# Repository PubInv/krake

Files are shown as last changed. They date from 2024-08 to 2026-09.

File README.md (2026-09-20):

<p align="middle">
  
   
</p>

# Krake™

## A wireless alarm device purpose-built for life's critical moments
The Krake, An Alarm Annunciator designed for easy integration into systems needing to bring to the attention of humans some condition. Can be used by professional system integrators and hobbyists.

This ?150? x ?180? x ?67? mm device has a speaker, a 20x4 character display, five white LEDs. It is a peripheral which can be controlled over a WiFi network using MQTT interface, a wired RS232 interface or a wired SPI interface with fully customiseable audio visual capabilitites. 

#### How it works?
1. A condition is detected by an external sensor that relays this information to Krake to trigger and alarm event. Such as a pressure sensor detecting the opening of a gate.
2. The Krake receives the information about the event wirelessly via MQTT over local network or internet. A gate open sensor on a security system would publish a message to the Krake via MQTT or direct RS232 connection
3. The Krake alerts you of this event-  Lights flash, audio plays and the message is displayed on an LCD for the user
4. The user is able to react to the alarm with {acknowledgement, dismissal, shelving or completion}, A mute button allows the user to temporarily mute the audio to prevent alarm fatigue.

## User Manual

A User Manual can be found [here](https://docs.google.com/document/d/1qrhc7Yi6PFmagl4gnvSoc0T4vC_uqu-NLrmWMKFnwA0/edit?usp=sharing).

## Table of Contents

- [Quick Start](#quick-start)
- [About Krake](#about-krake)
- [Example Use Cases](#example-use-cases)
- [Features](#features)
- [Hardware](#hardware)
- [Roadmap (Future Features)](#roadmap-future-features)
- [Contributing](#contributing)
- [Credits & Mentorship](#credits--mentorship)
- [Certifications](#certifications)
- [References & Further Reading](#references--further-reading)
- [License](#license)

## Quick Start
Once upon a time, we (Robert, Nagham and Lee) had envisioned that upon receiving a Krake the user would practice working with it by using the MQTT web page to publish messages to their device.

Purchasable from https://www.pubinv.org/shop/ 

User manuals & test and assembly procedure can be found in the references and further reading section 

#### LCD UI + navigation
 
Planned LCD Layout:

```text
Q:+ NEXT        W B M ⚙
CRIT Pump Failure
ID:123 Temp High
Ack  Dismiss  Shelve
```

Rotary Encoder: 
```text
Rotate: Navigate alarms or menu entries
Short Press: Select item
Long Press: Open Settings Menu
 ```

Alarm Actions:
```text
Rotatary encoder to enter action selection
Acknowledge, Dismiss or Shelve
 ```

Settings Menu: 
```text
The local settings menu includes:
* Volume Level
* Mute Duration
* COM Setup
* Device Reset
* Exit Menu
 ```
#### Build your own
To build your own please see instructions for testing and assembly of Krake hardware:
[Krake Test and Assembly Procedure Document](https://github.com/PubInv/krake/wiki/Krake-Test-and-Assembly-Procedure-Document)

## About Krake
The hope was to develop the initial design for a wireless alarm device to alert nearby parties of a particular state. 
About the name, Krake, the inspiration for the invention name is based on a Crake: a bird with a distinctive, slightly alarming cry. We changed the spelling so as to have a unique name and still preserve the humor. 

## Example Use Cases
Care at home: Alert an elderly person living alone to a fall or blood pressure drop — giving family peace of mind from anywhere.

Medical Equipment: For ventilators and critical devices, Krake provides a dedicated alarm channel for life-threatening mechanical failures.

IT Infrastructure: Alert on-site staff instantly when a server overheats, a UPS fails, or network connectivity drops — a physical alarm that doesn't rely on the very infrastructure it's monitoring.

## Features

| Feature | Details |
| --- | --- |
| Customiseable audio  |WAV and MP3 playback, Alarm-level-specific audio, Adjustable volume,SD-card-based audio storage, Busy-line monitoring and Runtime diagnostics |
| LCD User Interface & Rotary Knob | 20 x 4 I²C LCD interface integrated with a rotary encoder and custom menu system to navigate settings without the need for an external device.  Real-time alarm display, Wi-Fi status indication, MQTT broker status indication, Volume and mute display and Alarm acknowledgement actions |
| LED Annunciation  | Variety of LED levels  including steady or blinking deisgned to be visible across a room |
| Flexible Power | USB-C, 2.1mm center-positive barrel connector or RJ12 SPI interface power jumpers |
| Wi-Fi Connectivity | Acts as a Wi-Fi station connected to a local network enabling alerts locally or via internet, captive portal set up, storage of multiple Wi-Fi credentials, automatic reconnection, OTA firmware updates and Network status display |
| MQTT Protocol | MQTT alarm subscriptions, GPAP response publishing, Alarm acknowledgements, Alarm dismissal and shelving, Device monitoring, Configurable topic subscriptions and MQTT status display on LCD |
| Mute Button & time out handling | Configurable mute timeout, Automatic unmute, Manual mute override and LCD mute indication |
| HL7 Compatible | Designed to work with medical data standards |
| Fully Open Source | AGPL firmware, CERN OHL Hardware |
| Persistent COM configuration | Interfaces to external controllers through a DB9 Female RS-232 DCE connection. Configurable baud rate (1200,2400,4800, 9600, 19200, 38400, 57600, 115200), RTS/CTS hardware flow control and LCD-based configuration menu |
| Speaker | 3 inch 10W Full Range Round 8 ohm Speaker with FR:12-16KHz  |
| GPAP message parsing |  Alarm message are structured, message type, severity digit (0-5), optional message id, optional alarm type deisgnator and optional content up to 80 characters  |
| SPI alarm input support | ALlows processing of alert signals communicated or wired through SPI data lines to recognise fault or warning flags in connected sensors |  

## Hardware
| Krake™ rev2 | Krake™ rev1|
| --- | --- |
| |  |
| 3 inch 10W Full Range Round 8 ohm Speaker with FR:12-16KHz.| 28mm Speaker|
|dimensions|dimensions|
|functionality?|functionality?|

## Roadmap (Future Features)
* Advanced alarm queue management
* Enhanced LCD UI animations and icons
* Bluetooth and BLE alarm forwarding
* Mesh networking support
* Remote firmware fleet management
* Local event history logging
* Expanded GPAP/HL7 interoperability
* Power optimization modes
* Alarm escalation workflows

## Contributing
[Krake Workflow Contribution Procedure](https://github.com/PubInv/krake/blob/main/WorkflowProcedure.md)

## Credits & Mentorship
The Krake has been developed primarily by volunteer engineer Nagham Kheir, with mentorship and oversight from volunteer Inventional Coach Lee Erickson and a group of volunteers from around the globe. 

[Mentorship and Teamwork: The Story of the Krake](https://www.pubinv.org/2025/03/17/mentorship-and-teamwork-the-story-of-the-krake/)

Nagham Kheir: Invention Coach

Forrest Lee Erickson: Invention Coach

Robert L. Read: Invention Coach

Yehia Shalaby: Public Inventor

Courtney Ludick: Public Inventor

Yukti: Public Inventor

Juhandre Knoetze: Public Inventor

## Certifications



Krake hardware has been certified by the Open Source Hardware Association (OSHWA):
 OSHWA certification listing:
[OSHWA Certification Directory](https://certification.oshwa.org/list.html?utm_source=chatgpt.com)

Certification UID: ``` US002818 ```
 
## References & Further Reading

Brochure: [Copy of Krake Brochure.pdf](https://github.com/user-attachments/files/29981489/Copy.of.Krake.Brochure.pdf)

Logo: KRAKE 2

Krake Repo: https://github.com/PubInv/krake

Wiki: https://github.com/PubInv/krake/wiki

HardwareX Article: [ TBD]

User Manual: [draft user manual](https://docs.google.com/document/d/1qrhc7Yi6PFmagl4gnvSoc0T4vC_uqu-NLrmWMKFnwA0/edit?usp=sharing) 

Developers Manual: [draft developers manual](https://docs.google.com/document/d/150WA6Mb1_SFOBmFc9qBpT5b-MqXb7ejaZbKIxUqaDBY/edit?usp=sharing).

OSHWA certification listing:
[OSHWA Certification Directory](https://certification.oshwa.org/list.html?utm_source=chatgpt.com)

The team behind Krake: [Mentorship and Teamwork: The Story of the Krake](https://www.pubinv.org/2025/03/17/mentorship-and-teamwork-the-story-of-the-krake/)

Krake workflow: [Krake Workflow Contribution Procedure](https://github.com/PubInv/krake/blob/main/WorkflowProcedure.md)

Build your own: [Krake Test and Assembly Procedure Document](https://github.com/PubInv/krake/wiki/Krake-Test-and-Assembly-Procedure-Document)

Global Open Source Quality Assuring System:[Asset History Records Public Invention Krake Rev. 2](https://gosqas.org/record/8CMgkfrS4ufevweKy1QowF)

GPAP:  https://github.com/PubInv/gpap

#### Public Invention

- Github repo: https://github.com/PubInv
- Website: https://www.pubinv.org/
- Products page: https://www.pubinv.org/shop/

## License
Firmware: GNU Affero GPL 3.0

Hardware: CERN Open Hardware Licence Version 2 - Strongly Reciprocal

Krake™ is a trademark of Public Invention.

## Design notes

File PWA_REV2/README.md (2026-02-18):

# Summary
The Krake Rev 2 PWA fixes a major problem with the CH340 USB to UART feature of Rev 1 which was missing a crystal from the PCB and could not work.

## Document Descriptions
for some selected documents in this folder.  
The Rev2 PWA [Krake_Test_and_Assembly_Procedure.md](https://github.com/PubInv/krake/blob/main/PWA_REV2/Krake_Test_and_Assembly_Procedure.md)

## References
Link to issue capturing the order from PCBWay of PWA subassemblies.  
Link to issue capturing the order from other vendors of balance of BOM for PWAs.

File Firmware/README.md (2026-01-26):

# Summary 
These files are for firmware (for the most part into ESP32).
The GPAD_API is the firmware which will ship in the Krake.
Other files are for factory test / troubele shooting or were developed during to evaluate and understand hardware.

## Userfull link for compairing firmware branches
Jump to compareing on Github various commits.
https://github.com/PubInv/krake/compare

## Arduino IDE Settings and Libraries to Install
The IDE setting for board should be set to "ESP32 Dev Module".

Although we are migrating to VSCode and PlatformIO, For developing Firmware with the Arduino IDE the following libraries are required.
A number of libraries must be installed.  This is an incomplete list:
* ElegantOTA v. 3.1.7 by Ayush Sharma
* ESP AsyncWebServer by ESP32Async
* Async TCP by ESP32Async

(There are many other more common libraries.)

## Caution, Must Modify a Library
We use the Random Nerd Tutorials tutorial: [https://randomnerdtutorials.com/esp32-ota-elegantota-arduino/](https://randomnerdtutorials.com/esp32-ota-elegantota-arduino/) which gives instructions for changing 
the value of ELEGANTOTA_USE_ASYNC_WEBSERVER in ElegantOTA.h.

This value needs to be set to 1:
```
// WARNING! HACK FROM RANDOM NERD
#define ELEGANTOTA_USE_ASYNC_WEBSERVER 1

#ifndef ELEGANTOTA_USE_ASYNC_WEBSERVER
  #define ELEGANTOTA_USE_ASYNC_WEBSERVER 0
#endif
```

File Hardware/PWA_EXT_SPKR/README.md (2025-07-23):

# Summary
A printed wiring assembly for adding an external speaker jack to the Krake.

## Requirements Details.
See issue https://github.com/PubInv/krake/issues/231 (Hardware, Add External Speaker Jack (phone jack), 3,5mm, Switch ) for additional history on how these requirements evolved.

- A PWA which has a 3.5mm phone jack with switched signals.
The KRAKE audio output at J601 is connected into the PWA_EXP_SPK assembly on a 1.27mm JST connector.
When no 3.5mm plug is inserted into the jack, audio is available on an input 1.27mm JST connector for connection to the Krake internal speaker
The assembly is mounted to the Krake jack panel by the panel mount nut of the 3.5mm phone jack.

- Design For Manufacture
Design for manufacture by JLCPCB and PCBWAY.

## Impact On Other Assemblies
- **Front Panel Impact:** The Krake jack panel ?front panel? Must be modified by adding a 6mm hole (with clearance allowance) into which the 3.5mm phone jack will mount.
- **Internal Speaker:** Locate the speaker so that the leads that come with the speaker are long enough, OR build an extension cable assembly to connect to the speaker, OR extend the speaker wires.

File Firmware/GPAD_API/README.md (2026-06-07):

# Building

## PlatformIO IDE (Visual Studio Code Extension)
1. Install the Visual Studio Code (VS Code) text editor
    - [Website](https://code.visualstudio.com/)
2. Install the [PlatformIO](https://marketplace.visualstudio.com/items?itemName=platformio.platformio-ide) VS Code extension
    - The provided link has instructions on how install the extension in VS Code
3. The PlatformIO project needs to be opened
    - Click the PlatformIO logo/extension on the left tool bar
    - Under the `QUICK ACCESS > PIO Home` section, selection `Projects & Configuration`
    - At the top, select `Add Existing` and select this directory
4. To compile, select the PlatformIO logo/extension on the left again if it is not still selected
    - Under `esp32dev > General` select `Build` and the firmware image will be built
    - There are additional options for uploading the firmware to the device and monitoring

## PlatformIO from Command Line

Some users prefer not to use VSCode (those who prefer Emacs, Vim, subtext, etc.)

### PlatformIO Core (CLI) Installation
The official [documentation](https://docs.platformio.org/en/latest/core/installation/shell-commands.html#piocore-install-shell-commands) 
has great guide on how to install the CLI tooling. [Here](https://docs.platformio.org/en/latest/core/userguide/index.html#piocore-userguide)
is PlatformIO's guide on how to use the CLI command `pio`. The full guide for PlatformIO Core installation is available [here](https://docs.platformio.org/en/latest/core/installation/index.html). 

As the documentation says, you **do not** have to follow all steps in the CLI guide if you have **also** installed the VS Code extension, PlatformIO IDE. It will be advised to follow the directions under the documentation for "Install Shell Commands" to be able to run the commands `pio` and `piodebuggdb` anywhere in the terminal. For the `Makefile`
mentioned below, it is required to install the shell commands for the `make` command to function correctly.

### Build
In this directory, there is a `makefile`. If you have `make` installed, run `make` or `make build` to compile the firmware without requiring a connected device. The available targets are:

1. `build` --- compiles the firmware image. This is the default target used by `make`.
2. `upload` --- compiles and uploads the firmware image to a connected device.
3. `run` --- uploads the firmware image and begins running a monitor, which prints serial output and allows commands to be typed in, just as in the Arduino IDE.
4. `monitor` --- runs the serial monitor without uploading a new firmware image.

These commands are implemented on the command line as:

```
    make
    make build
    make upload
    make run
    make monitor
```

# Building LittleFS Filesystem
With PlatformIO, the creation of the `LittleFS` is a separate step from building the firmware image. However, it only has to be built if
there have been changes to the `/data` directory and it only has to be uploaded to the device if the the image has changed or the flash
pages containing the file system have been erased.

## PlatformIO IDE (VS Code Extension)
In the extension side panel, below the `General` section with the `Build` and `Upload` targets, there is another section, `Platform`. Under
the `Platform` section, there are the `Build Filesystem Image` and `Upload Filesystem Image`. Using the `Upload Filesystem Image` target will
build and upload the file system if the file system needs building.

## PlatformIO Core (CLI)
The full command is `pio run --target uploadfs` but the `Make` target `make uploadfs` can be used.

# Krake Installation
Installing/flashing a new firmware image requires the device, Krake, to be set into a state for it to allow a new firmware image. That can be accomplished with the following steps:
1. Connect Krake to power and to the computer
2. Press and hold the BOOT button.
3. While still holding BOOT, press and release the RESET button once.
4. Release the BOOT button.
5. The chip is now in boot mode. You can run your flasher and the port should respond.

# Runtime Connectivity and SPI Broker Mirror
WiFi credentials remain stored until explicitly cleared. Developers can clear saved WiFi credentials from the LCD `Developer Mode` menu or from the served settings page; the device then restarts into its normal WiFi setup flow.

Every topic/payload pair queued for MQTT publication is also queued independently for transmission from the Krake ESP32 VSPI controller. This keeps the local SPI output available even when WiFi or MQTT is offline. The controller uses a 1 MHz, MSB-first, SPI mode 0 link with `SCLK=18`, `MISO=19`, `MOSI=23`, and chip-select `SS=15`. Each transfer is one frame:

```
"KRK1" | retain byte | topic length byte | payload length byte | topic bytes | payload bytes
```

The built-in LED retains its heartbeat and adds connection indicators: two short winks after WiFi connects and three short winks after MQTT connects.

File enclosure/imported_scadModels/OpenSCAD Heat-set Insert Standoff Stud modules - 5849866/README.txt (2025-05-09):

OpenSCAD Heat-set Insert Standoff Stud modules by RonRN18 on Thingiverse: https://www.thingiverse.com/thing:5849866

Summary:
This is a collection of modules for OpenSCAD that will create different-sized standoff studs with holes for a heat-set insert to be placed into them. I have created modules for various sizes of standoff studs. I am still very new to OpenSCAD. While it has been around for many years, I first heard about it exactly one week ago. For the type of projects that I work on, and the way my brain works, this appears as though it will be much easier for me to design with as compared with the commercial product Fusion 360 that I started out with.Many of my designs are for cases to hold electronic projects, so I will need to create designs for holding circuit boards that have screw holes in a variety of places. To make installing, removing, and replacing parts easier, I like using these brass, heat-set, threaded inserts. Depending on the project, some times I need tiny little M2 screws and other times I may need a screw up to an M5. Each hole for an insert has an 8° tapered edge, to facilitate lining up each insert. The depth of each hole and the diameter of each stud varies based on what insert that is used. For this reason, I recreated several iterations of these standoff studs for the different sizes. Below are a list of the modules I've created.M2.0 ShortM2.0 LongM2.5 ShortM3.0 ShortM3.0 LongM4M5I may find a need later to create more sizes. If you open up the OpenSCAD file, you will see that I’m a bit verbose, but I explained how and why I did things the way I did.To call up one of the modules, you would use the following syntax:m3_long_stud(x-axis, y-axis, height of stud, offset from surface);The following is an example of this syntax:m3_long_stud(0,0,7.8,0);This places an M3 Long stud that is 7.8mm tall at 0,0,0. The values for each of these inserts were extrapolated from several different sources but mostly from Maker Tech Store and McMaster-Carr. Maker Tech Store provided better information on each of the inserts that they sell. Their only issue is they only sell some sizes. McMaster-Carr carries a larger variety but their information is a bit disjointed, often mixing imperial measurements with metric, like using a hole that is 0.199 inches for an M3 insert. Maker Tech Store explains it in details and provides an image to understand.

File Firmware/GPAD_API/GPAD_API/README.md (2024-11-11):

# GPAD_API
Description of the GPAD API, the Application Programming Interface.
Version 0.07
Updated on Date: 20221104

This is the description of the API from the point of view of the firmware within the General Purpose Alarm Device, aka the GPAD.

As of Version 0.07, the interface is through the USB serial and SPI, both. 
The serial BAUD rate is fixed at 115200
Serial messages are terminated with a single **Line Feed**, here after LF character (aka '/n' or New Line, which is ASCII 0x0A or DEC 10).
The GPAD recognizes a limited set of commands.
Some commands are one character only.
Some commands are two characters followed by the LF.
Some commands take messages by concatenating a message of up to 80 additional ASCII characters.

## The SPI Interface

The SPI interface was added in version 0.07, and example code for it is available in the GPAD_API_SPI_CONTROLLER directory. Please see the [README](https://github.com/PubInv/general-alarm-device/tree/main/Firmware/GPAD_API_SPI_CONTROLLER) there for more information.

This SPI-implemented is implemented with two entrypoints, the single funcation ```alarm```, and the function ```alarm_vent``` which takes and event structure. These may contain a null-terminated message string of up to
80 characters.
```C++
enum AlarmLevel { silent, informational, problem, warning, critical, panic };
// const char *AlarmNames[] = { "OK   ","INFO.","PROB.","WARN ","CRIT.","PANIC" };
const int NUM_LEVELS = 6;

const int MAX_MSG_LEN = 80;
const int MAX_BUFFER_SIZE = MAX_MSG_LEN + 1;
typedef struct {
                uint8_t lvl;
                // we will use a null-terminated string!
                char msg[MAX_MSG_LEN+1];
               } AlarmEvent;

int alarm_event(AlarmEvent& event,Stream &serialport);
int alarm(AlarmLevel level,char *str,Stream &serialport);
```

It is our intention to create additional entry points in what we call the "robotic_api" which will eventually explose all of the GPAD hardware to control by SPI.

## Display Description
The LCD is organized as four rows of twenty characters.
The first row displays the alarm level by number and name { "OK   ","INFO.","PROB.","WARN ","CRIT.","PANIC" }
The remaining rows display the message sent by the controller with commands detailed below.

## Command List
Summary:
Commands fall into categories of **Alarm** and **Mute** and a **Help** message.
Optional arguments are in [].
Commands are case-insensitive. **A0** and **a0** are the same.

### Alarm Messages
These have the form of a letter "A" and a digit 0-5 inclusive followed optionally by text for the message.
* A0[message for alarm level 0]
* A1[message for alarm level 1]
* A2[message for alarm level 2]
* A3[message for alarm level 3]
* A4[message for alarm level 4]
* A5[message for alarm level 5]

In addition to Alarm messages writing text to the LCD, the illumination of the five LEDs is also managed.  A0 lights no LEDs, A1 through A5 light successively more LEDS vertically up the GPAD.
There are fixed buzzer tones associated with each alarm level, A0-A5
The "A0" alarm level turns off the LCD back light.  All other levels turn on the LCD back light.
Some example alarm messages:
> a0 pseudoSerialVent Testing.  All is OK.
> a0Uh, everything's under control. Situation normal.
> a5LUKE, WE'RE GONNA HAVE COMPANY!

### Mute Messages
The GPAD has a buzzer which can be silenced or Muted by the API. (The user can also press a button to manage the mute state).
Mute messages are single character messages terminated by LF.
* S
* U

The S command **Silences** or mutes the buzzer.
The U command **Unmutes** the buzzer.

### Help
* H

The **H** message is single character messages terminated by LF.
The device will return a message out the serial port with help instructions.
Screen shot of the help message.


## Command Response and Status
After the GPAD receives a command, it returns text string with a response indicating status.
Example of response to the command "a0 pseudoSerialVent Testing.  All is OK."


## GPAD MUTE BUTTON
The GPAD has a mute button. Pressing the button will toggle the buzzer on and off.
Text is returned out the serial port indicating the MUTE status as OFF or ON.


# Software Organization

The files in the directory are organized to create as much modularity as possible
to make future enhancement easy. At present these are:

> alarm_api.cpp
> alarm_api.h
> gpad_serial.cpp
> gpad_serial.h
> gpad_utility.cpp
> gpad_utility.h
> GPAD_HAL.cpp
> GPAD_HAL.h

The "alarm_api" module is main application programmers interface; it is a very
high-level abstract alarm module.
The "gpad_serial" module handles serial communication of the alarm commands.
The "gpad_utility" contains mostly debugging routines needed by all other modules.
The "GPAD_HAL" is a low-level api concerning the specific API. It is means to
change more rapidly as the hardware evolves than the "alarm_api".
At the time of this writing I will shortly add an "spi" module

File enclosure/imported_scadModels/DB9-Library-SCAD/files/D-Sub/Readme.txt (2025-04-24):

D-Sub Library for OpenScad
--------------------------

Introduction
-------------

This library is designed as an easy way to cut out D-Sub connectors by simply adding width of the connector. I didn't like how some people use rectangular cutouts for Db-9 connectors and wanted to have an actual proper shape for aesthetic and practical reasons. I took the opportunity to learn a bit about OpenScad while making something useful.

Install
-------

Simply drag and drop the file into "libraries" folder in OpenScad or drag and drop the code into the code window.

Using This Library
--------------------
This libary ads a module called "dsub" that contains 3 parameters in this order: "Scale", "Connector Size", "Hight"

The scale will likely need to be made a little bigger to allow for different housings especially if your connector is female. 1.1 works well for db9 and 1.05 for db25. These are the only connectors I have on hand and those are what I tested. The connector size must corrolate to the largest width of the connector. See the chart below for some sample sizes. VGA and RS232 are DB-9/ HD DB-15 while Parallel ports are DB-25:

DB-9/HD DB-15 -- 17.04
DB-15 -- 25.37
DB-25 -- 39.09
DB-50 -- 52.93

Below is a fast poorly written script to test it.

include <dsub.scad>

difference(){
translate([-8,-20,1]){
    cube([20,100,3]);
}
dsub(1.1,17.04,10);
translate([0,50,0]){
    dsub(1.05,39.09,10);
}
}

Other Info
-----------

For more information on D-Sub conectors you can find a pretty good link below. I didn't create this site but found it useful in writing this script.
 
http://www.interfacebus.com/Connector_D-Sub_Mechanical_Dimensions.html

Warranty & License 
---------

This script is provided without any warranty and the user takes full responsability for it's use. This script is public domain.

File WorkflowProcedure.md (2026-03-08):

# Krake 
## Workflow

## Goals

* Every change is traceable to an issue.
* Small, reviewable branches.
* Clear validation (code or non-code).
* Works on both Windows and macOS.

## 0) One-time setup (Windows & macOS)

**Install Git**

* **Windows:** Install “Git for Windows” (use **Git Bash**), include **Git Credential Manager**.
* **macOS:** `xcode-select --install` (or `brew install git` if you use Homebrew).

**Configure Git**

```bash
git config --global pull.rebase true
git config --global fetch.prune true
git config --global init.defaultBranch main
git config --global user.name "Your Name"
git config --global user.email "you@example.com"
```

**Line endings (important cross-platform)**

* **Windows (Git Bash):** `git config --global core.autocrlf true`
* **macOS/Linux:** `git config --global core.autocrlf input`

**Clone**

```bash
git clone https://github.com/PubInv/krake.git
cd krake
git remote -v
```

> Use **Terminal** (macOS) or **Git Bash** (Windows). VS Code’s built-in terminal works on both.

## Roles

* **Mentor:** creates & assigns issues, reviews PRs, **merges**.
* **Contributor (Volunteer):** works **only** on assigned issues, opens PR, updates per review.
* **Maintainer:** sets repo guidelines (branch protection, labels, templates, CODEOWNERS).

 -----

## 1) Issues 
* Mentors create & assign issues to contributors.
* Each issue includes:

  * **Goal & Acceptance criteria**
  * **Deliverables** (e.g., STL/STEP, schematic PDF/BOM diff/DRC, docs, scripts, code)
  * **Validation method** (how we verify—simulation, screenshots, photos, logs, ERC/DRC/print-fit, etc.)
* Contributors can create issues and assign them to mentor(s) at any time. However, the mentor or team lead should set priorities, and therefore should assign issues to contributors most of the time (contributors may complete obvious issues if it makes sense by assigning the issues to themselves). 

### Issue Criteria (for when a contributor is creating an issue)

issue [type]: Firmware, Enclosure, Documentation... 

## 2) Create a branch (from `main`)

Navigate to the issue in Github and use the user interface to create a branch, by scrolling the Development section.



### Branch Naming
**Naming:** `type/issue-<number>-short-slug`
Types: `feature`, `bugfix`, `docs`, `cad`, `pcb`, `chore`, `refactor`

Then locally: 

```bash
git fetch origin
git checkout -b cad/issue-312-speaker-mount-v2 origin/cad/issue-312-speaker-mount-v2
```

## 3) Work locally  

Keep commits small and focused.

**Commit message style**

* For code: Conventional Commits
* For CAD/PCB/docs: plain but specific is fine

Examples:

```
cad(enclosure): add 2mm standoffs for DFPlayer (#312)
pcb(audio): reroute SPK +/- to reduce crosstalk (#287)
docs(factory-test): clarify rotary encoder checklist
```

**Artifacts & folders**

* Put source and **exported, viewable** artifacts together (e.g., PDF/PNG for schematics, STL/PNG for CAD).
* Typical folders: `firmware/`, `hardware/enclosure/`, `hardware/pcb/`, `docs/`.

Push often:

```bash
git add -A
git commit -m "cad(enclosure): add 2mm standoffs for DFPlayer (#312)"
git push
```

> Validation can be **anything appropriate**: screenshots, DRC/ERC reports, test photos, simulation results, print fit notes, logs, etc. We don’t assume a build/compile exists.

## 4) Open a Pull Request (Contributor)

On GitHub:

* **Title:** What changed + issue number
  e.g., “Enclosure: add 2 mm standoffs (Closes #312)”
* **Description must include:**

  * **What & why**
  * **Validation steps** (how to verify)
    *Examples:* “ERC/DRC screenshots attached”, “Print test part A—fits DFPlayer with 1.5 mm clearance”, “Photo of assembled prototype”, “Serial log shows expected event”
  * **Artifacts attached** (PNGs/PDFs/STLs/log snippets)
* **Link issue:** `Closes #<n>`
* **Reviewers:** your **mentor(s)** only
* **Labels:** match the issue (`cad`, `pcb`, `docs`, `firmware`, etc.)

**PR checklist (paste into PR):**

## PR Template: 

```

## Links
- [ ] Closes #<issue>

## What & Why
-

## Validation / How to Verify
1.
2.

## Artifacts (attach if relevant)
- [ ] Screenshots / PDFs / STLs
- [ ] Logs

## Checklist
- [ ] Only related changes
- [ ] Folder structure respected, work directory. 
- [ ] Validation steps written
```

Use **Draft PR** if not ready.

## 5) Review & iterate

* Mentor reviews, requests changes or approves.
* Add follow-up commits; **don’t force-push** unless mentor asks.
* Resolve comments with “Fixed in `<short-hash>`” or rationale.

## 6) Merge (mentor-only)

* Only a **mentor** merges.
* **Strategy:** **Squash & merge** to keep history clean/complete.
* After merge: branch deleted, issue auto-closes via `Closes #<n>` (close manually if needed).

## 7) Sync after merge

```bash
git checkout main
git pull
git fetch --prune
```

## 8) Hotfixes (urgent)

* Branch from `main`: `hotfix/issue-<n>-slug`
* Same PR/review flow; mentor merges once validated.

---

## Branch protection for `main`

**What:** Rules that prevent direct pushes and enforce quality gates before merging.

* Restrict deletions
> Only allow users with bypass permissions to delete matching refs.

* Require a pull request before merging
> Require all commits be made to a non-target branch and submitted via a pull request before they can be merged.
> Require **1 approving reviews** (mentors)

* Block force pushes
> Prevent users with push access from force pushing to refs.

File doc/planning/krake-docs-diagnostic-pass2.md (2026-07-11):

# Krake Documentation — Second-Pass Diagnostic Analysis

> **Relationship to pass 1:** this is a direct continuation of `krake-docs-diagnostic-pass1.md` (see that file's permalink in the team's GitHub issue for the original). It incorporates: the switch from the abandoned LaTeX Test and Assembly Procedure Document to the current GitHub-native Markdown version, all fact-conflict resolutions reached since pass 1 (PWA/enclosure dimensions and mass, PCB Rev 2.0 / PWA Rev 2.1 naming convention, journal name confirmation), and new findings surfaced by reviewing the current Markdown Assembly doc directly. Items marked **RESOLVED** below were open questions in pass 1 and are now settled; items still open are unchanged or newly added.

> **Correction incorporated in this pass:** the original pass 1 analyzed the LaTeX/Overleaf version of the Test and Assembly Procedure Document, which the team has since confirmed was **abandoned** in favor of a GitHub-native Markdown document. This pass replaces that source and re-checks every finding that touched it. The old LaTeX doc should not be treated as authoritative for anything going forward.

**Sources reviewed:**
1. GitHub README.md (`PubInv/krake`)
2. Krake™ User/Operator Manual v0.1 (Google Doc)
3. Krake™ Developer's Technical Manual v0.1 (Google Doc)
4. HardwareX article draft (Overleaf, LaTeX)
5. **Krake Test and Assembly Procedure Document v0.2.0** — `PWA_REV2/Krake_Test_and_Assembly_Procedure.md` on GitHub (`main` branch) — ~~formerly the Overleaf LaTeX version, now abandoned~~

This is a diagnostic pass only — no rewriting yet. Goal is to surface conflicts, gaps, and structural
issues so we can agree on a fix order before touching prose.

---

## 1. Fact conflicts requiring a team decision

These are places where two or more documents state something different, and only the team can say
which is correct.

| Item | Source A | Source B | Notes |
|---|---|---|---|
| ~~**Physical dimensions**~~ **RESOLVED** | Developer Manual: "160mm x 110mm x 50mm (6"x4.25"x1.75"), weighs 232 grams" | HardwareX §7.3: "weighs less than 740 grams. Dimensions are: 150 x 180 x 90 mm" | **Not a documentation error — two real hardware states.** The 232g/160x110x50mm figure describes the **Rev1** enclosure with a 28mm speaker (too quiet, since retired). The Rev2 enclosure was enlarged to fit a 3" speaker for adequate volume, raising both size and mass. **Confirmed current Rev2 measurements (re-measured for parallax error): enclosure body 150mm x 180mm x 67mm, mass 742g; overall depth at the rotary encoder knob is 78mm.** HardwareX's "90mm" was an early rough estimate — supersede with 67mm (body) / 78mm (at knob). **Action:** Developer Manual should carry the Rev2 figures as current spec; the Rev1 232g figure should only remain if explicitly labeled historical/reference-only per the team's rev1 policy. |
| ~~**Power draw**~~ **RESOLVED — not a conflict, different purposes** | Developer/User Manuals: "9-12VDC... less than 500 mA and typically 250mA (less than 6 watts)" — this is a **purchasing spec** for the external wall-wart power supply an end user or integrator needs to buy. | Assembly Doc: bench supply set to 8–12V, current limit <1A, typical measured draw **150–190 mA** at 8.3–8.4V — this is a **test-bench setup spec**, deliberately run near the minimum voltage the onboard regulators need, accounting for regulator headroom and the drop across the reverse-polarity protection diode. | **Not a discrepancy to reconcile — two different documents answering two different questions**, so the numbers don't need to match and shouldn't be forced to. **New action item:** the Assembly doc's bench-supply setup step doesn't currently explain *why* the minimum test voltage is set where it is. Worth adding a short explanation there (regulator headroom + reverse-polarity diode drop) so a technician understands the rationale, not just the number — this also protects against someone "helpfully" changing the test voltage in a later revision without understanding why it's set near the floor. |
| **Firmware version** | README: firmware at **v0.50.0** | Developer Manual screenshot: `GPAD_API 0.19_20241119` | Big gap (0.19 vs 0.50.0). Developer Manual example is clearly stale and needs a refreshed screenshot/output. |
| ~~**PCB revision**~~ **RESOLVED, and partially already fixed** | Assembly Doc §4 (Definitions) **already defines PCB vs. PWA correctly**: "PCB: ...to which electronic components are NOT yet attached" / "PWA: ...a PCB with components soldered/attached." Good — this matches the team's agreed convention below, no work needed there. | **However, the inconsistency in applying that distinction persists in the current Markdown doc**, not just the old LaTeX one: the "Unpacking" section says "Confirm PCB is marked as **Rev 2.0**," while "Incoming Sub-assembly Inspection" (a few lines later, same doc) says "Confirm PCB is marked as **Rev 2.1**." The top-level doc title is also still "Krake: PCB Rev 2.1," and body text says "This article focuses on the **Rev 2.1 PCB**..." — which directly contradicts the agreed PCB 2.0 / PWA 2.1 convention. | **Team convention (confirmed):** **PCB Rev 2.0** = the bare board actually fabricated (design started ~Aug 2025, populated Jan 2026 batch). **PWA Rev 2.1** = PCB Rev 2.0 + enclosure + speaker + cable assembly + label — the complete assembled/tested unit. PCB Rev 2.1 (in-progress silkscreen/BOM refinement) has **not been released** and should not appear as describing built hardware. **Action, still open:** the Assembly doc's title, its "This article focuses on the Rev 2.1 PCB..." line, and the "Confirm PCB is marked as Rev 2.1" instruction all need to change to reflect PCB 2.0 / PWA 2.1 — the definitions are already in the doc, they're just not applied consistently yet. Same fix needed in the HardwareX draft's build section (see new item below on HardwareX build-section staleness). |
| **Unit serial range tested** | HardwareX §1: batch described as **US0006–US00015, LB0006–LB00011, LDN0001–LDN0005** | The current Markdown Assembly doc **does not state a specific serial range** in the sections reviewed — this appears to have dropped out rather than contradicted. | No longer a cross-document conflict, but still an open question: does the HardwareX-stated batch range reflect the units actually referenced by the current procedure doc? Worth confirming before submission. |
| **Powered TP102 (Vin) reading** | Confirmed still present, unchanged, in the current Markdown doc's powered-test results table: "TP102 | ~4.5V" | The 8.3–8.4V bench supply and other readings suggest ~4.5V is anomalously low for this rail. | Not a copy artifact from the abandoned LaTeX doc — this is a live number in the current, authoritative procedure. Worth double-checking with whoever ran that test batch. |
| **Author list (Assembly/Test doc)** | Current Markdown doc lists **three authors**: Forrest Lee Erickson, Nagham Kheir, and **Courtney Ludick** (added since the abandoned LaTeX version, which listed only Erickson and Kheir) | HardwareX draft lists **six authors**: Nagham Kheir, Robert L. Read, Forrest "Lee" Erickson, Courtney Ludick, Juhandré Knoetze, Yhya Ayman | Closer alignment than before, but still not identical — confirm whether the Assembly doc's list is meant to be a subset (contributors to that specific document) before finalizing the CRediT statement. |
| **Internal date typo (new finding)** | Assembly doc's ISO title page block: "Date: **2027 - 02 - 08**" | Same document's Revision History table: v0.2.0 dated **2026-02-08** | Almost certainly a typo (2027 vs 2026) in the ISO title page block. Easy fix, worth catching before publication. |
| **Ordering price** | Developer Manual: "approximately $200USD," contact Robert Read directly | Not mentioned in README or HardwareX | Confirm this is still current before it goes in a permanent, indexed HardwareX article. |
| **OSHWA certification UID** | HardwareX specs table: `US002818` | Not mentioned in README, User Manual, or Dev Manual | Should probably be surfaced in the README and User Manual too, since it's a credibility signal for new visitors. |
| **Trademark usage** | User/Dev Manuals: consistent "Krake™" | README / HardwareX: plain "Krake," no ™ | Needs a house-style decision (see §3). |

---

## 2. Structural / completion gaps

**New finding (missing content, not a conflict): VESA mount and mounting orientation are undocumented.**
The enclosure has a **75×75mm VESA MIS-D mount** feature on the back (referenced only implicitly, as "VESA and Speaker Mount" threaded inserts, in the Assembly doc's Enclosure Assembly Procedure — never explained as a user-facing feature anywhere). None of the User Manual, Developer Manual, README, or HardwareX draft mention it. This is a real gap, not a drafting error, and it has a usability/safety dimension:
- The existing "Enclosure / Device Mounting" sections (User Manual, Developer Manual) describe a central mounting hole, side picture-hanging holes, and zip-tie flanges — but never the VESA pattern, and never state that the Krake is designed for **vertical surface mounting only**.
- Cables exit from the panel a user would likely perceive as the "bottom" (the side perpendicular to the LCD/front face) — which is not an obvious consequence of the design and isn't called out anywhere.
- **Action:** add a mounting-orientation **safety/best-practice note** — not just a spec line — to the User Manual and Developer Manual mounting sections: name the **75×75mm VESA MIS-D** pattern explicitly, state that the Krake is designed for vertical surface mounting only, and warn against setting the unit flat on a horizontal surface, since cables exit from that face and the enclosure isn't designed to bear load or rest stably on it.

**HardwareX article** — this is the least finished document and has the most template debris:
- The Abstract section still contains **unresolved editor/reviewer comment text** bleeding into the visible body (e.g., stray fragments like "not in template," "graphical abstract," mid-sentence interruptions). This reads as corrupted or improperly-resolved tracked changes/comments from Overleaf/Word round-tripping, and needs a clean rewrite pass before anything else in that document is touched.
- Several section headers still contain the **unmodified HardwareX instructional text** ("Write a short description...", "Add 3–5 bullet points...") mixed in with actual content — a sign these sections were drafted directly into the template without deleting the prompts.
- **Ethics statement, CRediT statement, Acknowledgements, References, "Useful References," Design Files table costs** are explicitly marked TBD, placeholder, or contain obvious placeholder values (e.g., BOM costs listed as `1000000` for the enclosure and PCB — clearly a formatting artifact, not real costs).
- §7 (Validation) has three subsections (Sound/Light, Electrical Parameters, Physical Parameters) that are almost entirely TBD, tagged to specific people ("TBD: Lee," "TBD: Lee, Courtney").
- The reference to "the Krake, the Zetron SentriMax" comparison seems to have an editor comment ("Missing is a comparison...") embedded directly in the body text.

**Developer Manual:**
- Multiple `TBD` and `????` placeholders in the Wireless Connection section (default password, exact button to hold for WiFi Manager, etc.) — this is core setup instructions for a real user, so these gaps block someone from actually using the device.
- "Communicating with the Krake" section literally says "TODO: Write this section in reference to the diagram below" — the diagram exists but the explanatory text was never written.
- Python MQTT example section says "TO BE DONE: NAGHAM ADD PYTHON CODE HERE."
- SPI Interface connector type is marked "TBD."
- Note this manual is dated/versioned as v0.1 — it may be the least mature of the four, other than the HardwareX draft.

**User Manual:**
- Shares roughly 70% of its content verbatim with the Developer Manual (Wireless Connection, Mute Button, Rotary Encoder, Ordering sections are nearly identical). This isn't necessarily wrong — some overlap is expected since they share an audience for some topics — but right now it looks like duplication-by-copy-paste rather than an intentional shared-content strategy. Worth deciding: cross-reference instead of duplicate, or keep parallel but ensure they never drift again.
- Same `????` and TBD gaps in the WiFi Manager section as the Developer Manual (since it was copied from there).

**Assembly & Test Procedure Document (now on `main`, `PWA_REV2/Krake_Test_and_Assembly_Procedure.md`):**
- **This is a materially more advanced document than what was in the abandoned LaTeX version**, and more advanced than what's reflected in the HardwareX draft's embedded build section. New content not present anywhere else includes:
  - A full **Factory Test Procedure** with a structured hex-menu test suite ([0]–[F]: Power/ID, Inputs, LCD, LEDs/Lamps, DFPlayer, SD, Speaker, Wi-Fi AP, Wi-Fi STA, LittleFS, UART, SPI loopback, RS-232 loopback, **ElegantOTA**, Mute Button+LED) — this supersedes the old, much simpler "enter 4-5-6 into the serial monitor" test flow.
  - A complete **Enclosure Assembly Procedure** (3D-printed part list, threaded-insert installation, full step-by-step mechanical assembly) that doesn't exist in the HardwareX draft or the old LaTeX doc at all.
  - Real BOM costs (e.g., PCB $35/5, subassembly $217/5) replacing the old placeholder values (`1000000`) — the HardwareX draft's BOM table should be checked against this and updated, since it still likely has the placeholder figures.
  - A firmware update workflow via **ElegantOTA** (`.bin` upload) replacing the old direct-flash-only description.
  - Reference to a live GitHub Issue (#274) for firmware library specifications — a good sign of the team already using issues for exactly this kind of drift control.
  - A third author, Courtney Ludick, credited on the document (see fact-conflict table above).
- Still carries **ISO template scaffolding** at the top (Background, Results/Discussion, References, Appendix headers) that remain unfilled — same issue as before, not yet resolved by the update.
- Revision history table still has a `YYYY-MM-DD [Author Name]` placeholder row for the future v1.0.0 "Finalized for publication" entry.
- Ends abruptly with "Ethics statements / CRediT / Acknowledgements / References — To be completed" — same as before.
- **Still has the PCB Rev 2.0/2.1 inconsistency** discussed above, even in this updated version — the definitions in §4 are correct, but the applied labels in the body aren't consistent with them yet.
- **New, higher-priority finding: the HardwareX draft's embedded Build Instructions section is now significantly more out of date than previously assessed.** It was already showing signs of drift from the old LaTeX Assembly doc; now that the real procedure has moved to a substantially expanded, GitHub-native document, the gap is much larger — entire sections (Factory Test menu, Enclosure Assembly, ElegantOTA workflow) exist only in the Markdown doc and aren't reflected in the HardwareX draft at all. **Recommendation: when we get to the HardwareX Build Instructions section, treat it as needing significant new content pulled in from the current Markdown doc, not just a terminology/label fix.**

**README:**
- Most current and complete-feeling document. Good candidate as the "source of truth" for high-level facts (firmware version, feature list, licensing) that other docs should defer to or link to rather than restate.

---

## 3. Voice, terminology, and style drift

- **Trademark symbol**: User/Developer Manuals use "Krake™" consistently; README and HardwareX draft do not. Pick one house style — likely "Krake™" on first mention per document, plain "Krake" thereafter, matching normal trademark convention — and apply everywhere.
- **Point of view**: Manuals mix "we," "the Alarm Developer," "you," and third-person "the Krake" within the same paragraph. HardwareX draft is more consistently third-person/passive, as academic style expects. You've said you want a "we" team voice — that's very workable for the manuals and README, but note HardwareX has its own required conventions (more formal, methods-paper register) that shouldn't be fully "we"-ified in the same way — it already uses "we" in places, which is normal for HardwareX articles, so this is really just about consistency, not a wholesale voice change.
- **Product name capitalization/quoting**: "Krake™," "Krake," and "the Krake" (with article) are all used interchangeably, sometimes in the same sentence. Worth a simple style rule (e.g., always "the Krake" when used as a common noun, "Krake™" only on first mention in a document).
- **Author voice fingerprints**: A few passages read as clearly personal/first-person aside rather than team voice, e.g., Developer Manual: *"Lee thinks that the card should NOT be removable without disassembly..."* — this is useful institutional knowledge but needs to be converted to team voice and a stated decision, not attributed to one person by first name in a public document.
- **Redundant/parallel content**: the "Krake™ Purpose," Mute Button, Rotary Encoder, Wireless Connection, and Ordering sections are near-duplicates across User Manual and Developer Manual — same content, tiny wording differences. This is the clearest sign of multiple contributors solving the same problem independently.

---

## 4. What I'd recommend as the fix order

1. **Resolve the flagged fact conflicts** (§1) with the team — I can't guess these; they need a person who has the physical hardware in hand or the git history of the specs. *(Several already resolved through this conversation — dimensions/weight, PCB/PWA convention, journal name.)*
2. **Fix the HardwareX draft's structural debris** (stray comment text, unresolved template instructions) — this document is closest to being reviewed by an external editor and currently wouldn't pass a first read.
3. **Import current content into the HardwareX Build Instructions section from the authoritative Markdown Assembly doc** — this is now a bigger job than originally scoped. The HardwareX draft's build section reflects an old, abandoned version of the procedure; the Factory Test menu, Enclosure Assembly steps, and ElegantOTA firmware workflow all need to come across, not just get relabeled.
4. **Decide the User Manual / Developer Manual overlap strategy** — merge-and-cross-reference vs. intentional duplication — before doing any voice/style pass, since it changes how much rewriting is needed.
5. **Do the "we" voice and terminology pass** last, once facts and structure are settled, so we're not polishing prose that's about to change.

## 5a. Backlog — related but out of scope for this documentation pass

- **Schematic/KiCad project has no PWA-level revision field** — only PCB revision is currently tracked in the design files. Now that a PCB/PWA dual-numbering convention exists (see §1, PCB revision), it would be worth adding a PWA revision annotation directly to the schematic or project metadata so this doesn't have to be reconstructed from memory or documentation archaeology next time.
  - **Additional complicating history (for whoever picks up this ticket):** the schematic version was incremented to 2.1 around the same time PWA changes began, and a 2.1 PCB was created with silkscreen changes — but no footprint or copper changes are believed to have been made at the PCB level. Separately, the KiCad project files were corrupted at some point and had to be reverted to an earlier commit; as of this writing, both the schematic and PCB show as **Rev 2.0** again. There may be intermediate commits that preserve the 2.1 changes, but this has not yet been checked. **Not in the critical path for the HardwareX article** — noted here so it isn't lost, but doesn't block the documentation work.
  - Suggested as a GitHub issue for after the documentation work.

- **Product naming strategy for multi-use Krake hardware (new, strategic — flagged by team, not a documentation defect).** The Krake hardware platform is general-purpose; firmware developed so far targets the alarm-annunciator use case, but the team has discussed a second application: using the same hardware as a controller/HMI for PolyVent (Public Invention's open-source ventilator, which currently has no user interface and is laptop-controlled only). No name yet exists for this second application.
  - **Recommendation discussed:** decouple the hardware platform identity ("Krake") from the identity of each firmware-defined application built on it. Keep "Krake" as the name of the physical hardware/enclosure/PCB platform (as already documented), and give the PolyVent-controller application its own distinct product name and documentation trail, explicitly described as "built on the Krake hardware platform" rather than as a mode or variant of Krake itself.
  - **Why this matters more than a typical naming choice:** unlike the alarm-annunciator use case, a PolyVent controller is a component of respiratory life-support equipment. Medical device regulatory frameworks (e.g., FDA 510(k)) generally treat a device with a different intended use as a different device for regulatory purposes — same hardware, different firmware/intended use, means separate classification, labeling, and documentation requirements are likely down the line. Establishing separate product identity now, before firmware exists, avoids having to retroactively disentangle "Krake" (general-purpose, no medical claims) from a future medical-context product sharing its name.
  - **Not in the critical path for the HardwareX article** — the HardwareX submission concerns the alarm-annunciator hardware/firmware as it exists today, and doesn't need to resolve this naming question. Noted here so it isn't lost, and so it's on record before any PolyVent-controller firmware or documentation work begins.
  - Suggested next step: loop in whoever manages PolyVent's regulatory/quality strategy early, since the naming decision is small relative to the eventual compliance path but easier to get right from the start than to fix later.

## 5. What I need from you to proceed

- Decisions on the six items in §1 (or confirmation that some are fine as-is / intentionally different states of the device).
- A call on the User/Developer Manual duplication strategy.
- Confirmation of fix order, or reprioritization if you'd rather start with the HardwareX article since it may be closer to a submission deadline.

Once you've weighed in, I can start on whichever document you want to tackle first — my suggestion would be the HardwareX article's Abstract and structural cleanup, since that's blocking the most.

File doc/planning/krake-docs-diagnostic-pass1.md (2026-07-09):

# Krake Documentation — First-Pass Diagnostic Analysis

**Sources reviewed:**
1. GitHub README.md (`PubInv/krake`)
2. Krake™ User/Operator Manual v0.1 (Google Doc)
3. Krake™ Developer's Technical Manual v0.1 (Google Doc)
4. HardwareX article draft (Overleaf, LaTeX)
5. Krake Test and Assembly Procedure Document v0.1.0 (Overleaf, LaTeX)

This is a diagnostic pass only — no rewriting yet. Goal is to surface conflicts, gaps, and structural
issues so we can agree on a fix order before touching prose.

---

## 1. Fact conflicts requiring a team decision

These are places where two or more documents state something different, and only the team can say
which is correct.

| Item | Source A | Source B | Notes |
|---|---|---|---|
| ~~**Physical dimensions**~~ **RESOLVED** | Developer Manual: "160mm x 110mm x 50mm (6"x4.25"x1.75"), weighs 232 grams" | HardwareX §7.3: "weighs less than 740 grams. Dimensions are: 150 x 180 x 90 mm" | **Not a documentation error — two real hardware states.** The 232g/160x110x50mm figure describes the **Rev1** enclosure with a 28mm speaker (too quiet, since retired). The Rev2 enclosure was enlarged to fit a 3" speaker for adequate volume, raising both size and mass. **Confirmed current Rev2 measurements (re-measured for parallax error): enclosure body 150mm x 180mm x 67mm, mass 742g; overall depth at the rotary encoder knob is 78mm.** HardwareX's "90mm" was an early rough estimate — supersede with 67mm (body) / 78mm (at knob). **Action:** Developer Manual should carry the Rev2 figures as current spec; the Rev1 232g figure should only remain if explicitly labeled historical/reference-only per the team's rev1 policy. |
| **Power draw** | Developer Manual: "9-12VDC... less than 500 mA and typically 250mA (less than 6 watts)" | Assembly Doc: bench supply 8–12V, current limit <1A, typical measured draw **150–190 mA** at 8.3–8.4V | Numbers are in the same ballpark but don't match. Assembly doc numbers are actual measurements from real units, so they're probably more trustworthy — Developer Manual reads like an earlier estimate. |
| **Firmware version** | README: firmware at **v0.50.0** | Developer Manual screenshot: `GPAD_API 0.19_20241119` | Big gap (0.19 vs 0.50.0). Developer Manual example is clearly stale and needs a refreshed screenshot/output. |
| ~~**PCB revision**~~ **RESOLVED** | Assembly Doc, page 1: "Confirm PCB is marked as **Rev 2.0**" | Same document, a few paragraphs later: "Confirm PCB is marked as **Rev 2.1**" (in both the standalone doc and the HardwareX-embedded version of the same section) | **Not a simple typo — a PCB-vs-PWA conflation.** Team convention going forward: **PCB Rev 2.0** = the bare board actually fabricated (design started ~Aug 2025, populated Jan 2026 batch). **PWA Rev 2.1** = PCB Rev 2.0 + enclosure + speaker + cable assembly + label — the complete assembled/tested unit. PCB Rev 2.1 (the in-progress silkscreen/BOM refinement) has **not been released** (no Gerbers generated) and should not appear as if describing built hardware. **Action:** every "Rev 2.1" reference to the built batch becomes "PWA Rev 2.1 (PCB Rev 2.0)" on first use per section, with a short disambiguation note near the top of the Assembly doc and the HardwareX Build Instructions section defining PCB vs. PWA. |
| **Unit serial range tested** | Assembly Doc body: example measurements for **US0001–US0005** | HardwareX §1: batch described as **US0006–US00015, LB0006–LB00011, LDN0001–LDN0005** | Different unit ranges in what's meant to be the same batch/procedure. Worth confirming which numbers are real. |
| **Powered TP102 (Vin) reading** | Assembly Doc §5.6.2 (Krake Rev 2.0 section): "TP102 Vin ≈ 5.04–5.06 V" | Same doc, later "Rev 2.1" powered-test table: "TP102 ≈ 4.5V" | Inconsistent within the same document; also 4.5V is a strange reading for a Vin rail expected to sit near the bench-supply voltage (8.3V) minus drop — worth double-checking this isn't a transcription error. |
| **Ordering price** | Developer Manual: "approximately $200USD," contact Robert Read directly | Not mentioned in README or HardwareX | Confirm this is still current before it goes in a permanent, indexed HardwareX article. |
| **OSHWA certification UID** | HardwareX specs table: `US002818` | Not mentioned in README, User Manual, or Dev Manual | Should probably be surfaced in the README and User Manual too, since it's a credibility signal for new visitors. |
| **Trademark usage** | User/Dev Manuals: consistent "Krake™" | README / HardwareX: plain "Krake," no ™ | Needs a house-style decision (see §3). |

---

## 2. Structural / completion gaps

**HardwareX article** — this is the least finished document and has the most template debris:
- The Abstract section still contains **unresolved editor/reviewer comment text** bleeding into the visible body (e.g., stray fragments like "not in template," "graphical abstract," mid-sentence interruptions). This reads as corrupted or improperly-resolved tracked changes/comments from Overleaf/Word round-tripping, and needs a clean rewrite pass before anything else in that document is touched.
- Several section headers still contain the **unmodified HardwareX instructional text** ("Write a short description...", "Add 3–5 bullet points...") mixed in with actual content — a sign these sections were drafted directly into the template without deleting the prompts.
- **Ethics statement, CRediT statement, Acknowledgements, References, "Useful References," Design Files table costs** are explicitly marked TBD, placeholder, or contain obvious placeholder values (e.g., BOM costs listed as `1000000` for the enclosure and PCB — clearly a formatting artifact, not real costs).
- §7 (Validation) has three subsections (Sound/Light, Electrical Parameters, Physical Parameters) that are almost entirely TBD, tagged to specific people ("TBD: Lee," "TBD: Lee, Courtney").
- The reference to "the Krake, the Zetron SentriMax" comparison seems to have an editor comment ("Missing is a comparison...") embedded directly in the body text.

**Developer Manual:**
- Multiple `TBD` and `????` placeholders in the Wireless Connection section (default password, exact button to hold for WiFi Manager, etc.) — this is core setup instructions for a real user, so these gaps block someone from actually using the device.
- "Communicating with the Krake" section literally says "TODO: Write this section in reference to the diagram below" — the diagram exists but the explanatory text was never written.
- Python MQTT example section says "TO BE DONE: NAGHAM ADD PYTHON CODE HERE."
- SPI Interface connector type is marked "TBD."
- Note this manual is dated/versioned as v0.1 — it may be the least mature of the four, other than the HardwareX draft.

**User Manual:**
- Shares roughly 70% of its content verbatim with the Developer Manual (Wireless Connection, Mute Button, Rotary Encoder, Ordering sections are nearly identical). This isn't necessarily wrong — some overlap is expected since they share an audience for some topics — but right now it looks like duplication-by-copy-paste rather than an intentional shared-content strategy. Worth deciding: cross-reference instead of duplicate, or keep parallel but ensure they never drift again.
- Same `????` and TBD gaps in the WiFi Manager section as the Developer Manual (since it was copied from there).

**Assembly & Test Procedure Document:**
- Most complete and "real" of all the docs — it has actual measured data, not just placeholders.
- Still carries **ISO template scaffolding** at the top (Background, Results/Discussion, References, Appendix headers) that are unfilled and read as boilerplate rather than a finished document.
- Revision history table still has `YYYY-MM-DD [Author Name]` placeholder rows for v0.2.0 and v1.0.0.
- Ends abruptly with "Ethics statements / CRediT / Acknowledgements / References — To be completed."
- Internally, this document appears **twice** in slightly different forms — once as a standalone procedure and once embedded (with more detail and more figures) inside the HardwareX draft's Build Instructions section. These have already started to drift from each other (see the Rev 2.0/2.1 and TP102 conflicts above), which is a preview of what will keep happening if they're maintained as two separate copies.

**README:**
- Most current and complete-feeling document. Good candidate as the "source of truth" for high-level facts (firmware version, feature list, licensing) that other docs should defer to or link to rather than restate.

---

## 3. Voice, terminology, and style drift

- **Trademark symbol**: User/Developer Manuals use "Krake™" consistently; README and HardwareX draft do not. Pick one house style — likely "Krake™" on first mention per document, plain "Krake" thereafter, matching normal trademark convention — and apply everywhere.
- **Point of view**: Manuals mix "we," "the Alarm Developer," "you," and third-person "the Krake" within the same paragraph. HardwareX draft is more consistently third-person/passive, as academic style expects. You've said you want a "we" team voice — that's very workable for the manuals and README, but note HardwareX has its own required conventions (more formal, methods-paper register) that shouldn't be fully "we"-ified in the same way — it already uses "we" in places, which is normal for HardwareX articles, so this is really just about consistency, not a wholesale voice change.
- **Product name capitalization/quoting**: "Krake™," "Krake," and "the Krake" (with article) are all used interchangeably, sometimes in the same sentence. Worth a simple style rule (e.g., always "the Krake" when used as a common noun, "Krake™" only on first mention in a document).
- **Author voice fingerprints**: A few passages read as clearly personal/first-person aside rather than team voice, e.g., Developer Manual: *"Lee thinks that the card should NOT be removable without disassembly..."* — this is useful institutional knowledge but needs to be converted to team voice and a stated decision, not attributed to one person by first name in a public document.
- **Redundant/parallel content**: the "Krake™ Purpose," Mute Button, Rotary Encoder, Wireless Connection, and Ordering sections are near-duplicates across User Manual and Developer Manual — same content, tiny wording differences. This is the clearest sign of multiple contributors solving the same problem independently.

---

## 4. What I'd recommend as the fix order

1. **Resolve the flagged fact conflicts** (§1) with the team — I can't guess these; they need a person who has the physical hardware in hand or the git history of the specs.
2. **Fix the HardwareX draft's structural debris** (stray comment text, unresolved template instructions) — this document is closest to being reviewed by an external editor and currently wouldn't pass a first read.
3. **Decide the User Manual / Developer Manual overlap strategy** — merge-and-cross-reference vs. intentional duplication — before doing any voice/style pass, since it changes how much rewriting is needed.
4. **Do the "we" voice and terminology pass** last, once facts and structure are settled, so we're not polishing prose that's about to change.

## 5a. Backlog — related but out of scope for this documentation pass

- **Schematic/KiCad project has no PWA-level revision field** — only PCB revision is currently tracked in the design files. Now that a PCB/PWA dual-numbering convention exists (see §1, PCB revision), it would be worth adding a PWA revision annotation directly to the schematic or project metadata so this doesn't have to be reconstructed from memory or documentation archaeology next time.
  - **Additional complicating history (for whoever picks up this ticket):** the schematic version was incremented to 2.1 around the same time PWA changes began, and a 2.1 PCB was created with silkscreen changes — but no footprint or copper changes are believed to have been made at the PCB level. Separately, the KiCad project files were corrupted at some point and had to be reverted to an earlier commit; as of this writing, both the schematic and PCB show as **Rev 2.0** again. There may be intermediate commits that preserve the 2.1 changes, but this has not yet been checked. **Not in the critical path for the HardwareX article** — noted here so it isn't lost, but doesn't block the documentation work.
  - Suggested as a GitHub issue for after the documentation work.

## 5. What I need from you to proceed

- Decisions on the six items in §1 (or confirmation that some are fine as-is / intentionally different states of the device).
- A call on the User/Developer Manual duplication strategy.
- Confirmation of fix order, or reprioritization if you'd rather start with the HardwareX article since it may be closer to a submission deadline.

Once you've weighed in, I can start on whichever document you want to tackle first — my suggestion would be the HardwareX article's Abstract and structural cleanup, since that's blocking the most.

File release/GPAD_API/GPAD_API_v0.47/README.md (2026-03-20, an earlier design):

# Krake™  Firmware Release 0.47
File name: GPAD_API_v0.47.bin
Built on Lee's computer 20 March 2026.

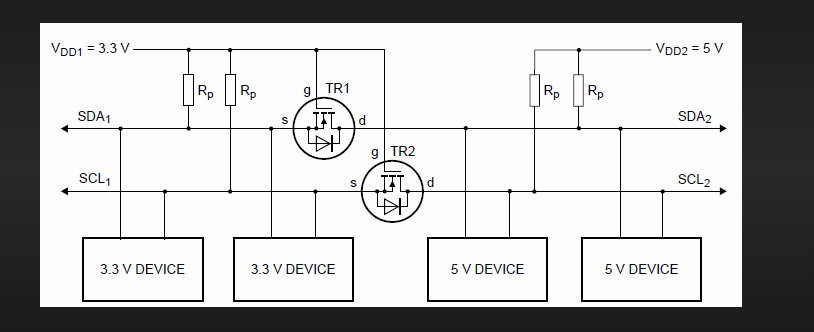
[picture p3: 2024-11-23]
dataSheets_designRef/i2c_levelShift.png

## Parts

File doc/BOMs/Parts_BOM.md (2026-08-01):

# Bill of Materials (BOM)

| Item | Manufacturer | PN | Description | Qty | Supplier | Datasheet | Purchase Link | Notes |
|-----:|---|----|---|----:|---|---|---|---|
| 1 | Generic | N/A | 2.54 mm 0.1" 1×8 Pin Female Socket Header, Single Row, Pack of 30 | 1 | Amazon | Manufacturer specification | Amazon product page | PCB socket headers |
| 2 | Small Parts | 0206BTP | Steel Sheet Metal Screw, Zinc Plated, Pan Head, Star Drive, Type B, #2-32 × 3/8" | 1 | Amazon | Manufacturer specification | Amazon product page | Mechanical hardware |
| 3 | PNY | N/A | 32 GB Elite Class 10 U1 microSDHC Flash Memory Card | 6 | PNY / Amazon | PNY Product Page | Amazon product page | Storage media |
| 4 | Haldzemo | 2004A | 20×4 LCD Display Module, Blue Backlight, 5 V | 3 | Amazon | HD44780 LCD Datasheet | Amazon product page | Character LCD |
| 5 | EBOOT | N/A | 5 mm White LED, Pack of 100 | 1 | Amazon | Generic 5 mm LED Datasheet | Amazon product page | Indicator LED |
| 6 | Generic | N/A | 5 mm Red LED, Pack of 100 | 1 | Amazon | Generic 5 mm LED Datasheet | Amazon product page | Indicator LED |
| 7 | Cricklewood Electronics | N/A | Cricklewood Electronics | N/A | **3 in (76 mm) Full-Range Round Speaker, 8 Ω, 10 W** | 1 | https://cricklewoodelectronics.com/3-inch-10W-Full-Range-Round-8-ohm-Speaker.html | https://cricklewoodelectronics.com/3-inch-10W-Full-Range-Round-8-ohm-Speaker.html | **Preferred speaker. Confirmed working unit.** |
| 8 | Mr. Pen | N/A | M3 Nuts & Bolts Assortment Kit | 1 | Amazon | Product specification | Amazon product page | Mechanical hardware |
| 9 | Generic | DFPlayer Mini | MP3 Audio Decoder Module | 2 | Amazon | DFPlayer Mini Datasheet | Amazon product page | Audio playback module |
| 10 | Robosource | N/A | Nylon Spacer, 1/8" Thick | 1 | Amazon | Product specification | Amazon product page | PCB spacers |
| 11 | California JOS | N/A | 2-Pin Jumper Caps (2.54 mm) | 1 pack | Amazon | Product specification | https://www.amazon.com/California-JOS-Standard-Circuit-Connection/dp/B0BRK36G33 | Header jumpers |
| 12 | Sabrent | CB-DB9P | USB-to-RS232 Serial Adapter | 2 | Amazon | https://sabrent.com/products/cb-db9p | https://www.amazon.com/Sabrent-Converter-Prolific-Chipset-CB-DB9P/dp/B00IDSM6BW | DTE/DCE communication |
| 13 | Lamroyce | N/A | DB9 Female-to-Female Gender Changer | 1 | Amazon | Product specification | https://www.amazon.com/Lamroyce-Connector-Extender-HD-RS232-Transfer/dp/B0FDFXM23S | RS-232 adapter |
| 14 | Generic | N/A | DB9 Null Modem Adapter | 1 | Amazon | Product specification | https://www.amazon.com/female-slimline-transfer-serial-adapter/dp/B075XHWVSJ | TX/RX crossover |
| 15 | StarTech | N/A | 2 m DB9 RS-232 Cable, Male-to-Female | 1 | Amazon | StarTech Product Page | https://www.amazon.com/StarTech-com-Black-RS232-Serial-Modem/dp/B00CEMGMMM | Serial extension cable |
| 16 | Unknown | B0D7Q9HJLQ | 20 Sets Mini Micro JST-PH 2.0mm 2 Pin Male Connector | 1 | Amazon | TBD | https://www.amazon.com/gp/product/B0D7Q9HJLQ | Awaiting product identification |

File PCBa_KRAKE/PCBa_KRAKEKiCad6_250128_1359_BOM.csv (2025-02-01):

Item # | *Designator | *Qty | Manufacturer | *Mfg Part # | Description / Value | *Package/Footprint | Type | Your Instructions / Notes
 | Reference(s) | Qty | Manufacturer | MPN | Value | Footprint | AssemblyType | Distributor 1
 | +5esp32 | 1 | ronghe | RH-5000 | +5esp32 | TestPoint:TestPoint_Loop_D2.54mm_Drill1.5mm_Beaded | HAND | JLCPCB
 | C101 | 1 | YAGEO | CC0603JRNPO9BN390 | 39pF | Capacitor_SMD:C_0603_1608Metric_Pad1.08x0.95mm_HandSolder | SMT | JLCPCB
 | C102, C106, C109, C115, C118, C302, C502, C505, C705 | 9 | KNSCHA | RVT47UF16V67RV0019 | 47uF 16V | Capacitor_SMD:CP_Elec_5x5.4 | SMT | JLCPCB
 | C103, C105, C108, C116, C117, C301, C303, C501, C503, C504, C602, C701, C702, C703, C704, C706 | 16 | YAGEO | CC0603KRX7R9BB104 | 100nF | Capacitor_SMD:C_0603_1608Metric_Pad1.08x0.95mm_HandSolder | SMT | JLCPCB
 | D101, D103, D104 | 3 | MDD(Microdiode Electronics) | SS210 | Schottky 2A | Diode_SMD:D_SMB | SMT | JLCPCB
 | D106 | 1 | Lite-On Inc. | LTST-C171KRKT | RED 0603 | LED_SMD:LED_0603_1608Metric_Pad1.05x0.95mm_HandSolder | SMT | JLCPCB
 | D301, D302, D303, D304 | 4 | Nexperia | BAT54S,215 | BAT54S | Package_TO_SOT_SMD:SOT-23 | SMT | JLCPCB
 | D501 | 1 | Hubei KENTO Elec | KT-0603R | RED 0603 | LED_SMD:LED_0603_1608Metric | SMT | JLCPCB
 | F101, F401 | 2 | Littelfuse | 0603L100SLYR | Polyfuse_Small_1A | Fuse:Fuse_0603_1608Metric | SMT | JLCPCB
 | J101 | 1 | XKB Connectivity / Tensility International Corp | DC-005-5A-2.0-SMT / 54-00164 | Barrel_Jack_Switch_SMT | GeneralPurposeAlarmDevicePCB:BarrelJack_CLIFF_FC681465S_SMT_Horizontal | SMT | JLCPCB
 | J102, J103, J602 | 3 | Amphenol ICC | 68000-102HLF | 0.100_2Pin | Connector_PinHeader_2.54mm:PinHeader_1x02_P2.54mm_Vertical | HAND | JLCPCB
 | J401 | 1 | TE Connectivity | 5555165-1 | RJ12_6P6C_HORZ | GeneralPurposeAlarmDevicePCB:RJ12_Amphenol_54601 | HAND | JLCPCB
 | J501 | 1 | Korean Hroparts Elec | TYPE-C-31-M-12 | USB_C_Receptacle_USB2.0 | GeneralPurposeAlarmDevicePCB:USB_C_Receptacle_HRO_TYPE-C-31-M-12 | SMT | JLCPCB
 | J601 | 1 | XFCN | PZ150V-02P | 1X2P 1.27 mm Header | Connector_PinHeader_1.27mm:PinHeader_1x02_P1.27mm_Vertical | HAND | JLCPCB
 | Q201, Q202, Q203, Q204, Q205, Q206, Q207 | 7 | Diodes Incorporated | MMBT2222A-7-F | MMBT2222A-7-F | Package_TO_SOT_SMD:SOT-23 | SMT | JLCPCB
 | Q301, Q302, Q303, Q304, Q305, Q401, Q402 | 7 | Yangzhou Yangjie Electronic Technology Co., Ltd | BSS138 | BSS138 | Package_TO_SOT_SMD:SOT-23 | SMT | JLCPCB
 | R101, R213, R216, R305, R307, R309, R310, R512, R711, R1002, R1009 | 11 | TyoHM | RMC060315%N | 1R0 | Resistor_SMD:R_0603_1608Metric_Pad0.98x0.95mm_HandSolder | SMT | JLCPCB
 | R102, R214, R215, R603, R1003, R1004, R1005 | 7 | TyoHM | RMC 0603 10K F N | 10K | Resistor_SMD:R_0603_1608Metric_Pad0.98x0.95mm_HandSolder | SMT | JLCPCB
 | R110, R112, R202, R204, R206, R208, R210, R401, R402, R403, R404, R501, R502, R503, R509, R510, R511, R701, R702, R703, R704, R705, R706, R709, R710, R1008 | 26 | TyoHM | RMC06033301%N | 330R | Resistor_SMD:R_0603_1608Metric_Pad0.98x0.95mm_HandSolder | SMT | JLCPCB
 | R113, R114, R115, R116 | 4 | TyoHM | RMC0603391%N | 39R | Resistor_SMD:R_0603_1608Metric_Pad0.98x0.95mm_HandSolder | SMT | JLCPCB
 | R201, R203, R205, R207, R209, R301, R302, R303, R311, R312, R313, R315, R316, R318, R319, R321, R322, R324, R405, R406, R409, R410, R504 | 23 | TyoHM | RMC 0603 4K7 F N | 4K7 | Resistor_SMD:R_0603_1608Metric_Pad0.98x0.95mm_HandSolder | SMT | JLCPCB
 | R211, R212 | 2 | UNI-ROYAL(Uniroyal Elec) | 0603WAF5101T5E | 5K1 | Resistor_SMD:R_0603_1608Metric_Pad0.98x0.95mm_HandSolder | SMT | JLCPCB
 | R304 | 1 | TyoHM | RMC06031K1%N | 1K | Resistor_SMD:R_0603_1608Metric_Pad0.98x0.95mm_HandSolder | SMT | JLCPCB
 | RV301 | 1 | BOURNS | 3386P-1-103LF | POT 0.375 10K | GeneralPurposeAlarmDevicePCB:Potentiometer_Bourns_3386P_Vertical | SMT | JLCPCB
 | S101, S102 | 2 | TE Connectivity ALCOSWITCH Switches | TE Connectivity 1825910-7, Dongguan Guangzhu Industrial C13828 | SWITCH_TACTILE_SPST-NO_0.05A_24V | GeneralPurposeAlarmDevicePCB:Switch_Tactile_THT_6x6mm | HAND | JLCPCB
 | S601 | 1 | Omron Electronics | B3F-4055 | SWITCH_TACTILE_12mmx12mm_SPST-NO_0.05A_24V | GeneralPurposeAlarmDevicePCB:SW_PUSH-12mm_WithCap_Green | HAND | JLCPCB
 | SW101 | 1 | ALPSALPINE | EC11E18244AU | RotaryEncoder_Switch | Rotary_Encoder:RotaryEncoder_Alps_EC12E-Switch_Vertical_H20mm | HAND | JLCPCB
 | TP101 | 1 | ronghe | RH-5121 | TP_GND | TestPoint:TestPoint_Loop_D2.54mm_Drill1.5mm_Beaded | HAND | JLCPCB
 | TP102 | 1 | ronghe | RH-5000 | Vin | TestPoint:TestPoint_Loop_D2.54mm_Drill1.5mm_Beaded | HAND | JLCPCB
 | TP103 | 1 | ronghe | RH-5000 | +5V | TestPoint:TestPoint_Loop_D2.54mm_Drill1.5mm_Beaded | HAND | JLCPCB
 | TP201 | 1 | ronghe | RH-5000 | VBus | TestPoint:TestPoint_Loop_D2.54mm_Drill1.5mm_Beaded | HAND | JLCPCB
 | TP202 | 1 | ronghe | RH-5000 | V3 | TestPoint:TestPoint_Loop_D2.54mm_Drill1.5mm_Beaded | HAND | JLCPCB
 | TP203 | 1 | ronghe | RH-5004 | nCTS | TestPoint:TestPoint_Loop_D2.54mm_Drill1.5mm_Beaded | HAND | JLCPCB
 | TP401 | 1 | ronghe | RH-5000 | Vcc_LCD | TestPoint:TestPoint_Loop_D2.54mm_Drill1.5mm_Beaded | HAND | JLCPCB
 | TP402 | 1 | ronghe | RH-5004 | nINT | TestPoint:TestPoint_Loop_D2.54mm_Drill1.5mm_Beaded | HAND | JLCPCB
 | TP403 | 1 | ronghe | RH-5004 | SCL | TestPoint:TestPoint_Loop_D2.54mm_Drill1.5mm_Beaded | HAND | JLCPCB
 | TP404 | 1 | ronghe | RH-5004 | SDA | TestPoint:TestPoint_Loop_D2.54mm_Drill1.5mm_Beaded | HAND | JLCPCB
 | TP405 | 1 | ronghe | RH-5000 | Vcontrast | TestPoint:TestPoint_Loop_D2.54mm_Drill1.5mm_Beaded | HAND | JLCPCB
 | U101 | 1 | HANSCHIP semiconductor | LM7805CTG | LM7805_TO220 | Package_TO_SOT_THT:TO-220-3_Horizontal_TabDown | HAND | JLCPCB
 | U102 | 1 | Espressif Systems | ESP32-WROOM-32E-N4 | ESP32-WROOM-32E-N4 | RF_Module:ESP32-WROOM-32D | SMT | JLCPCB
 | U103 | 1 | Advanced Monolithic Systems | AMS1117-3.3 | AMS1117-3.3 | Package_TO_SOT_SMD:SOT-223-3_TabPin2 | SMT | JLCPCB
 | U301 | 1 | NXP Semicon | PCF8574AT_3_518 | PCF8574AT_3_518 | Package_SO:SOIC-16W_7.5x10.3mm_P1.27mm | SMT | JLCPCB
 | U303 | 1 | XFCN | PZ254V-11-16P | Conn_01x16 | Connector_PinHeader_2.54mm:PinHeader_1x16_P2.54mm_Vertical | HAND | JLCPCB
 | U501 | 1 | WCH(Jiangsu Qin Heng) | CH340T | CH340T | GeneralPurposeAlarmDevicePCB:SSOP-20_5.3x7.2mm_P0.65mm_CH340T | SMT | JLCPCB
 | U701 | 1 | Texas Instruments | MAX3232ID | MAX3232 | Package_SO:SOIC-16_4.55x10.3mm_P1.27mm | SMT | JLCPCB

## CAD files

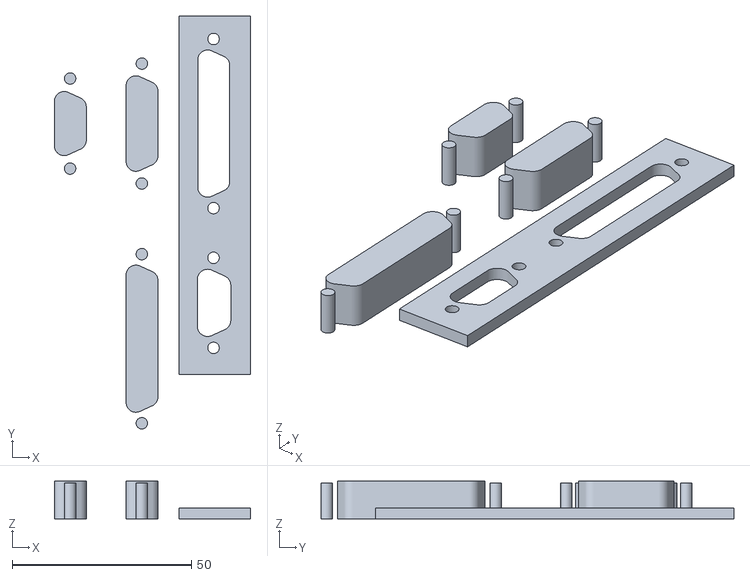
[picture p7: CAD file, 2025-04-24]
enclosure/imported_scadModels/DB9-Library-SCAD/files/D-Sub/samples(not for printing).stl
54.7 x 115.2 x 10.5

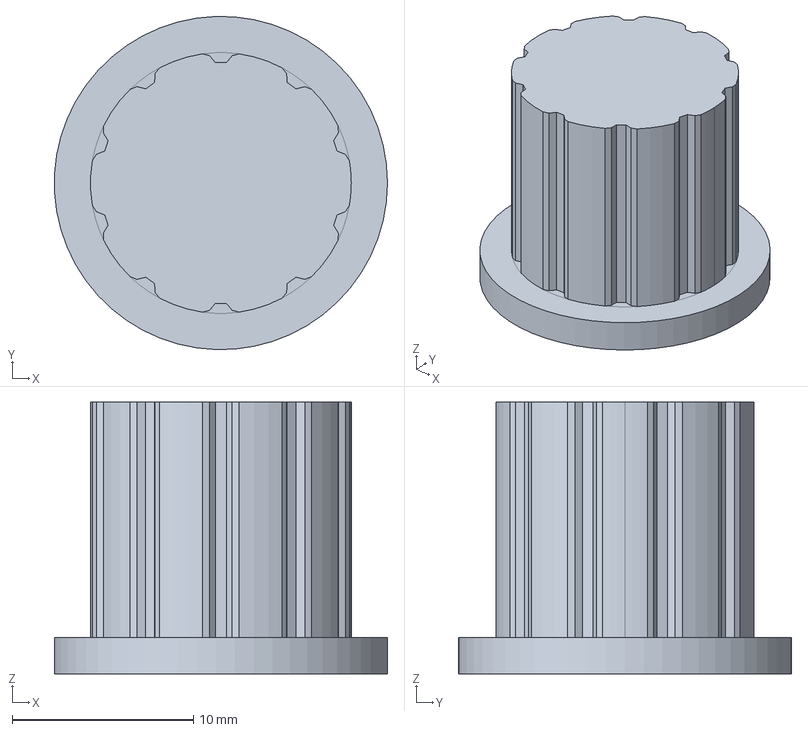
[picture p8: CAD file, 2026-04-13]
enclosure/imported_scadModels/freeCADmodels/knob_rotary.FCStd
18.4 x 18.4 x 15.0 mm

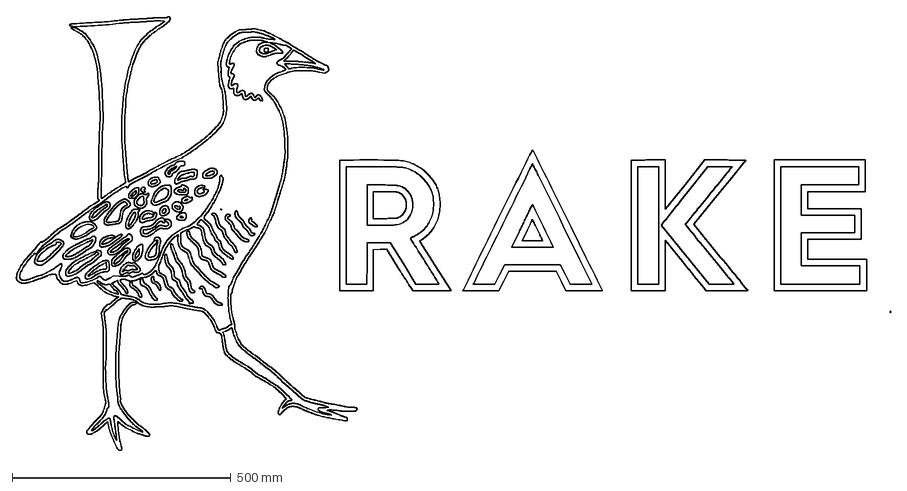
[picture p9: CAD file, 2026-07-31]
enclosure/imported_scadModels/KRAKE_3.dxf
1997.1 x 991.6 mm

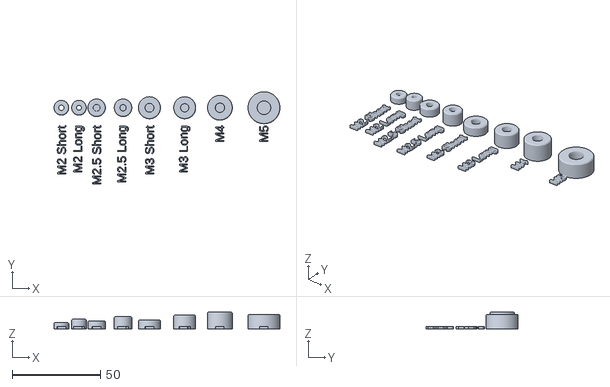
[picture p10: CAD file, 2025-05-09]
enclosure/imported_scadModels/OpenSCAD Heat-set Insert Standoff Stud modules - 5849866/files/StudModules.stl
128.3 x 52.5 x 9.60

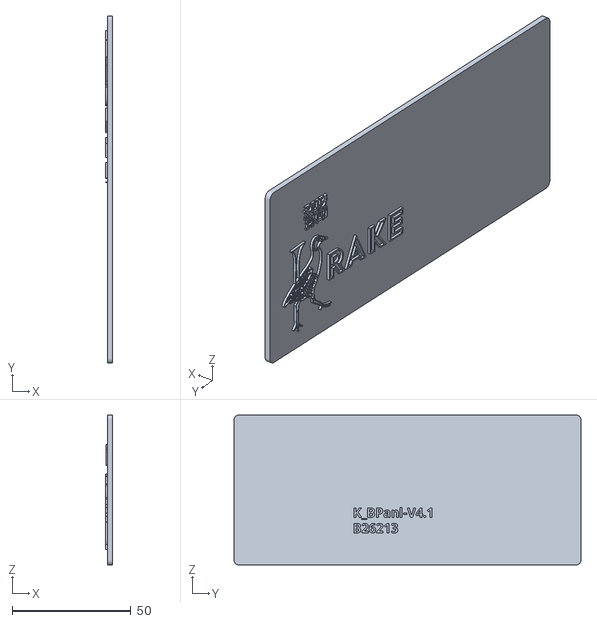
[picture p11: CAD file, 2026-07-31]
enclosure/parts_toPrint/U_Box_V105_Krake_RevB_BPanL_V4.1.stl
2.90 x 146.1 x 63.1

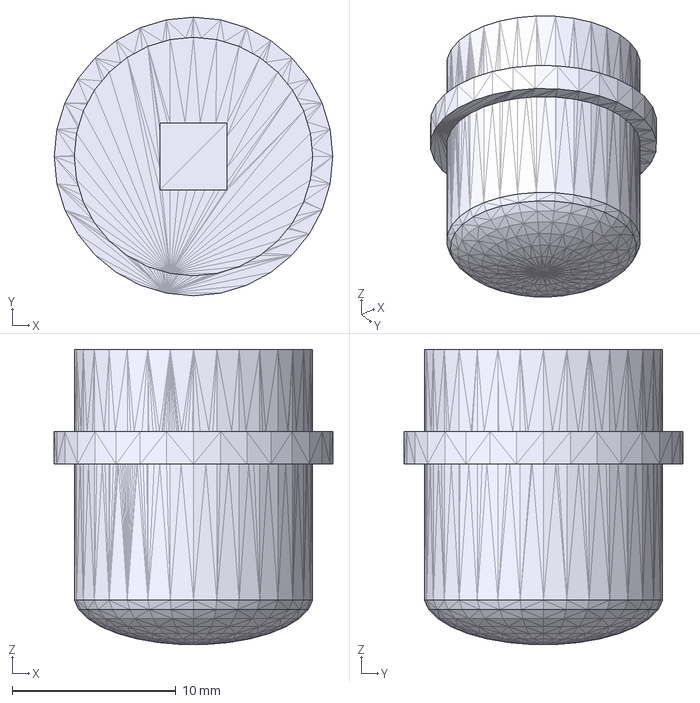
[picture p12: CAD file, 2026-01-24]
PWA_REV2/Parts/KeyCap_Mute_GPAD.FCStd
17.0 x 17.0 x 18.0 mm

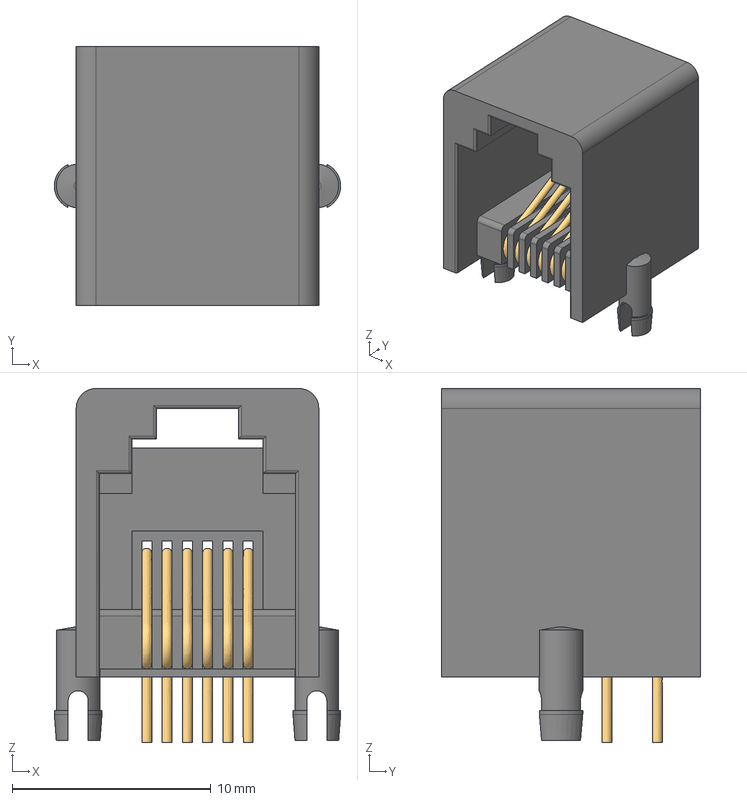
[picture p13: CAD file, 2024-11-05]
PWA_REV2/Parts/rj11-connectors-6p-1.snapshot.1/rj-69-horiz-615006138421 (rev1).stp
14.4 x 13.0 x 17.8 mm
615006138421_PIN x 3
615006138421_PIN_LONGUE x 3
6150xx138421

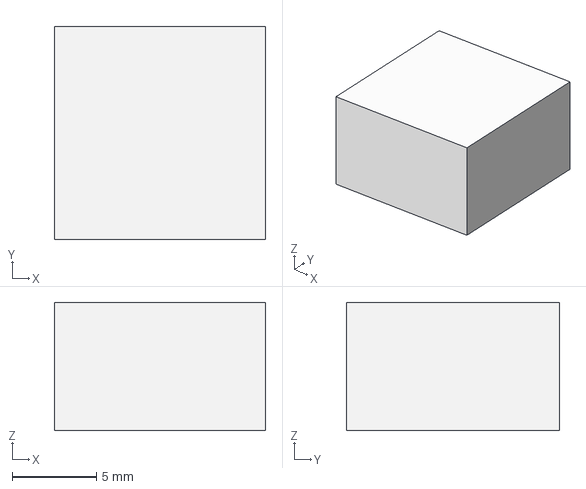
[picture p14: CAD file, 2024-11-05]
PWA_REV2/Parts/S04B-XASK-1/first/Cube.step
12.5 x 12.6 x 7.59 mm

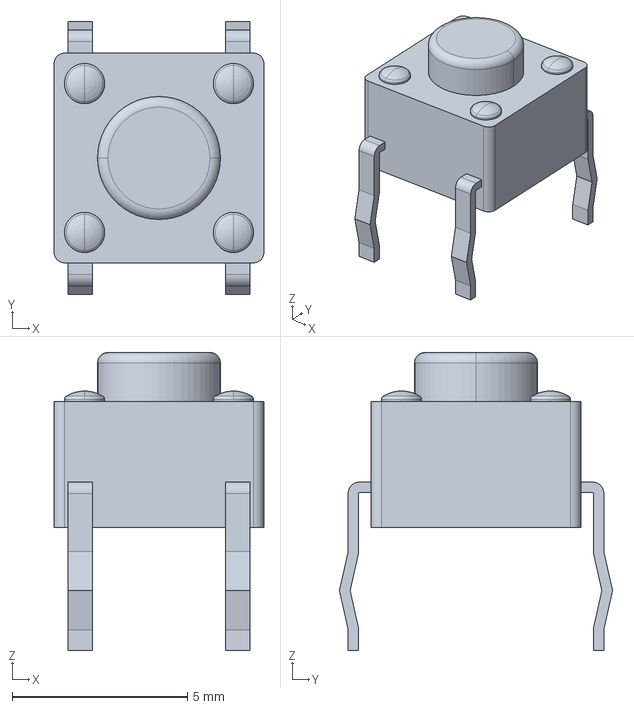
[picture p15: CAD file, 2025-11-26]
PWA_REV2/Parts/TE_1825910-7_C.3d_stp/c-1825910-7-c-3d.stp
5.99 x 7.80 x 8.51 mm

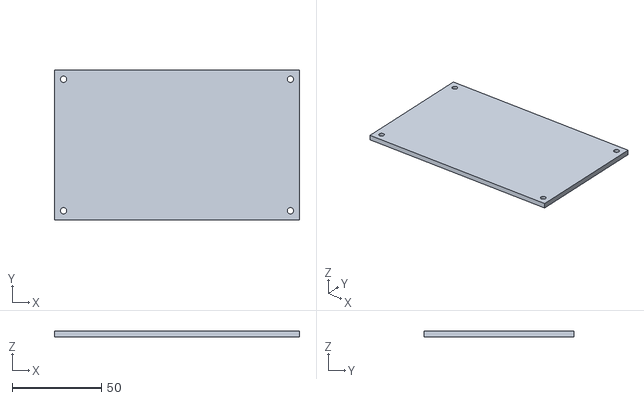
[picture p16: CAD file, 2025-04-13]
PWA_REV2/Parts/WorkBenchKrake/WorkBenchKrake-PartBody.stl
137.2 x 83.8 x 3.17

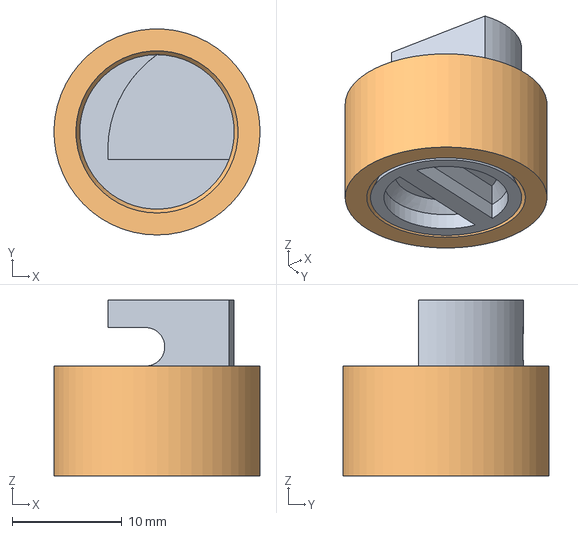
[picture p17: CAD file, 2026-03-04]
enclosure/imported_scadModels/freeCADmodels/rotating_latch.FCStd
18.7 x 18.7 x 16.0 mm

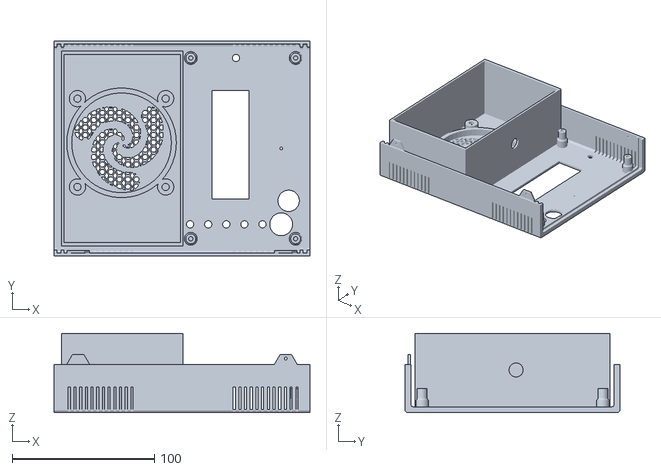
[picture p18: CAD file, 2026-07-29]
enclosure/parts_toPrint/U_Box_V105_Krake_RevB_BShell_V4.1.stl
179.8 x 150.8 x 55.8

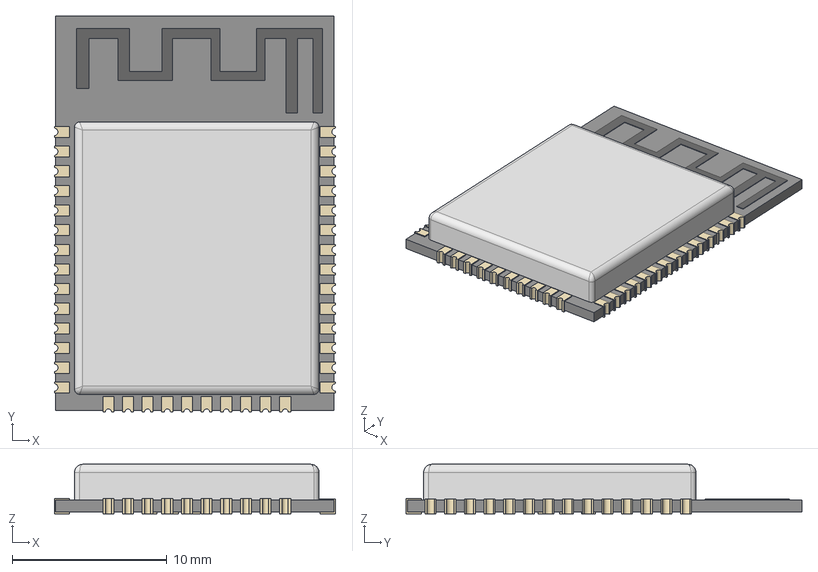
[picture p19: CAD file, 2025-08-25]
PWA_REV2/Parts/ESP32-WROOM-32E-N4.stp
18.2 x 25.6 x 3.20 mm

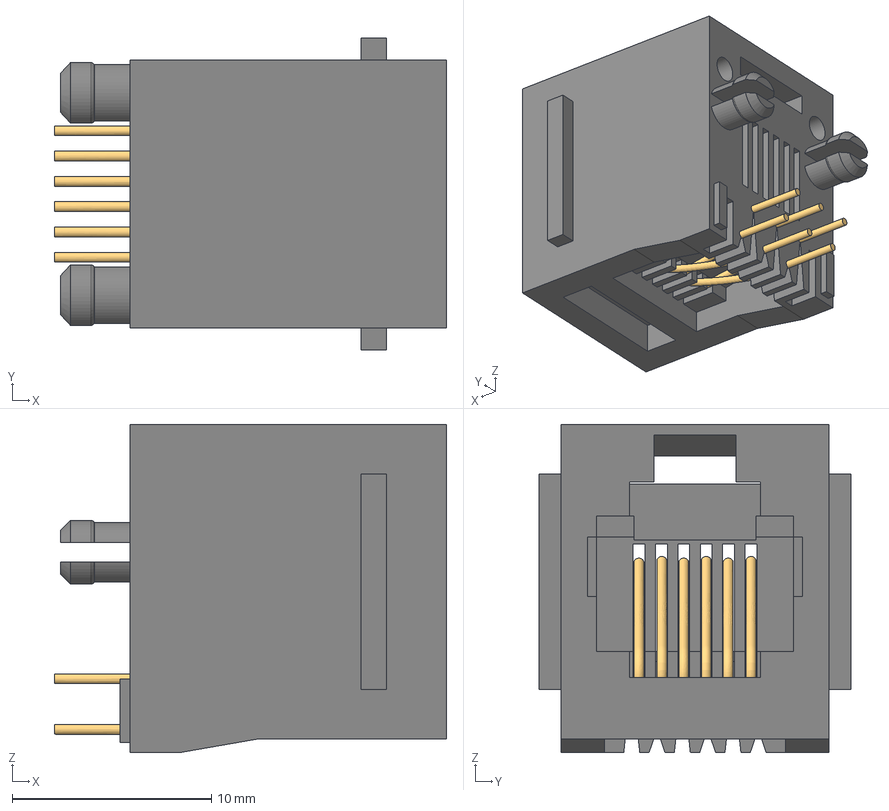
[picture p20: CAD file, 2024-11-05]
PWA_REV2/Parts/rj11-connectors-6p-1.snapshot.1/rj_6p_615006144121 (rev1).stp
19.7 x 15.7 x 16.5 mm
pin1
pin3
pin5
pin2
pin4
pin6
housing

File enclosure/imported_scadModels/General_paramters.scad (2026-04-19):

KrakeEnclosureVersion = 4.0; // change this with each rev

/* Project Selector */
Krake= 0;      // [0:Off, 1:On] //on // for the 28 mm speaker
GPAD  = 0;      // [0:Off, 1:On]
Krake_rev2_76mmSPK= 1;  // 76 mm / 3 inch speaker
NumberingSystem = 1; // enable part number text

if (Krake + GPAD > 1)
echo("WARNING: More than one project mode active!!!");

//////////////////////////////
Krake_76mmSPK_56h    = 1;  // turn off if using Cricklewood Speaker 40 mm height and if using 28 mm speaker  
////////////////////////////////////////////////////////////////////
// Connectors Modifications specific port logic
//if krake true x: y; i.e if krake on, usbbon =0, aka off

//DE9SquareHole = Krake ? 1 : 1;
speaker_clamp = Krake ? 0 : 1;
grill_pattern = Krake ? 0 : 1;
SpeakerEnclosure  = Krake ? 0 : 1;
SpeakerCutOut  = Krake ? 0 : 1;
/////////////////////////////////////////////////speaker_clamp = Krake_rev2_76mmSPK ? 1 : 0;
grill_pattern = Krake_rev2_76mmSPK ? 1 : 0;
SpeakerEnclosure  = Krake_rev2_76mmSPK ? 1 : 0;
SpeakerCutOut  = Krake_rev2_76mmSPK ? 1 : 0;
SPKBOSS62 = Krake_rev2_76mmSPK ? 1 : 0;
SPKBOSSpunch62 = Krake_rev2_76mmSPK ? 1 : 0;
// Common Parameters - Base settings shared by all configurations
////////////////////////////////////////////////////////////////////
// speaker parameters
SpeakerDiameter_mm= Krake_rev2_76mmSPK? 78 : 27; 
SpeakerRadius_mm=SpeakerDiameter_mm/2;
SpeakerHeight_mm = Krake_rev2_76mmSPK ? 40 : 0; 
////////////////////////////////////////////////////////////////////
translationVariable = Krake_rev2_76mmSPK ? 2.2 * SpeakerHeight_mm -5: 0 ;
////////////////////////////////////////////////////////////////////
Length         = 83.82 + 13 +translationVariable;  //x axis    
Width          = 138 + 13; //y axis axis            
Height         = Krake_76mmSPK_56h? 48 + SpeakerHeight_mm/2 : 28 + SpeakerHeight_mm/2; //z axis was 40
Thick          = 2;                    // Wall thickness
Filet          = 2;                    // Corner rounding
Resolution     = 10;                   // Filet smoothness
m              = 0.9;                  // Panel/rail tolerance
PCBFeet        = 1;                    // Enable PCB feet
Vent           = 1;                    // Enable vents
Vent_width     = 1.5;
////////////////////////////////////////////////////////////////////
// PCB Parameters - Common
PCBPosX        = 0 + translationVariable;
PCBPosY        = 0;
PCBLength      = 83.82;
PCBWidth       = 137.16;
PCBThick       = 1.6;
///////////////////
// Decorative Parameters
Couleur1       = "Orange";
Couleur2       = "OrangeRed";
Couleur3       = "Green";
Dec_Thick      = Vent ? Thick * 2 : Thick;
Dec_size       = Vent ? Thick * 2 : 0.8;
////////////////////////////////////////////////////////////////////

////////////////////////////////////////////////////////////////////
// BOSS/Foot Parameters 
FootHeight     = 15;
FootDia        = 7;
FootHole       = 3.0;
FootPosX       = 5.08;
FootPosY       = 5.08;
/////////////////////////////////////////////////
///////////////////

// Speaker location parameters
SpeakerPositionX = Length/4;
SpeakerPositionY =Width/2;
SpeakerPositionZ = 0-Thick;
SpeakerHolePosX =Thick+m/2 -FootHeight;
SpeakerHolePosY = SpeakerPositionY;
SpeakerHolePosZ = SpeakerPositionZ+ SpeakerDiameter_mm/2;
Angle_deg =90;
//Modifications for muteButton
muteButtonXpos = PCBLength-10  + translationVariable;
muteButtonYpos = 31.75;
muteButtonDiameter = 15;

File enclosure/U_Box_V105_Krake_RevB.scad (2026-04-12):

//File: U_Box_V105_Krake_RevB.scad
//Modified by Public Invention to make enclosures for:
// GPAD
// KRAKE (TM)

////////////////////////////////////////////////////////////////////
//  Heartman/Hearty OpenSCAD Parametric Box 
// MODIFIED BY NAGHAM KHEIR, COURTNEY LUDICK //
//  Krake & GPAD Configurable Enclosure Generator                //
//  License: CC BY-NC 3.0                                        //
////////////////////////////////////////////////////////////////////

// Thanks to RonRN18 for this Creative Commons Attribution set of Heat-set insert:
// https://www.thingiverse.com/thing:5849866
include <imported_scadModels/StudModules.scad>


use <imported_scad/ModelsUtil_modules.scad>

use <imported_scadModels/B_shell.scad>
use <imported_scadModels/T_shell.scad>
use <imported_scadModels/F_panl.scad>
use <imported_scadModels/B_panl.scad>

include <imported_scadModels/General_paramters.scad>


////////////////////////////////////////////////////////////////////
// Export Options
////////////////////////////////////////////////////////////////////
GPAD_TShell          = 1;
GPAD_BShell          = 1; //2 w/LCD 
GPAD_FPanL           = 1;//3 bottom
GPAD_BPanL           = 1; //4 top

BButton              = 0 ;
RotaryEncoder        = 0;  // change to a real rotary encoder 
T_BShellScrew        = 0;
BOSSScrew            = 0;
PCB_SIMPLE           = 0;
//PWA_GPAD             = 0;
PWA_KRAKE            = 0;//pcb
LED_Standoff         = 0;
LED_Standoff_Single  = 0;
PWA                  = 0;
SPK                  = 0;
HEAT_SET_INSERTS     = 0;
SPKLid               = 0;

////////////////////////////////////////////////////////////////////

// Import 3mm Plastite Screw
if(BOSSScrew ==1){
translate ([PCBLength-70.74,12.24,25]) //is this just to reposition the screw to the correct place?, where are these numbers from?
//translate ([0,0,FootHeight+ScrewLenght+1])
import("parts_toPrint/MCMaster_Carr_Pan_Head_Screw_99461a941.stl");
}

//LED Spacer
module LedSpacer(OnOff,Cx,Cy,Cdia,Cpitch,Cheight,Ccenter=false){ 

translate([Cx,Cy,0])
difference(){
cylinder(d=Cdia,Cheight, $fn=50,center=Ccenter); //spacer body
union(){
hull(){
translate([Cpitch/2,0,-0.5])
cylinder(d=1.3,h=Cheight+1, $fn=50,center=Ccenter); //leg1
translate([Cdia/2,0,-0.5])
cylinder(d=1.3,h=Cheight+1, $fn=50,center=Ccenter); //leg2
}
hull(){
translate([-Cpitch/2,0,-0.5])
cylinder(d=1.3,h=Cheight+1, $fn=50,center=Ccenter); //leg1
translate([-Cdia/2,0,-0.5])
cylinder(d=1.3,h=Cheight+1, $fn=50,center=Ccenter); //leg2
}
}
}
}

//Button
module ButtonSwitch(OnOff,Cx,Cy,Cdia,Ccenter=false){
//difference(){
if(OnOff==1)
translate([Cx,Cy,-1]){
//rotate([180,0,0])

ThreadThick = 0.20;
//ThreadWidth = 0.40;
Protrusion = 0.9;
HoleWindage = 0.25;

// Dimensions
Post = [3.86,3.86,3.0];
OD = 0;
HEIGHT =  FootHeight;
DOMEHEIGHT = 1;
Button = [12,0+Post[2],6*ThreadThick];
NumSides = 8*4;
//----------------------
//- Build it

difference() {
union() {
    //retension ring
    translate([0,0,4*Thick])
    cylinder(d=Cdia+Thick,h=Thick,$fn=NumSides);
    //dome 
    translate([0,0,0])
    resize([0,0,2*Button[DOMEHEIGHT]])
    sphere(d=(Cdia-m/2)/cos(180/NumSides),$fn=NumSides);
    //Post
    cylinder(d=Cdia-m/2,h=FootHeight,$fn=NumSides);

}
//retension hole
translate([0,0,(FootHeight-Post[2]/2) ]){
    cube(Post + [HoleWindage,HoleWindage,Protrusion],center=true);
}
}
}
}


/////////////////////////// <- Main part -> /////////////////////////



if(GPAD_TShell==1){
T_shell_part();

}


module centeredHeatSetInsert() {
translate([0,-60.05,0])
import( "imported_scadModels/flanged insert M4 D7.1 H9.11.stl",convexity=1);
}

if(HEAT_SET_INSERTS==1){

stud_distance_mm = 75;
sd = stud_distance_mm;
half_stud_distance_mm = sd/2;
hsd = half_stud_distance_mm;
insert_height = 6;
#color("gray")
translate([Length/2,Width/2,Height+0.2]) 
//    translate([0,0,insert_height/2+1])
translate([0,0, 0+1])
union() {
rotate([180,0,0])
translate([hsd,hsd,0])
centeredHeatSetInsert();
rotate([180,0,0])
translate([hsd,-hsd,0])
centeredHeatSetInsert();
rotate([180,0,0])
translate([-hsd,hsd,0])
centeredHeatSetInsert();
rotate([180,0,0])
translate([-hsd,-hsd,0])
centeredHeatSetInsert();
}
}



if((GPAD_BShell==1)){
GPAD_BShell_part();
}



if(RotaryEncoder ==1){
//RotaryEncoder
translate( [3*Thick+2,Thick+5,0])     
ButtonSwitch(1,RotaryEncoderXpos,RotaryEncoderYpos,RotaryEncoderDiameter); //RotaryEncoder  
}

if(BButton ==1){
//button
translate( [3*Thick+2,Thick+5,0])     
ButtonSwitch(1,muteButtonXpos,muteButtonYpos,muteButtonDiameter); //Mute Button
}

if(LED_Standoff == 1){
//(OnOff,Cx,Cy,Cdia,Cpitch,Cheight,Ccenter=false){ 
translate( [3*Thick+2,Thick+5,5]){//([-.5,0,0]){
LedSpacer(1,PCBLength-27.94,15.24,5,2.54,Thick+FootHeight+PCBThick/2+.1-6,false); //LED1      
LedSpacer(1,PCBLength-40.64,15.24,5,2.54,Thick+FootHeight+PCBThick/2+.1-6,false); //LED2
LedSpacer(1,PCBLength-53.34,15.24,5,2.54,Thick+FootHeight+PCBThick/2+.1-6,false); //LED3
LedSpacer(1,PCBLength-66.04,15.24,5,2.54,Thick+FootHeight+PCBThick/2+.1-6,false); //LED4
LedSpacer(1,PCBLength-78.74,15.24,5,2.54,Thick+FootHeight+PCBThick/2+.1-6,false); //LED5
LedSpacer(1,PCBLength-46.99,PCBWidth-FootPosX,5,2.54,Thick+FootHeight+PCBThick/2+.1-6,false); //LED6 power
}}
if(PCB_SIMPLE==1){
////////////- PCB only visible in the preview mode - /////////////////////    
translate([3*Thick+2,Thick+5,Thick+FootHeight+PCBThick/2+.1]){
rotate([0,0,90])translate([0,0,PCBThick-0.2]);//import("General Alarm Device Enclosure-GeneralPurposeAlarmDevicePCB 1.stl", convexity=3);
%cube ([PCBLength,PCBWidth,PCBThick]);
translate([PCBLength/2,PCBWidth/2,0]){ 
color("Olive")
rotate([0,0,90])
%text("SIMPLE PCB", halign="center", valign="center", font="Arial black") ;

}} // Fin PCB 
}

if(PWA_GPAD==1){
/////////////- PCB only visible in the preview mode - /////////////////////    
translate([3*Thick+2,Thick+5,Thick+FootHeight+PCBThick/2+.1]){
rotate([0,0,90])translate([0,0,PCBThick-0.2])import("General Alarm Device Enclosure-GeneralPurposeAlarmDevicePCB 1.stl", convexity=3);
%cube ([PCBLength,PCBWidth,PCBThick]);
translate([PCBLength/2,PCBWidth/2,0]){ 
color("Olive")
%text("PCB", halign="center", valign="center", font="Arial black");
}} // Fin PCB 
}
if(PWA_KRAKE==1){
/////////- PCB only visible in the preview mode -/////////////////    
translate([3*Thick+2  + translationVariable,Thick+5,Thick+FootHeight+PCBThick/2-.1]){
rotate([0,0,90])translate([0,0,PCBThick-0.2]);
rotate([0,0,90])translate([-55.88,17.78,0])
color(Couleur3)
import("imported_scadModels/KRAKE_PWArev2.stl", convexity=3);
}}

// Panneau avant - Front panel  <<<<<< Text and holes only on this one.
//rotate([0,-90,-90]) 
if(GPAD_FPanL==1){
translate([Length-(Thick*2+m/2),Thick+m/2,Thick+m/2])
FPanL();
}


//Panneau arrière - Back panel
if(GPAD_BPanL==1){
color(Couleur2)
translate([Thick+m/2,Thick+m/2,Thick+m/2])
B_panl_part();
}

// Module Section
//RoundBox(length = 100, width = 50, height = 30, radius = 10, resolution =50);




//This is the purchased part.
// This is a 2mm screw that connects the BShell to the TShell.
if (T_BShellScrew==1){

union(){ //sides holes
$fn=50;
translate([3*Thick+11,0,Height/2+4]){
rotate([90,0,0]){
import("parts_toPrint/MCMaster_Carr_Torx_Roundhead_Screw_99397A324.stl");
}
}
translate([Length-((3*Thick)+11),0,Height/2+4]){
rotate([90,0,0]){
import("parts_toPrint/MCMaster_Carr_Torx_Roundhead_Screw_99397A324.stl");
}
}
translate([3*Thick+11,Width-5,Height/2-4]){
rotate([90,0,0]){
import("parts_toPrint/MCMaster_Carr_Torx_Roundhead_Screw_99397A324.stl");
}
}
translate([Length-((3*Thick)+11),Width-5,Height/2-4]){
rotate([90,0,0]){
import("parts_toPrint/MCMaster_Carr_Torx_Roundhead_Screw_99397A324.stl");
}}}}//fin de sides holes


///////////////screw parameters///////////////////
ScrewDiameter=2.2;
ScrewLength=5+Thick;
Spacing=100;
module ScrewPocket(){
if (Krake_rev2_76mmSPK == 1)
cylinder (d=ScrewDiameter,h=ScrewLength+Thick,center=true);
}

///////////////////
module SpeakerBoxLid(){
if (Krake_rev2_76mmSPK == 1)
difference (){
translate ([SpeakerPositionX+Thick*5+5, SpeakerPositionY,SpeakerHeight_mm-ScrewLength]){
cube ([1.6*SpeakerDiameter_mm,       SpeakerDiameter_mm*1.5+10, Thick], center=true);
}
AllScrewPockets();
}}


if (SPKLid==1){
SpeakerBoxLid();
}
///////////////////////




module mp3_player(){
translate([44,42.5,19+4.8])cube([20.7,20.7,8.6]);

}


if(SPK==1){
color(c=[0,0,2.8])
translate([PCBLength*.91,PCBWidth*.82,3])

import("imported_scadModels/Speaker2W-SpeakerOutline.stl");
}
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

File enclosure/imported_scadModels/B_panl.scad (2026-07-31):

use <Util_modules.scad>
include <General_paramters.scad>
use <PartNumbering.scad>

PartName = "BPanl";
PartVersion = "V4.1";
Date = "26213";

B_panl_part();

module B_panl_part()
{
    difference(){
    Panel(Length,Width,Thick,Filet);
    
    if(NumberingSystem == 1){
    translate([1.25,50,20])rotate([90,0,90])
    numbering(0.9,4,PartName,PartVersion,Date);}
}
    // logo
 color("red")translate([-0.4,115+25,35-45])mirror([0,1,0])rotate([90,0,90])linear_extrude(height = 1, center = true, convexity = 10)
   scale(0.032)import (file = "KRAKE_3.dxf", layer = "0");
    color("red")translate([-0.8,130,39])mirror([0,1,0])rotate([90,0,90])linear_extrude(height = 1, center = false, convexity = 10)scale(0.1)import("PI-LogoTransparent.svg");
}
 
 
   

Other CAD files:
PWA_REV2/Parts/LogoPI/LogoFreeCAD.FCStd
PWA_REV2/Parts/S04B-XASK-1/S04B-XASK-1.FCStd
enclosure/imported_scadModels/U_Box_V104_General_Alarm_Device_button.step
enclosure/imported_scadModels/B_shell.scad
PWA_REV2/Parts/10K, BOURNS 3362P-103LF.STEP
PWA_REV2/Parts/12mmx12mm With Green cap.stp
PWA_REV2/Parts/2004A_ap214.STEP
PWA_REV2/Parts/94639A702_Off-White Nylon Unthreaded Spacer.STEP
PWA_REV2/Parts/BarrelJackSMD v3.step
PWA_REV2/Parts/BarrelJackSMD v3.stl
PWA_REV2/Parts/DFR0299--3DModel-STEP-56544.STEP
PWA_REV2/Parts/EC11E-05SW.STEP
PWA_REV2/Parts/HRO TYPE-C-31-M-12.step
PWA_REV2/Parts/LED 5MM TH WHITE.STEP
PWA_REV2/Parts/LED_Standoff_V104.step
PWA_REV2/Parts/Molex_01x02_1.25mm_0530470210_.stp
PWA_REV2/Parts/NotGood_XKB Connectivity U254-051N-4BH806.step
PWA_REV2/Parts/S04B-XASK-1/Cube.step
PWA_REV2/Parts/SOT23.STEP
PWA_REV2/Parts/TS6-THT-SQ.step
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

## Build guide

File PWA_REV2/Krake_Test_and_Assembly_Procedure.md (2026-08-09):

 
# ISO Title Page

```
------------------------------------------------------------------------------
iso title page>>

Document Title:       Krake Test and Assembly procedure Document
Project:              Krake Project
Document Type:        Test and Assembly procedure
Document ID:          KRK-DOC-001
Version:              v0.2.0
Date:                 2026 - 02 - 08
Author(s):            Forrest Lee Erickson BS of Science, Physics.
                      Nagham Kheir BE in Electric and Electronics emphasis on Biomedical
                      Courtney Ludick MEng Biomedical Engineering
Status:               Draft
------------------------------------------------------------------------------
```

## Revision History

| Version | Date | Author | Description |
|---:|---|---|---|
| v0.1.0  | 2025-11-30 | Nagham Kheir  | Initial draft |
| v0.2.0  | 2026-02-08 | Courtney Ludick | Added architecture diagram & additional information added |
| v1.0.0  | YYYY-MM-DD | [Author Name] | Finalized for publication |

## 1. Abstract
Instructions to test the sub assembly units when received from the manufacturer. And instructions to add additional components to the sub assembly `PCB_KRAKE_REV2.0` to build the final assembly of PWA and speaker into enclosure.

## 2. Purpose
This document is written for a technician and describes the steps for testing and finishing the assembly of the Krake PWA (Printed Wiring Assembly) Rev 2.

## 3. Scope
This document describes how to take the sub assembly received from the contract manufacturer, and add the additional components (Mini MP3 player, SD card, LCD and the LEDs with their spacers) and electrical testing and functional testing. This document describes how to load factory test firmware and finaly product production firmware (the firmware the end user gets). This document also describes the final assembly of the PWA and a speaker into an enclosure.
This document does not describe troubleshooting.

## 4. Definitions and Abbreviations

| Term | Definition |
|---|---|
| Krake | [Definition] |
| API | Application Programming Interface |
| DFP layer | A Mini MP3 player, DFP layer is by DF Robot, a more generic term is Mini MP3 Player.|
| ESD | Electro Static Discharge, damage caused by over voltage. |
| LCD | Liquid Crystal Display |
| PCB | Printed Circuit Board, typically a fiberglass panel with copper traces but to which electronic comments are NOT yet attached.  |
| PWA | Printed Wiring Assembly, a PCB with components soldered / attached |
| Sketch | the Arduino vocabulary for source code file of the type used in the Arduino IDE and typically ending with the extension ".ino". |
| ... | ... |

## 5. Background
This document was developed from the similar document of the GPAD (General Purpous Alarm Device) found at: https://github.com/PubInv/general-purpose-alarm-device/blob/main/Hardware/Documentation/ManufacturingUnitTestTroubleshootingRev2.md
Additional notes from the Krake issue: ?TBD?

## 6. Technical Description / Methodology
Detailed description, architecture, procedures, protocols, etc.

## 7. Results or Discussion
Data, analysis, or discussion if applicable.

## 8. References
List of documents, papers, links, GitHub issues, etc.

## 9. Appendix (Optional)
Supplementary figures, tables, or data.

```
<<< end of iso title page
------------------------------------------------------------------------------
```

# Krake: PCB Rev 2.1

## Hardware in context

Krake is a network-connected alarm annunciator built around an ESP32 microcontroller, an LCD display, DFPlayer-based audio output, status LEDs, and a rotary encoder plus mute button for user interaction. It is intended as a flexible, open-source option for proprietary alarm panels and annunciators in clinical and research environments, particularly where alarms must be aggregated, prioritized, and presented across multiple beds or devices.

The device is designed to:

- Integrate with open communication protocols (e.g., Wi-Fi and MQTT) for alarm and status messages.
- Provide audible and visual alarms with configurable patterns and volumes.
- Serve as a testbed for alarm logic and human–machine interface experiments, especially in open, collaborative research.

This article focuses on the Rev 2.1 PCB manufactured by PCBWAY and the corresponding assembly, electrical testing and factory test procedure for a batch of twenty units (US0006–US00015, LB0006–LB00011, LDN0001–LDN0005).

## Hardware description

Krake Rev 2.1 consists of:

- A custom ESP32-based PCB with power conversion, level shifting, and IO conditioning.
- A 20x4 character LCD for displaying alarm state and device information.
- An audio subsystem built around a DFPlayer-compatible MP3 module and an external speaker.
- User interface components, including a rotary encoder (with push-switch) and a dedicated mute button.
- Status and alarm LEDs to indicate power, connection state, and alarm categories.

## Bill of materials

*If your bill of materials is long or complex, you can upload the details in an editable spreadsheet (e.g., ODS, Excel, or PDF file) to an open access online location, such as the [Open Science Framework](https://osf.io/) repository.*

## Bill of materials summary

Start with receiving the subassembly KRK-PL-0002 (Krake Rev2.1 PCB, plus BOM-TBD, plus placement

| Qty | Reference(s) | Value | Datasheet | Cost | Description |
|---:|---|---|---|---:|---|
| 1 | KRK-PL-0001 | Subassembly, Krake Contract Manufacture | ~ | 217 $ /5 | As built from parts list PCBWay |
| 1 | BZ601 | Speaker | ~ | 1 $ | 8 Ohm 2W Speaker, 28mm |
| 1 | J603 | DFPlayermini | [DFPlayer Mini Manual](https://image.dfrobot.com/image/data/DFR0299/DFPlayer%20Mini%20Manul.pdf) | 3.5 $ | Mini MP3 Player |
| 1 | SD601 | Micro_SD_Card_16GB | -- | 7 $ | SanDisk 16GB SDHC SDSDB-016G |
| 1 | D105 | LED_RED | [Lite-On RED LED](http://optoelectronics.liteon.com/upload/download/DS20-2005-253/LTW-2R3D7.pdf) | 0.2 $ | LED RED CLEAR T-1 3/4 |
| 5 | D201–D205 | LED_WHITE | [Lite-On WHITE LED](http://optoelectronics.liteon.com/upload/download/DS20-2005-253/LTW-2R3D7.pdf) | 1 $ | LED WHITE CLEAR T-1 3/4 |
| 4 | MF403, MF406, MF409, MF412 | Nut_4-40_0.1875 | [Keyelco Datasheet](https://www.keyelco.com/userAssets/file/M65p135.pdf) | $0.10 | #4-40 Hex Nut, 3/16\" Steel |
| 1 | U302 | LCD_20x4_Character | -- | 5 $ | LCD 2004 20x4 Module |
| 4 | MF401, MF404, MF407, MF410 | Screw_4-40_0.375 | [McMaster-Carr](https://www.mcmaster.com/catalog/128/3306) | 1 $ | 4-40 Phillips Pan Head, 3/8\" |
| 4 | MF402, MF405, MF408, MF411 | Spacer_0.1875x0.125 | [McMaster-Carr](https://www.mcmaster.com/catalog/128/3306) | 1 $ | Nylon Spacer, 1/8\" Length |
| 6 | MF103, MF601–MF605 | LED_Standoff | -- | NA | General Alarm LED Standoffs |
| 1 | MF801 | ENCLOSURE_KRAKE_VER1 | [McMaster-Carr](https://www.mcmaster.com/catalog/128/3306) | 0 $ | Plastic Enclosure |
| 1 | MF802 | PCB_KRAKE_VER1 | Gerbers2501181555.zip | 35 $ /5 | PCB for Krake Rev 2.1 |
| 2 | MF701, MF702 | Jackscrews_4-40 | [McMaster-Carr](https://www.mcmaster.com/catalog/128/3306) | 0 | Male–Female Cylinder Jackscrew |
| 1 each | ENC801–ENC806 | Enclosure Parts | -- | -- | Top/bottom/front/rear panels, knob, mute cap |
| 4 | MF807–MF810 | Screw_#6x1/2 | -- | 0.5 $ | PanTorx Self-Tapping |
| 4 | MF803–MF806 | Screw_2-32x3/8 | -- | 0.5 $ | Self-Tapping Phillips Pan Head |
| 1 | LB801 | Krake_Model_Serial | -- | 0 $ | Serial Number Label |

*Additional details may be found in the source design files. Material types and categories can be added in extended tables as needed.*

# Build instructions

This section documents the procedure used to complete assembly of Krake Rev 2.0 units from partially assembled boards from a contract manufacturer.

## Tools required

The following tools are required for through-hole assembly and rework:

- Sharpie or other indelible pen.
- Box cutter or similar.
- Soldering station with appropriate ventilation.
- 3/16 or 7/32 inch nut driver for the nuts on the LCD screws.
- #1 Phillips screwdriver.
- Diagonal or other flush-cutting hand tool for trimming leads.
- Basic ESD protection (wrist strap, mat) appropriate for handling microcontrollers and logic ICs.
- Assembly fixture or simple mechanical support to hold the PCB during soldering (optional but recommended).

### An Assembly Fixture
For the GPAD, We made an assembly assistant / fixture by using a raw PCB with some long #6 screws and nuts to hold at the PCB mounting points.  This same test fixture can be used for the Krake.
Assembly Fixture View 1, no LCD  

In addition four 4.40 screws with washers and 4-40 nuts to make a 1/8" spacer for holding the LCD and header for soldering.
Assembly Fixture View 2, With LCD  

An alternative is to make a 3D printed test bench
  
The file for which is here:
[Platform_PWA-Part_PlatformPWABody_PlatformPWA20260114.zip](https://github.com/user-attachments/files/24619821/Platform_PWA-Part_PlatformPWABody_PlatformPWA20260114.zip)

### LCD Bezel Grounding
On the LCD module locate the J1 and J2 solder pads which if soldered ground the bezel.  
 View of J1 and J2.  
Solder them.  
 Solder on of J1 and J2.    
As soldered.
NOTE, not all LCD modules have J1.  This LCD module has only J2 pictured with solder on J2.  


### Load MP3 Files to SD Card
For each Krake assembly, load into a microSCHC Flash card several MP3 files. 
The files must be loaded in a specified order.
The files are found at: [https://drive.google.com/drive/u/1/folders/1j0NoWhTwpoMUFePJHcl5dvErf954-mCs](https://drive.google.com/drive/folders/1uwaVFpFQ0uJbVLxVXngsslgTf2tzOCR6?usp=sharing)
There is a script file there, copy_to_sd.sh which on a Windows PC can copy the files in the required order to a microSCH Flash card.
Run copy_to_sd.sh from the bash shell, by typing "./copy_to_sd.sh"

Screen shot of file explorer view of a programed card.  
image of Krake MP3 files on an SD card  
Note these files do not display in the order in which they were written.


This is a screenshot of successful copying of files.

## Unpacking procedure and Serial Numbering

The contract manufacturer order (approximately September 2025) provided partially assembled PCBs with all SMT components and some through-hole parts installed. These are referred to as sub-assemblies KRK-PL-0001.

Remove unit from shipping carton.

On the first unit, confirm that the PCB is marked as Rev 2.0 (or the revision for which this procedure is valid).

Create the unit’s serial number using the factory form at:  
https://nk25719.github.io/krakeFactory/factory-form.html

Print the QR Model-Serial Number label, quantity TBD.

Each PCB has a designated silkscreen area for the serial number. The assembler should:

1. Attach the model - serial number label at the provided location on the PCB.
2. Record the serial number in the manufacturing log along with the date, assembler, and test status.

The Public Invention test and assembly records database is at:  
https://nk25719.github.io/krakeFactory/records.html

Make a photograph of the unit, front and back with the model-serial QR code applied.

## Incoming Sub-assembly Inspection

Before any additional soldering:

1. Visually inspect each PCB for:
   - Obvious mechanical damage (cracks, severe warping).
   - Bent, missing, or misaligned through-hole parts.
   - Solder bridges on SMT components or incomplete joints.
   - Test 976: Inspect for correct polarity on polarized parts (Electrolytic capacitors, Integrated Circuits, Diodes). See Figure 1 below image: Inspection1, component locator.

2. Confirm that the PCB is marked as Rev 2.1 (or the revision for which this procedure is valid).

Inspect for polarity  
Inspection1

### Time to start soldering

At this point install the MP3 Player sockets and the MP3 Player.

### DFPlayer module in sockets

Solder at the MP3 Player, two 1×8 socket headers at J603.


The MP3 player audio module is installed using sockets to simplify rework and replacement.


#### MP3 Header Install Steps

1. Install the DFPlayer header or socket into the designated footprint on the PCB.
2. Solder the header pins from the bottom side of the PCB.
3. On the LCD side of the PCB, trim the DFPlayer header leads so that they are flush or slightly below the surface and cannot contact the LCD module when installed.

Test the MP3 Player.

# Electrical Testing

This section describes the validation of Krake units at the end of assembly. It includes electrical safety checks (unpowered and powered tests).

## Unpowered resistance tests

Before applying power, the following resistance measurements are taken between test points and ground (TP101). The goal is to detect shorts that could endanger the power supply or the DUT.

### Measurement procedure

1. Use a digital multimeter capable of measuring resistance into the megaohm range.
2. Record the make, model, and serial number of the test instrument in the manufacturing log (for example, ASTRO DM6000AR, SSD card/N 2327610969 for units assembled in the USA).
3. For each device under test (DUT), measure:
   - TP100–TP101 (Controller V\(_\mathrm{CC}\) to GND).
   - TP103–TP101 (+5 V to GND).
   - TP102–TP101 (Vin to GND).
   - TP302–TP101 (+12in).
   - TP201–TP101 (VBus to GND).
   - TP202–TP101 (V3 to GND).

Test point locator:

Test Points for Unpowered Tests


### Acceptance criteria

- None of the rails should be a hard short to ground.
- Vin (TP102) to GND should typically measure greater than 10 MΩ and appear capacitive.
- +5 V (TP103) to GND should also appear non-shorted and capacitive, often in the kiloohm range due to load network.
- V3 and Controller V\(_\mathrm{CC}\) should be non-shorted and may show a few hundred ohms due to on-board circuitry.

Example measurements for units showed:
| Test Point | Approximate Reading| 
|---:|---|
| TP100–TP101  | >10–15 MΩ ||
| TP103–TP101 | 1.09–1.12 kΩ.||
| TP102 -TP101  | > 10MΩ ||
| TP302–TP101  | OL ||
| TP201–TP101  | 1.00–1.15 kΩ. ||
| TP202–TP101  | 280–350 Ω ||

If any unit shows significantly lower resistance than these ranges, the board should be inspected and reworked before power is applied.

Here is the end of the tests before any soldering is done.

## Testing BEFORE LCD is assembled to the PWA.

Because the sockets for the Mini MP3 Player are covered by the LCD (once it is installed), we must therefore solder the sockets and test the Mini MP3 Player BEFORE we cover the solder connections with the LCD.

Steps:

- Solder in the Mini MP3 Player at J603
- Add speaker at J601 or J604
- Apply power at USB
- Make quick powered test. **STOP IF OVER VOLTAGE** on TP103 (5V) and TP100 (3.3V).
- Test Mini MP3 Player and Speaker procedure is below
- Navigate to krake\Firmware\factoryTest\FactoryTest_wMenu and open  `FactoryTest_wMenu.ino`
- Using USB to USB C cable to connect the PCB to the computer
- Using device manager identify which port the PCB is connected to.
- When in Arduino IDE, navigate to Tools-Port- select port the PCB is connected to
- Proceed to select the board - esp32 dev board
- Upload to the board and allow missing libraries to be identified, library specifications are below and discussed in issue #274
    + PubSubClient by Nick O'Leary
    + Aruinojson by Benoit Blanchon
    + LiquidCrystal I2C by Frank de Brabander
    + ESPEssentials by Stephan Rumswinkel
    + LittleFS_esp32 by lorol
    + RotaryEncoder by Matthais Hertel
    + DFRobotDFPlayerMini by DFRobot
- One upload is complete, navigate to the Serial Monitor within Arduino IDE
- Change the 'baud rate' to 115200
- Enter '4'- , '5'- , '6' - Speaker into the Serial Monitor
- After entering 6, the serial monitor will ask for confirmation of audio - enter Y/N to confirm or deny audio and pass or fail test
 

Video of  upload procedure how to access serial monitor and completion of DF player tests
https://github.com/user-attachments/assets/768d9384-23f0-49b5-ae81-178c29a44425

Finish Assembly: Solder the LCD and LEDs and continue powered testing.

## Powered DC measurements

After passing the unpowered tests, each unit is powered from a current-limited bench supply.  
The following tests are to confirm that the 5V and 3.3V regulators provide the correct output voltage.  
Additional tests verify that voltage is going through the decoupling resistors to the loads on the system (usually ICs).

### Measurement procedure

1. Connect the bench supply to J101 and set:
   - Voltage: between 8 V and 12 V (test values around 8.3–8.4 V are typical).
   - Current limit: less than 1 A, with 200–300 mA used as an initial safety limit.
2. Power on the device, measure and record the current draw.
3. On the serial monitor, run the LCD test to get characters on the LCD. Use test, "2 LCD (I2C)". With a small screw driver, adjust RV301 the CONTRAST poetntiometer for good character constrast. The current draw typicaly increases by about 0.02 Amps.
4. On the serial monitor, run the RS-232 test to get a negative voltage on TX, COM port pin 2, please see image "Locator for DB9 pins". Use test, "D RS-232 loopback".
5. Measure and record:
   - TP109, 3v3Controller supply to U102.
   - TP401, VccLCD supply for U301 and U302.
   - TP405, Vcontrast for the LCD.
   - TP100, 3.3 V at U103 regulator output
   - Test point "5esp32" the input to the 3.3 V regulator (U103 input).
   - TP103, +5 V from the +5V regulator U101
   - TP306, +5Vraw for SPI interface
   - TP501 Mini MP3 Player supply 5VDFP at C505+
   - TP205, 3V3USB power to CH340 USB to UART chip.
   - TP102, Vin into the +5V regulator U101.
   - TP201, VBus power in on USB connector
   - TP202, V3 on U501.
   - J701 pin 2 (DB9), charge pump output negative.
  
Test points:
Test Points for Powered Tests  
  
Locator for DB9 pins  
  

### Typical results and criteria

Typical passing units in the first batch showed:
| Test Point | Approximate Reading| 
|---:|---|
| TP109  | ~ 3.3V ||
| TP401  | ~ 5V ||
| TP405  | ~ 2.5V ||
| TP100  | ~ 3.3V ||
| 5ESP32  | ~ 5V ||
| TP103  | ~ 5V ||
| TP306  | ~ 5V ||
| TP501  | ~ 5V ||
| TP205  | ~ 3.3V ||
| TP102  | ~ 4.5V ||
| TP201  | ~ 5V ||
| TP202  | ~ 3.3V ||
| J701 pin 2 | ~ 6V ||

Units that deviate significantly from these ranges require investigation (e.g., reflow of regulators, inspection of shorts or opens on the relevant nets).
Spreadsheet to input results calculate averages , variation and deviance which can help identify if any results are anomalies.
[DC Powered Test - Spreadsheet Template.xlsx](https://github.com/user-attachments/files/25909312/DC.Powered.Test.-.Spreadsheet.Template.xlsx)

## LCD mounting

1. A quantity of four, nylon 1/8" spacers are placed at the four corners of the LCD sub module. One spacer may need to be trimmed to clear the roatary encoder.
2. Place the LCD module onto its header footprint, ensuring correct orientation.
3. Four 4-40 x 3/8" screws with 4-40 x 3/16" nuts go through both boards and are torqued to 3.4 - 4.8 Inch-Pounds. Hold the nut with an approprate wrench or nut driver.
4. Solder the LCD header pins to the PCB while maintaining the LCD flat and level.
  
 Soldering the LCD pins on the header.

## LED installation

The front panel LEDs provide visual alarm and status indication.

1. Identify the LED footprints on the PCB and the corresponding LED colors (e.g., white vs. red).
  - 5 white LED's (D201-D205)
  - 1 red LED - Power ((D103) .

3. For each LED:
   - Note the flat edge on the plastic body indicating the cathode.
   - 
   - Align the flat edge with the flat indicator on the PCB silkscreen.
   - Insert the LED spacer to ensure consistent height above the PCB - to do this 3D print and use 6 of the LED spacer files "U_Box_V105_GPAD_LED_Standoff_single.stl" within enclosure/parts_toPrint
     
   - Solder the leads.
     
   - Trim the leads carefully, taking care not to damage nearby transistors or other components.
4. To avoid mixing LED colors:
   - Install and solder all white LEDs first, then close and set aside their packaging.
   - Open the red LED packaging only when needed; install, solder, and trim them as a separate step.

# Operation instructions

This section covers basic procedures for powering Krake and verifying that the assembled hardware operates safely under firmware control.

## Power-up procedure

1. Connect a current-limited DC bench supply to connector J101 (Vin).
2. Set the supply to:
   - Voltage: between 8 V and 12 V (typical test value: 8.3 V).
   - Current limit: less than 1 A (typical safe upper bound: 200–300 mA for an unmuted system at idle).
3. Ensure the DFPlayer module, LCD, and all LEDs are installed.
4. Power on the bench supply and observe the current draw:
   - If current immediately rises to the current limit, power off and investigate for shorts.
   - Typical assembled boards draw on the order of 150–190 mA at 8.3–8.4 V during idle tests.
5. Once current is within an expected range, observe:
   - 5 V regulator output (~5.0 V).
   - 3.3 V regulator output (~3.3 V).
   - LCD backlight and any power/status LEDs.
     
  ## Factory Test Procedure
1. Navigate to krake\Firmware\factoryTest\FactoryTest_wMenu and open  `FactoryTest_wMenu.ino`
2. Using USB to USB C cable to connect the PCB to the computer
3. Using device manager identify which port the PCB is connected to - this may involve disconnecting and reconnecting the PCB to see which ports appear.
4.  When in Arduino IDE, navigate to Tools-Port- select port the PCB is connected to
5.  Proceed to select the board - esp32 dev board
6.  Upload to the board and allow missing libraries to be identified, library specifications are below and within issue #274
    + PubSubClient by Nick O'Leary
  + Aruinojson by Benoit Blanchon
  + LiquidCrystal I2C by Frank de Brabander
  + ESPEssentials by Stephan Rumswinkel
  + LittleFS_esp32 by lorol
  + RotaryEncoder by Matthais Hertel
  + DFRobotDFPlayerMini by DFRobot
  + AsyncTCP by esp32Async
  + ESPAsyncWebServer by esp32Async
  + ElegantOTA by Ayush Sharma
  + OneButton.h by Matthias Hertel
7. One upload is complete, navigate to the Serial Monitor within Arduino IDE
8. Change the 'baud rate' to 115200
9. Test response by sending [R] in the command window
10. Record MCU MAC address & factory firmware test version
    

11. Enter [P] into the Serial Monitor
12. After entering P, the serial monitor will ask for provide instructions for each of the tests to determine a 'PASS' or 'FAIL', this will include answering 'Y' or 'N' and performing tasks (if it is required to carry out any test individually , simply enter the corresponding number from the menu below into the serial monitor)

 
The Tests are as below - please read prior to performing tests to ensure you have all relevant information at hand  
- [0] Power/ ID 
  - No input required / no prompt message
     
- [1] Inputs (Encoder / Button)
  - Rotate encoder CLOCKWISE
  - Rotate encoder COUNTER-CLOCKWISE
  - Press the encoder button within 10 seconds
  
- [2] LCD (I2C)
  - Adjust the potentiometer (above the Power LED , labelled "CONTRAST") to adjust the constrast of the LCD to display the text using a small flathead screwdriver 
  - Do you see **4 FULL lines**, aligned, with no garbage characters?
  - Press **Y** to PASS or **N** to FAIL (Enter optional).

- [3] LEDs / Lamps
  - LAMP1 blink
  - Skipping LAMP2 drive (BUSY shared safety)
  - LAMP3 (LAMP3) blink
  - LAMP4 (LAMP4) blink
  - LAMP5 (LAMP5) blink
  - LED_Status (LED_Status) blink
  - Did you see the LEDs/Lamps blink as expected?
  - Press **Y** to PASS or **N** to FAIL (Enter optional).

- [4] DF Player & [5] SD (DFPlayer card)
  - No input required.

- [6] Speaker
  - Did you hear audio from the speaker?
  - Press **Y** to PASS or **N** to FAIL (Enter optional).

- [7] Wi-Fi AP
  - No input required.
  - Check SSID visible from phone / PC.

- [8] Wi-Fi STA (manual SSID/PASS)
  - Enter the name of your Wi-Fi.
  - Enter the password for your Wi-Fi.

- [A] LittleFS R/W
  - no input required

- [B] UART10 (USB Serial)
  - Confirm prompt can be seen.

- [C] SPI loopback
  > Verify SPI communication by connecting the Master Out Slave In (MOSI) pin directly to the Master In Slave Out (MISO) pin.
  > Physical Loopback (Hardware): Connect a jumper wire directly between the MOSI and MISO pins on your connector.
  - Connect MOSI <-> MISO on SPI header for automatic test: We will cut one of the rj12 connectors and then we short pins 6 and 2, check below image
  - The final step is to connect the SPI connector and run the test using the [C] command in the command window





- [D] RS-232 loopback
  - Use a short wire to connect **pins 2–3** on RS232.
  - Use a short wire to connect **pins 7–8** on RS232.


- [E] ElegantOTA 
  - Once factory test is complete copy ip address given during factory test into browser, ElegantOTA server will start. Browse to http://IP/update:
   > If the wifi needs to be setup: then you will go through: step [8] Wi-Fi STA (manual SSID/PASS)
  -  After Wi-Fi STA connected successfully. ElegantOTA server will start. Browse to http://IP/update:
  Example:  OTA endpoint: http://192.168.10.234/update
  -   Verify that you see the ElegantOTA upload page:
  

- [F] Mute Button + LED
  - Button: GPIO 35  |  LED: GPIO 13 (LED_Status))
  - Press the mute button twice. (q to quit)
  - Short tap = ignored (accidental push).
  - Hold too long = warning, try again.
     
## Final firmware validation - NK

After completing electrical and audio tests, each unit is loaded with the intended final firmware (e.g., `GPAD_API`) for field or system testing.

For each serial number:

1. Load the final firmware:   - Upload .bin files "Krake_fw_vx.x.x.bin" & "Krake_littlefs_X.XX.bin" using the ElegantOTA platform (X.XX references the version number of the files, please use the most recent version which can be found at /releases  (Root Level).

2. Record:
   - Firmware version string.
   - Date of final test and tester initials.
3. Perform a brief smoke test of:
   - Power-up behavior and LCD initialization.
   - Encoder and mute button operation.
   - At least one network interaction (e.g., connection to test Wi-Fi and MQTT broker if available).

Units that pass all steps above are considered ready for integration into larger Krake deployments or experimental setups.

## Enclosure Assembly Procedure
1. To begin the enclosure assembly navigate to "krake\enclosure\parts_toPrint", The following files within this folder are to be printed to assemble the enclosure. PLA or PETG at 0.2mm is recommended. 
  - "knob_Dshaft_15mmx6mmv1.3.stl"
  - "U_Box_V105_Krake_RevB_TSHELL_V3.stl"
  - "U_Box_V105_Krake_RevB_FPanL_V3.3mf.stl"
  - "U_Box_V105_Krake_RevB_BSHELL_V3.stl"
  - "U_Box_V105_Krake_RevB_BPanL_V3.3mf.stl"
  - "U_Box_V104_General_Alarm_Device_button"
  - "Recess_bottom.stl"
  - "SD_door.stl"
2. Once all parts have been printed, the following tools and parts are required to add the threaded insert into the VESA and Speaker Mount.
  - **insert information about tools etc for threaded inserts
  - Using M4 Threaded Inserts: 
  - After the threaded inserts are inserted, displaced plastic may obstruct the screws

  - To clear this use a 4mm tap from the inside of the enclosure


3. To assemble the enclosure the following is required:
  - "knob_Dshaft_15mmx6mmv1.3.stl"
  - "U_Box_V105_Krake_RevB_TSHELL_V3.stl"
  - "U_Box_V105_Krake_RevB_FPanL_V3.3mf.stl"
  - "U_Box_V105_Krake_RevB_BSHELL_V3.stl"
  - "U_Box_V105_Krake_RevB_BPanL_V3.3mf.stl"
  - "U_Box_V104_General_Alarm_Device_button"
  - "Recess_bottom.stl"
  - "SD_door.stl
  - 2 x D-Sub jack screws
  - 4 x M3 screws (minimum M3 x 8)
  - 4 x M4 
  - 4 x MACH SCREW PAN PHILLIPS #2-32
4. Begin by mounting the base plate (with the cut outs for COM, USB, Remote and DG) to the PCB using 2 x D-Sub jack screws onto the RS 232
  WhatsApp Image 2026-03-26 at 9 51 07 AM
5. Mount the rotary encoder knob and mute button onto the PCB
 WhatsApp Image 2026-03-26 at 9 51 07 AM (1)
6. Using the rails inside the TSHELL slide the PCB and base plate into the TSHELL ensuring the LCD, LED, mute button and rotary encoder line up with the corresponding cut outs.
7. Secure the PCB with 4 x M3 bolts
 WhatsApp Image 2026-03-26 at 9 51 08 AM
8. Using the rails at the top of the enclosure slide the top blank plate into place
9. Taking the speaker , align it with the holes within the speaker box and guide the cable through the hole to attach to the PCB
10. Taking 4 x M4 bolts for the speaker mount , secure the speaker to the TSHELL
  WhatsApp Image 2026-03-26 at 9 51 08 AM (5)
11. Slide the SD_door into the Recess_ Bottom ensuring the prongs and the lip on the door extrude in opposite directions
    WhatsApp Image 2026-03-26 at 9 51 08 AM (3)
  WhatsApp Image 2026-03-26 at 9 51 08 AM (2)
12. Taking the BSHELL, slide the Recess_bottom into the cut out with the prongs facing downwards
    
14. Proceed to mount the BSHELL & TSHELL together using the 4 MACH SCREW PAN PHILLIPS #2-32

**Ethics statements**  
*To be completed if human or animal data are involved (likely not applicable for this purely hardware manufacturing article).*

**CRediT author statement**  
*To be completed (e.g., Conceptualization, Methodology, Software, Validation, Writing, Supervision, etc.).*

**Acknowledgements**  
*To be completed with collaborators, institutions, and funding information.*

**References**  
*To be completed with references to related open hardware, alarm standards, and the Krake/GPAD repositories or previous publications.*

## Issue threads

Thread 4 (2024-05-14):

Lee Construct a Prototype Similar to Nagham's Prototype

ForrestErickson, 2024-05-14:
Lee will try to assemble prototype based on the documentation in the repository only.

ForrestErickson, 2024-09-29:
20240929 Slow progress being made.
Using SN: USA1
I2C LCD display is working
DFPlayer is not working.

ForrestErickson, 2024-10-07:
As of about 20241004 DFPlayer working with delays to allow the TD5580A time to respond.

ForrestErickson, 2025-02-09:
Back in about November Lee added a rotary encoder and demonstrated it worked when wired per the Krake schematic.
The encoder was mounted on a 3D printed bracket. File location: https://github.com/nk25719/PMD___aka-KiCad-esp32-6leds-2switches-1pj-circuit-/blob/main/Enclosure_and_Workbench/LCD20x4_RotaryEncoder.FCStd

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

Made a sketch to test and debugged the double counting issue discovered with the default code.
Fixed Code:
https://github.com/PubInv/krake/issues/118

See also issue 5
https://github.com/PubInv/krake/issues/5
See also issue 9
https://github.com/PubInv/krake/issues/9
See also issue 20
https://github.com/PubInv/krake/issues/20

Closing as done.

Closed 2025-02-09.

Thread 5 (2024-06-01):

Add a Rotary Encoder with Switch to Krake

ForrestErickson, 2024-06-01:
_(On 20241302 rework this capturing better from a duplicate issue (#20) which was better written.)_

**Is your feature request related to a problem? Please describe.**
_A clear and concise description of what the problem is. Ex. I'm always frustrated when [...]_
A controller to navigate through the functions of Krake

**Describe the solution you'd like**
_A clear and concise description of what you want to happen._
adding an encoder to mocking krake

**Describe alternatives you've considered**
_A clear and concise description of any alternative solutions or features you've considered._

**Additional context**
_Add any other context or screenshots about the feature request here._

## Original summary
 Feature Request:
A rotary encoder will enable development of a more interactive UI.

nk25719, 2024-06-01:
Let us consider the touch screen possibility and compare the advantage and disadvantages of each of these two features.

nk25719, 2024-08-18:
**Is your feature request related to a problem? Please describe.**
A clear and concise description of what the problem is. Ex. I'm always frustrated when [...]
_Missing hardware that can control the UI of Krake_

**Describe the solution you'd like**
A clear and concise description of what you want to happen.
_Use Rotary knob switches that use a rotating mechanism to select,  send emergency and navigate  and establish connections in the UI of Krake._

ForrestErickson, 2024-10-02:
From the duplicate #20

History of this issue is that it started in another repository, the **KiCad-esp32-6leds-2switches-1pj-circuit** here:
https://github.com/nk25719/KiCad-esp32-6leds-2switches-1pj-circuit/issues/42

@nk25719 has created firmware at:
krake\Firmware\factoryTest\Rotarty Encoder\RotaryEncoderTest

This firmware interfaces the encoder at the following pins:
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

Here is a reference to an interrupt driven Rotary Encoder example:
https://www.instructables.com/How-to-Use-Rotary-Encoders-and-Interrupts-With-You/

Note issue #20 now closed.

ForrestErickson, 2024-11-21:
@nk25719
As of 20241121 The schematic for the Krake has used GPIO25 and GPIO26 on the SPI input.

The Mocking Krake must be modified and rotary encoder firmware to test with the encoder on other pins.

ForrestErickson, 2024-11-23:
@nk25719
Candidate JLCPCB part: https://jlcpcb.com/partdetail/Alpsalpine-EC11E18244AU/C202365

nk25719, 2024-11-30:
Schematic of the rotary encoder added to Krake:
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

Rotary Encoder properties:
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

nk25719, 2024-11-30:
cc: @ForrestErickson

.
.

Closing.

nk25719, 2024-12-21:
Reopenning issue to:

Schematic connections changed, capturing connections Dec 21 2024,
Implement the Rotary encoder connections into MockingKrake
Write firmware to test the current Rotary encoder connections before PWA subassembly release.

nk25719, 2024-12-21:
Schematic connections changed, capturing connections Dec 21, 2024.

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

nk25719, 2024-12-23:
Connected the Rotery encoder to prototype Krake with it,
pin connection as above shcematic.

ForrestErickson, 2024-12-24:
As of 20241224 we have added an encoder to the MockingKrake in Maryville and in Lebanon and demonstrated encoder and switch function on the pins as assigned in the Krake schematic.
There is an unresolved firmware problem with double incrementing on the encoder rotation but the hardware works.

Closing.

Closed 2024-12-26.

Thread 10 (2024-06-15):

Use Hardware UART2

nk25719, 2024-06-15:
**Is your feature request related to a problem? Please describe.**
_A clear and concise description of what the problem is. Ex. I'm always frustrated when [...]_
The sketch uses a software UART for the DF player.  This consumes resources.
Change the code for the hardware UART on the DF player.

**Describe the solution you'd like**
_A clear and concise description of what you want to happen._
Rely on the hardware software connection (pin#16, pin#17).

**Describe alternatives you've considered**
_A clear and concise description of any alternative solutions or features you've considered._
NONE

**Additional context**
_Add any other context or screenshots about the feature request here._

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

> Screenshot of the ESP32 devkit

nk25719, 2024-08-18:
Using the hardware UART pins (16 and 17) of the ESP32, and utilizing the hardware serial capabilities of the ESP32 instead of using the SoftwareSerial library is more efficient . This can improve communication reliability and performance.

```
#include <WiFi.h>
#include <WebServer.h>
#include <DNSServer.h>
#include <HTTPClient.h>
#include <DFRobotDFPlayerMini.h>
#include <LiquidCrystal_I2C.h>
#include <Wire.h>
#include <WiFiManager.h>

// Hardware serial for DFPlayer
HardwareSerial mySerial1(2); // Use UART2, (16, 17 are RX2, TX2)

// Global initialization remains the same
const char* server_address = "192.168.1.3";
const int serverPort = 5500;
const int analogPin = 34;
const int MUTE_BUTTON_PIN = 36;
const int ON_OFF_BUTTON_PIN = 39;
#define LED_PIN 2
const int lamp1Pin = 15;
const int lamp2Pin = 4;
const int lamp3Pin = 5;
const int lamp4Pin = 18;
const int lamp5Pin = 19; // Note: You had duplicate pin definitions for lamp5Pin; you need to resolve this.

DFRobotDFPlayerMini myDFPlayer;
LiquidCrystal_I2C lcd(0x3F, 20, 4);
WebServer server(80);
DNSServer dnsServer;

// Other variables are defined as before

void setup() {
    Serial.begin(115200);
    mySerial1.begin(9600, SERIAL_8N1, 16, 17); // Set baud rate and UART pin numbers

    pinMode(MUTE_BUTTON_PIN, INPUT_PULLUP);
    pinMode(ON_OFF_BUTTON_PIN, INPUT_PULLUP);
    pinMode(LED_PIN, OUTPUT);
    digitalWrite(LED_PIN, LOW);

    // Initialize lamp pins
    pinMode(lamp1Pin, OUTPUT);
    pinMode(lamp2Pin, OUTPUT);
    pinMode(lamp3Pin, OUTPUT);
    pinMode(lamp4Pin, OUTPUT);
    pinMode(lamp5Pin, OUTPUT);

    // Access Point, DNS, Web Server, and DFPlayer initialization remains the same

void loop() {
.
.
.
void startDFPlayer() {

  // Start DFPlayer using hardware serial
    if (!myDFPlayer.begin(mySerial1)) {  // Use mySerial1 instead of mySoftwareSerial
        Serial.println("Unable to begin:");
        Serial.println("1. Please recheck the connection!");
        Serial.println("2. Please insert the SD card!");
        while (true);
    }
    myDFPlayer.setTimeOut(500); // Set serial communictaion time out 500ms
    myDFPlayer.volume(25);  // Set initial volume
    myDFPlayer.EQ(0);  // Normal equalization
    Serial.println("DFPlayer initialized");
}
.
.
.
}

Rest of the code...
```

nk25719, 2024-09-30:
[](url)
[https://github.com/PubInv/krake/blob/main/Firmware/20240421.V2/Krake_arduinoIDE_V2/Krake_arduinoIDE_V2.ino](url)

Closing..

Closed 2024-09-30.

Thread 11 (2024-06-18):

Fault Tolerant Firmware for the loss of WiFi

nk25719, 2024-06-18:
**Is your feature request related to a problem? Please describe.**
_A clear and concise description of what the problem is. Ex. I'm always frustrated when [...]_
Loss of WiFi will cause the system to stop opperating.

**Describe the solution you'd like**
_A clear and concise description of what you want to happen._
Indicate the loss of WiFi and automatically reconnect to WiFi when it is available.

**Describe alternatives you've considered**
_A clear and concise description of any alternative solutions or features you've considered._
An Icon that is displayed on the LCD that indicates the connectivity to WiFi.

**Additional context**
_Add any other context or screenshots about the feature request here._

nk25719, 2024-08-18:
Krake will constantly check for WiFi connection and incase the connection is lost the Krake will restart and thus we will be submitted back to the wifi manager page where our Krake acts as an AP and allow us to connect to the available WiFi

```
void loop() {

    server.handleClient();

void checkWiFiConnection() {
    if (WiFi.status() != WL_CONNECTED) {
        Serial.println("WiFi lost, reconnecting...");
        WiFiManager wm;
        if (!wm.autoConnect("ESP32_AP")) {
            Serial.println("Failed to connect");
            ESP.restart();
        }
    }
}
```

ForrestErickson, 2024-10-25:
@nk25719
Two questions

## Have you tested this?
Two ways. Shield or walk away from the WiFi.
Plus another way, to monitor RSSI.

### Sheild
Put in in a stand alone sketch with perhaps the Wink heart beat.  Change the rate of the heart beat if the WiFi connection is true versus false.
Then you must test it by breaking the WiFi connection. How will you do that?  You might try shielding the device under test (the DUT) from RF connection. How will you do that.? Put a metallic shield around the device. How will you do that, Wrap the DUT with some kind of insulator like a paper bag but with a small hole so you can see the LED.. Then around that wrap aluminum foil which is attached to around it but for a small hole so you can see the LED.
As you close the foil does the device loose WiFi? Open the foil. Does the device recover WiFi?
Record the results for several trials

### Walk Away.
Put in in a stand alone sketch with perhaps the Wink heart beat.  Change the rate of the heart beat if the WiFi connection is true versus false.
With the device Battery powered test as follows:
Walk it away from the WiFi router.  Does the device loose WiFi?
Return to the WiFi router  Does the device recover WiFi?
Record the results for several trials.

### Monitor
The WiFi library likely has a function which reports RSSI, Which is an acronym for Received Signal Strength Indicator.
Make a sketch which in addition to a heart beat has a USB-Serial port report and an MQTT publish of the RSSI.  Shield the DUT or walk the DUT away and record the results as above.

## Have you integrated it into some form of the Krake firmware?
If not

nk25719, 2025-07-05:
Integrated OTA and Wifi Manager:
https://github.com/PubInv/krake/blob/main/Firmware/GPAD_API/WiFiManagerOTA.cpp

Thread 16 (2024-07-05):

ADD GPIO PIN NAMES FOR THE ESP32

nk25719, 2024-07-05:
In addition to the pin numbering, it is recommended to include the GPIO pin numbers in the ESP32 kit schematic, as GPIO pin numbers are usually used when programming the ESP32.

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

nk25719, 2024-07-06:
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

> ADDED GPIO PIN NAMES

Closed 2024-07-06.

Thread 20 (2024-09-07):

Prototype a Rotary Encoder

nk25719, 2024-09-07:
**Is your feature request related to a problem? Please describe.**
A clear and concise description of what the problem is. Ex. I'm always frustrated when [...]
A controller to navigate through the functions of Krake

**Describe the solution you'd like**
A clear and concise description of what you want to happen.
adding an encoder to mocking krake

**Describe alternatives you've considered**
A clear and concise description of any alternative solutions or features you've considered.

**Additional context**
Add any other context or screenshots about the feature request here.

nk25719, 2024-09-07:
https://github.com/nk25719/KiCad-esp32-6leds-2switches-1pj-circuit/issues/42

ForrestErickson, 2024-10-01:
@nk25719 has created firmware at:
krake\Firmware\factoryTest\Rotarty Encoder\RotaryEncoderTest

This firmware interfaces the encoder at the following pins:
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

ForrestErickson, 2024-10-02:
This appears to be a duplicate to issue #5.

The information in this issue should be copied into #5 and this issue closed as a duplicate.

If we, the team, had been more diligent reviewing issues this duplicate might have been found earlier.  This is symptomatic of not using the project board and issues enough.

ForrestErickson, 2024-10-02:
20241002 Lee copied the content from this issue into the older issue #5

ForrestErickson, 2024-10-02:
Closing as duplicate

ForrestErickson, 2024-12-24:
20241224 Done.

Closed 2024-10-02.

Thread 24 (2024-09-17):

Feature Request Learn And Implement "Over The Air Update"

ForrestErickson, 2024-09-17:
**Is your feature request related to a problem? Please describe.**
_A clear and concise description of what the problem is. Ex. I'm always frustrated when [...]_

The PMD assemblies will be repurposed in many configurations during development.
We may ship some to persons with out the skill set for Arduino IDE or MSCode loading of firmware.  Learning and implementing "Over the Air Update" may be helpful.

**Describe the solution you'd like**
_A clear and concise description of what you want to happen._
Teach developers how to use the Over The Air Libraries.
Load simple blink sketches.
Load factory test sketches.
Load PMD sketches.
Load Krake sketches.

**Additional context**
_Add any other context or screenshots about the feature request here._
Random Nerd Tutorials are often a good place to start.
Here is one on OTA:  https://randomnerdtutorials.com/esp32-over-the-air-ota-programming/

## Deluxe Feature, WiFi Manager
Even better would be to integrate the OTA with WiFi Manager

ForrestErickson, 2024-09-17:
Here is an OTA integrated with a WiFi Manager.

https://github.com/erkobg/WiFiManager-OTA

ForrestErickson, 2025-03-18:
## Notes on OTA Development
On 20250317 Nagham and Lee made two sketches with OTA.
Lee's sketches are not committed.
Sketch **OTAWebUpdater_Maryville** has a loop with no functions. The log in web page and server (upload) web page are modified to display a header line of  "Best PMD Ever!"
Sketch **OTA_Blink** has a loop function which blinks the LED on pin 2. The log in web page and server (upload) web page are modified to display a header line of  "Best BLINKER Ever!"

When the Arduino IDE "Exports Compiled Binary" files it is into a folder of the sketch with name "..build\esp32.esp32.esp32".
There are several binary files generated. The file with which to update is the file with the sketch name and "..ino.bin". So for the **OTA_Blink** sketch the file is "OTA_Blink.ino.bin".
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

## Notes on OTA behavior.
### Timing of upload to reboot.
Start with the device is loaded with **OTAWebUpdater_Maryville** the build in LED is not blinking. When the user selects the bin file for "Best BLINKER Ever!" (OTA_Blink.ino.bin)
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

Start timing from the press of the "Update" button.
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
The update becomes 100% in approximately five seconds.
About six seconds later the build in LED begins flashing.

Total time was about 11 to 12 seconds.

ForrestErickson, 2025-03-18:
#  AsyncElegantOTA - A Superior OTA Library and Methods
This RNT article is about a better OTA library.
ESP32 OTA (Over-the-Air) Updates – AsyncElegantOTA using Arduino IDE
https://randomnerdtutorials.com/esp32-ota-over-the-air-arduino/

**IMPORTANT:** Note how the HTML , CSS and so on files are easier develop and therefor to manage in the examples.

nk25719, 2025-07-06:
In Krake

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

nk25719, 2025-07-06:
Integrated OTA in Krake and in PMD. Closing.

Closed 2025-07-06.

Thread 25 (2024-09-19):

DFPlayer Code in V1 & V2 has a long "delay" which is dangerous

RobertLRead, 2024-09-19:
Probably, the Arduino freezes completely for 10 minutes in the current code.
Short Summary of the expected behavior:
We would like the "mute" and "unmute" functions to be usable at any time.

Short Summary of the buggy behavior:
Probably when you mute, you can't unmute for 10 minutes.

To Reproduce
Steps to reproduce the behavior:
1. Start playing an alarm.
2. Mute
3. Observe that you cannot unumte for 10 minutes.

Expected behavior
Toggling between muted and unmuted behaviour is possible at any time and that it happens within about 100 ms.

Screenshots
The delay below is likely problematic:

`
    if (trackPlaying) {
        myDFPlayer.pause();
        trackPlaying = false;
        // Allarm paused for 10 minutes
        delay(600000); // 10 minutes delay
        Serial.println("ALLARM Paused.");
        lcd.clear();
        lcd.setCursor(0, 0);
        lcd.print("Alarm Paused");
    } else {
`

Hardware description
This occurs on the MockingKrake/PseudoMedicalDevice (PMD)

Additional context
Nagham now has a better understanding of using timers to avoid long delays.

nk25719, 2024-09-20:
## Exercised these examples in
https://github.com/nk25719/KiCad-esp32-6leds-2switches-1pj-circuit/tree/main/FIRMWARE

## One of the examples:
FIRMWARE/BlinkWOdelay_jul16c/BlinkWOdelay_jul16c.ino

Solving this in V2
you can find it at:
https://github.com/PubInv/krake/tree/main/Firmware/20240421.V2

ForrestErickson, 2024-10-02:
Speculation:
The long delays in the code which Lee thinks was inherited from examples found on line my be symptomatic of the DFPlayer requiring long delays between command writes.  The implication is that many DFPLayers require long delays not just the TD5580A based players.

ForrestErickson, 2024-10-04:
Much information about the DFPlayer is to be found in this issue of the PMD aka KiCad-esp32-6leds-2switches-1pj-circuit aka homework2 PCB / PWA

https://github.com/nk25719/KiCad-esp32-6leds-2switches-1pj-circuit/issues/55

ForrestErickson, 2024-10-14:
Here are some easy to read notes about DFPlayers
https://reprage.com/posts/2018-05-08-dfplayer-mini-cheat-sheet/

## Copying MP3 Files to SD Card
The script after this note looks useful.

> I had a bunch of MP3 files and micro SD cards to produce, so I made a little script to make it a bit easier (I had all my sequentially numbered files on the desktop in a folder titled ‘soundFiles’):

```
#!/bin/bash
mkdir /Volumes/MUSIC/mp3
for filename in ~/Desktop/soundFiles/*.mp3; do
  cp $filename /Volumes/MUSIC/mp3/
done
dot_clean /Volumes/MUSIC

```

ForrestErickson, 2025-04-25:
Long since removed.
Closing.

Closed 2025-04-25.

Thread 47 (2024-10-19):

Add SPI Interface as Peripheral (Formerly Slave)

nk25719, 2024-10-19:
**Is your feature request related to a problem? Please describe.**
_A clear and concise description of what the problem is. Ex. I'm always frustrated when [...]_
If the Krake™ is to be a replacement for the GPAD, it must be possible to be controlled by SPI interface just as the GPAD was.
The GPAD interface is a 5V logic level.

**Describe the solution you'd like**
_A clear and concise description of what you want to happen._
 Add an SPI (Serial Peripheral Interface) to communicate with peripheral devices
Serial Peripheral Interface is a four wire  interface for bidirectional logic level connection from a Controller to a Peripherial.
In a system, the Krake™ is the peripheral.   Some other device is the SPI Controller.
The SPI interface is so old that when it was defined logic levels were 5 Volt.

**Describe alternatives you've considered**
_A clear and concise description of any alternative solutions or features you've considered._

For the Poly Vent the 3.3 Volt Controller (ESP32) SPI interface was level shifted up to 5Volts for the GPAD.
The same level shifting technique must be evaluated for the Krake™

**Additional context**
_Add any other context or screenshots about the feature request here._

ForrestErickson, 2024-10-22:
### Reference Data sheet for ESP32 S2:
https://www.espressif.com/sites/default/files/documentation/esp32-s2_datasheet_en.pdf
See section 3.4.2 Serial Peripheral Interface (SPI)

### To Do, Prototype SPI As Peripheral
Figure out which of the four SPI peripherals are available (not already in use) on the ESP32 Dev Kit we have.
Prototype an SPI Peripheral (formerly Slave) system and control it with an SPI Controller (Formerly Master) and make

ForrestErickson, 2024-10-22:
## To Do Review ESP32 S2 SPI Libraries
Here is one
https://github.com/hideakitai/ESP32SPISlave

## Random Nerd Tutorials ESP32 SPI Tutorial
https://randomnerdtutorials.com/esp32-spi-communication-arduino/

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

ForrestErickson, 2024-10-22:
Added Robert to this issue.

@RobertLRead
The GPAD firmware will need to be modified so that it can compile on both the UNO controller and the ESP32-S2.
I am assuming a lot of #ifdefine ESP32-S2 else #ifdef Atmega328 will be required.

ForrestErickson, 2024-10-22:
## SPI Pins on ESP32 DEV
Lee loaded and ran the Random Nerd Tutorials sketch to identify SPI pins on his ESP32-S2 Deve Kit 1
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

Bottom line
05:56:43.509 -> MOSI: 23
05:56:43.509 -> MISO: 19
05:56:43.509 -> SCK: 18
05:56:43.509 -> SS: 5

@nk25719
Please review the MockingKrake for the availability of these pins and any conflict with existing pin usage and report to @RobertLRead  and @ForrestErickson

ForrestErickson, 2024-11-20:
@nk25719
Wiring two Homework2 assemblies together would be a prudent thing to do in a way that reflects the SPI buss connections we have put into the KRAKE schematic.

Then one device is programed as a Controller and one as a Peripheral to verify the hardware connection works.

In addition there should be a Peripheral Interrupt Request, a GPIO output on the Peripheral which goes into an input on the Controller to signal the Peripheral needs attention.  The  Peripheral Interrupt Request needs to be added to the GPAD schematic.

nk25719, 2024-12-06:
changing the pin assignments of the SPI from
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

GPIO26 - COPI
GPIO25 - SPI_SCK
GPIO 33 - nCS
GPIO32  - CIPO

To pins
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

GPIO23 - COPI
GPIO19 -  CIPO
GPIO18 - SPI_SCK
GPIO5 - nCS

ForrestErickson, 2024-12-06:
changing the pin assignments of the LIGHT signals
LIGHT2, LIGHT3 and LIGHT4

From:
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

To:

nk25719, 2024-12-07:
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

Changing Pin assignment
S2 connection from GPIO 33 to GPIO 34
Mute switch from GPIO 34 to GPIO 35

nk25719, 2024-12-07:
Check issue #50 for latest updates for the SPI Interface.

Closed 2024-12-07.

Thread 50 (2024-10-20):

SPI Buss Controler at 5V and the ESP32 at 3.3V May Fail

ForrestErickson, 2024-10-20:
**Describe the Failure / Bug**
_A clear and concise description of what the failure / bug is. Describe the problem NOT the fix._

Short Summary of the expected behavior:  Connect an SPI Controller to and SPI Peripheral should not damage parts.

Short Summary of the buggy behavior:  5V controllers for example UNO may over voltage inputs on 3.3V Peripherals for example ESP32

Elementary explanation of voltage incompatibility and some level shifting solutions.

https://www.arrow.com/en/research-and-events/articles/using-a-level-shifter-to-integrate-different-voltage-signals

nk25719, 2024-11-19:
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

ForrestErickson, 2024-12-03:
@nk25719
Philips Semiconductor invented the I2C system.
A more detailed understanding of the MOSFET level shifter and the requirements of I2C is found in the Philips Semiconductor documentation.
When you have time, see: https://cdn-shop.adafruit.com/datasheets/an97055.pdf

ForrestErickson, 2024-12-03:
## Topics

- What is the depletion region of an PN Junction. See: https://en.wikipedia.org/wiki/Depletion_region
- What is a JFET and how does it work. (It works on the principles of a PN Junction). See: https://www.nutsvolts.com/magazine/article/fet_principles_and_circuits_part_1
- Then what are the additional features of the MOSFET over a JFET? See: https://www.tutorialspoint.com/difference-between-jfet-and-mosfet

The AI summary to the question, "how is a mosfet different from a JFET" is insightful too:

> 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

nk25719, 2024-12-07:
SPI interface with level shifters and ESD protection.

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

Closed 2024-12-07.

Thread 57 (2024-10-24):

Arduino MQTT.h library example Unstable on ESP32

ForrestErickson, 2024-10-24:
**Describe the bug**
_A clear and concise description of what the bug is._
Short Summary of the expected behavior:  I expect the example to work on an ESP32 kit, send MQTT but not interfere with other functions I program.

Short Summary of the buggy behavior: I found that the example flashes the LED_BUILTIN and I have evidence that the ESP operating system is messed up.

**To Reproduce**
Steps to reproduce the behavior:
1. Run the Processing sketch : FT_processingPMD_MQTT found at: https://github.com/nk25719/PMD___aka-KiCad-esp32-6leds-2switches-1pj-circuit-/tree/main/FactoryTest/FT_MQTT/FT_processingPMD_MQTT
2. With the approprate WiFi credeentials, upload into the Homework PWA or the Mocking Krake the sketch:  temp_ESP32DevelopmentBoard.ino  (Attached to this issue.)
3. Observe the console on the Processing environment and observe the serial monitor on the Arduino IDE
4. Observe that the LED_BUILTIN is flashing rapidly.
5. Apply expernal power supply. There should be no change.  The LED_BUILTIN is flashing rapidly.
6. Remove the USB connection.
7. The LED_BUILTIN stops flashing rapidly and does not WINK.  The processing sketch is no longer getting published messages.
8. The Processing sketch confirms that the messages are not publised
9.
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

## Problem Not In Lebanon
Not able to preproduce this with Homework Assemblies in Lebanon.

Powered by external power only
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

ForrestErickson, 2024-10-24:
I have found that one of my wall tranfromrer power supplies has huge ripple. The cyan colored trace here shows over 6 volts of ripple when powering a Homework2 assembly running a MQTT sketch.

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

Identical setup with a different power supply.
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

nk25719, 2025-02-10:
Is this solved? can we close? @ForrestErickson

ForrestErickson, 2025-02-11:
Closing as it appears to have been caused by a bad power supply.

Closed 2025-02-11.

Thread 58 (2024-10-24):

Choose USB to UART Chip,  CH340 or CP210x

ForrestErickson, 2024-10-24:
**Is your feature request related to a problem? Please describe.**
_A clear and concise description of what the problem is. Ex. I'm always frustrated when [...]_
I want a reliable USB enumeration of the Krake.
I am frustrated when some UNOs or other devices do not enumerate reliably and some times change COM (USB) port numbers

**Describe the solution you'd like**
_A clear and concise description of what you want to happen._
I want reliable repetable enumeration when connecting the USB device (Krake) to a host (A PC)

**Describe alternatives you've considered**
_A clear and concise description of any alternative solutions or features you've considered._

**Additional context**
_Add any other context or screenshots about the feature request here._

ForrestErickson, 2024-10-24:
The OSHWALAB schematic for their dev kit shows us how to connect to the CH340 USB to UART part.
https://oshwlab.com/Zulfahmi27/esp32-devkit-v1

ForrestErickson, 2024-10-24:
Here is a schematic which uses the CP210 USB to UART chip
https://embedded-systems-design.github.io/overview-of-the-esp32-devkit-doit-v1/SchematicsforESP32.pdf

ForrestErickson, 2024-11-17:
### Here is a candidate Silicon Labs part:
https://jlcpcb.com/partdetail/skyworks_siliconLabs-CP2102GMR/C6568
It is a  WQFN-28 package. Very small with leads that are poorly accessible should rework be necessary.
Qty  Unit Price
1+  $1.9570

### Here is a candidate CH340 part:
https://jlcpcb.com/partdetail/wch_jiangsu_Qin_heng-CH340T/C8689
Package: SSOP-20
Qty  Unit Price
1+  $0.6604

ForrestErickson, 2024-11-25:
There is an article here where the author covers 5V vrsus 3.3V opperation of the CH340 chip for correctl electrical inteface for an ESP32.

https://pcbartists.com/design/embedded/esp32-ch340-programmer-schematic/

Bottom line we should review the data sheet for insructions on how to use the CH340 with the 3.3 V UART of the ESP32.

nk25719, 2024-11-26:
Using CH340T chip:

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

nk25719, 2024-11-30:
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

cc: @ForrestErickson

Closing.

Closed 2024-11-30.

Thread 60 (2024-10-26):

Design Key Cap for Homework2 Switches

ForrestErickson, 2024-10-26:
**Is your feature request related to a problem? Please describe.**
_A clear and concise description of what the problem is. Ex. I'm always frustrated when [...]_
 I want a key cap on the Homework2 assemblies to work with the EnclosureRevC

**Describe the solution you'd like**
_A clear and concise description of what you want to happen._
The key cap should fit over the switch key with a blind pocket (blind hole) some what shorter than the key is tall so that the key can be pressed.
Near the bottom of the key cap the outer size of the key should be larger  than the opening in the top. It should then reduce down to a size smaller than the hole for the keys in the top.  This will keep the key cap from falling out of the enclosure.

**Describe alternatives you've considered**
_A clear and concise description of any alternative solutions or features you've considered._

 Note the variety of 6mm Tach switches with different size and styles of keys.

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

Unfortunately the JLCPCB part number provides a drawing which does not specify a particular key size.
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

When Lee measures the part he has on the Homework2 assemblies from JLCPCB the "H" dimension is 8.75mm

**Additional context**
_Add any other context or screenshots about the feature request here._

ForrestErickson, 2024-10-26:
Here is an OMRON part which probably matches our part with an "H" of 9mm.
B3F-1070, B3F-1072, B3F-1075, B3F-1072-G

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

From Digikey I find and select at 3D model.
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

ForrestErickson, 2024-10-26:
Note the Homework2 PWA does not have a 3D model for the switches.
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
and
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

If we could fix this path perhaps we would have the required file.

## Temporary , test, Solution
However the Omron downloaded STEP file above can be added to a single part in the PCB.
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

This is the result for adding to one switch.
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

## Proper Solution
Either fix the path to the built in 3D models AND CHECK THAT "H" IS CORRECT, or
add the Omeron file to the PCB footprint library part and safe with a new part number reflecting the Omron part number "B3F-1070"

nk25719, 2024-10-26:
this is a

On Sat, Oct 26, 2024 at 2:46 PM Forrest Lee Erickson <
***@***.***> wrote:

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

nk25719, 2024-10-26:
This is a PMD issue and not Krake's.

On Sat, Oct 26, 2024 at 2:54 PM nagham kheir ***@***.***>
wrote:

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

nk25719, 2024-10-26:
test email.

On Sat, Oct 26, 2024 at 2:55 PM nagham kheir ***@***.***>
wrote:

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
>>> Here is an OMRON part which probably matches our part with an "H" of 9mm.
>>> B3F-1070, B3F-1072, B3F-1075, B3F-1072-G
>>>
>>> image.png (view on web)
>>> <https://github.com/user-attachments/assets/0f83f336-973f-410e-a259-31e01e51b5be>
>>>
>>> From Digikey I find and select at 3D model.
>>> image.png (view on web)
>>> <https://github.com/user-attachments/assets/a65f88bb-dbaa-457a-b4e2-588ad630d102>
>>>
>>> —
>>> Reply to this email directly, view it on GitHub
>>> <https://github.com/PubInv/krake/issues/60#issuecomment-2439691018>, or
>>> unsubscribe
>>> <https://github.com/notifications/unsubscribe-auth/A73LHMINGV6HWSJT7AWKD3TZ5PPPBAVCNFSM6AAAAABQUZSB6GVHI2DSMVQWIX3LMV43OSLTON2WKQ3PNVWWK3TUHMZDIMZZGY4TCMBRHA>
>>> .
>>> You are receiving this because you were assigned.Message ID:
>>> ***@***.***>
>>>
>>

ForrestErickson, 2024-11-20:
Adding Oyin to this issue.

Here is an OpenSCAD file with a candidate design:
[Switch_key_caps_WIthGirdel.zip](https://github.com/user-attachments/files/17829099/Switch_key_caps_WIthGirdel.zip)

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

ForrestErickson, 2024-11-30:
Moved to the upstream of the Homework2 repository at:
https://github.com/nk25719/PMD___aka-KiCad-esp32-6leds-2switches-1pj-circuit-/issues/83

Closing.

Closed 2024-11-30.

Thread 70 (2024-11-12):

ESP32 Requires Reset and Boot Button Circuits from the Development Board

ForrestErickson, 2024-11-12:
**Is your feature request related to a problem? Please describe.**
_A clear and concise description of what the problem is. Ex. I'm always frustrated when [...]_
The ESP32 programing from the Arduino IDE requires the Reset and Boot circuit with the push buttons as per the ESP32 Development Kit board schematic.

nk25719, 2024-11-26:
Added Reset and Boot button circuit

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

nk25719, 2024-12-02:
Added a boot switch

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

cc: @ForrestErickson

Closing.

Closed 2024-12-02.

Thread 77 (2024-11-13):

Make a DF Player Footprint

nk25719, 2024-11-13:
**Is your feature request related to a problem? Please describe.**
_A clear and concise description of what the problem is. Ex. I'm always frustrated when [...]_
 the Df player needs a foorprint and maybe a 3d module as well.

**Describe the solution you'd like**
_A clear and concise description of what you want to happen._
 create a df player module
create a df player 3d module

nk25719, 2024-11-13:
### created a df player foot print
the pins start from the top left corner and go in a unti clockwise dorection

approx dimensions :
x-16.5  and y=19.2
and the sd card slot is represented by the silkscreen of measurement x-14.7 and y-14.5

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

nk25719, 2024-11-13:
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

ForrestErickson, 2024-11-14:
Review the schematic symbol (which I think is bad), the PCB footprint and the 3D model here:
https://www.snapeda.com/parts/DFR0299/DFRobot/view-part/

ForrestErickson, 2024-11-14:
Regarding, "sd card slot is represented by the silkscreen of measurement x-14.7 and y-14.5"
Make the box hollow. Just make an outline.

Additionally the outline for and SD card when inserted should be added so that we can visualize the card location relative to the enclosure.

An SD card STEP file should be added to the 3D model too.

nk25719, 2024-11-14:
link to dfplayer mini datasheet:
 chrome-extension://efaidnbmnnnibpcajpcglclefindmkaj/https://www.farnell.com/datasheets/3161923.pdf?_gl=1*xtvfhr*_gcl_au*MTQ0OTQzNzY5MS4xNzMxNjEwMjMy

nk25719, 2024-11-16:
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

nk25719, 2024-11-19:
Path to DFPlayer Footprint:
[PCBa_KRAKE/PCBa_KRAKE.pretty/DFPlayer_mini_20241116.kicad_mod](url)

Closing.

Closed 2024-11-19.

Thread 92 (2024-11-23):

Hardware, Optimizes EN (nRESET) Rise Time, ESP32

ForrestErickson, 2024-11-23:
**Is your feature request related to a problem? Please describe.**
_A clear and concise description of what the problem is. Ex. I'm always frustrated when [...]_
 Products with poorly designed nRESET often malfunction dueo to short power interuptions.

**Describe the solution you'd like**
_A clear and concise description of what you want to happen._
 A reset circuit which delays EN till the ESP32 is stable.
A reset circuit which follows Vcc down so that it is ready to make the required delay when power returns.

**Describe alternatives you've considered**
_A clear and concise description of any alternative solutions or features you've considered._
The GPAD has a schottky diode to discharge the reset capacitor.

**Additional context**
_Add any other context or screenshots about the feature request here._

This is the EN (nRESET) waveform from an ESP32 Dev1 Kit
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

ForrestErickson, 2024-11-23:
The GPAD reset circuit with capacitor to nRTS.
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

nk25719, 2024-12-09:
R102 and Diode D103 must be connected to 3v3 same as the ESP32

nk25719, 2024-12-14:
Capturing the nReset circuit.
A 330 ohm resistor was inspired by the HILetGo schematic.

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

Closed 2024-12-14.

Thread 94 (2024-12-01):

Software, Add serial commands to KRAKE through UART1

nk25719, 2024-12-01:
**Is your feature request related to a problem? Please describe.**
_A clear and concise description of what the problem is. Ex. I'm always frustrated when [...]_
KRAKE hardware is being designed for a serial command input on UART1, following request #2
Firmware GPAD_API version 0.19 has no support for UART 1

**Describe the solution you'd like**
_A clear and concise description of what you want to happen._
 Extend the software command input through UART1, just like MQTT

ForrestErickson, 2024-12-01:
Note that the UART1 flow control signals have also been implemented in the hardware.

RobertLRead, 2024-12-05:
@ForrestErickson The Random Nerd Tutorial on this subject suggest that different ESP32 versions (or board kit versions?) have different pin assignments for the UART1. They also say that one of the defaults, 9 and 10, can't be used because it is tied to SPI Flash memory (see section: ESP32 Default UART Pins in the link:
[https://randomnerdtutorials.com/esp32-uart-communication-serial-arduino/](https://randomnerdtutorials.com/esp32-uart-communication-serial-arduino/).)

I believe you have made pin assignments on your PCB -- what pins are you using? I need to know this to put them in the software and to test with them.

nk25719, 2024-12-05:
[image: image.png]

[image: image.png]

GPIO 9 RX
GPIO 10 YX

On Thu, Dec 5, 2024 at 2:53 PM Robert L. Read ***@***.***>
wrote:

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

ForrestErickson, 2024-12-05:
The full information from RNT is as follows:

> About UART1 (GPIO 9 and GPIO10) – these GPIOs are connected to the ESP32 SPI flash memory, so you can’t use them like that. To use UART1 to communicate with other devices, you must define different pins using the HardwareSerial library.

There is a complexity to the ESP32 where functions like UART TX and UART RX can be mapped to other than the default pins. While I have faced the concept with Pin Mapping on other processor types only in the briefest of ways I have never worked with the ESP32 version.   I guess we need to find tutoriasl on the HardwareSerial library and the pin maping.

Here is a screen shot of the ESP32 part of the Krake Schematic as of 2021041205
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

RobertLRead, 2024-12-05:
Okay --- Even you image does not quite answer the question for me.

But the software is "soft" --- I will code in constants which we can change
later.

But studying the image, I see pins marked:

   - GPIO1 : ControllerTX
   - GPIO3 : Controller RX
   - GPIO17: Controller TX2
   - GPIO16: Controller RX2

This does not match labelling the three build-int ESP32: UARTs 0 for the
serial port, UART1 for the next one and UART2 for the third one.  I suggest
we clarify this and improve the net names (is that the correct terminology.)

On Thu, Dec 5, 2024 at 3:04 PM Forrest Lee Erickson <
***@***.***> wrote:

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

--
Robert L. Read, PhD
Twitter: @RobertLeeRead @pubinvention
Public Invention: https://www.pubinv.org
Join Our Mailing list: ***@***.***
YouTube: https://www.youtube.com/channel/UCJQg_dkDY3KTP1ybugYwReg
Medium: ***@***.***

ForrestErickson, 2024-12-05:
FYI,
There is an example of using the ESP32 HardwareSerial library on the DFPlayer sketches Nagham and I worked with in this folder:
https://github.com/nk25719/PMD___aka-KiCad-esp32-6leds-2switches-1pj-circuit-/tree/main/FactoryTest/FT_DFplayer

How to assign the UART1 to another set of pins is yet to be discovered.

ForrestErickson, 2024-12-05:
Here is some insight on assigning pins:
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

It remains to figure out in the Arduino framework if we have a "uart_set_pin" function / library.

RobertLRead, 2024-12-06:
This has been fixed in version 0.20 of the firmware. I have tested it with an ESP32 AdaFruit HUZZAH Feather (which uses different pins!) as the transmitter. I have added a test file that works on that.  To use with an ESP32 WROOM, it will likely have to use a different PIN. I attach a jumper wire to D17 on that device (which is the TX1 pin), and to the "RX1" female header on the "HOMEWORK #2" device. It effectively does a "walking ones" test.

ForrestErickson, 2024-12-06:
@RobertLRead
Regarding, " I attach a jumper wire to D17 on that device"
Please identify the GPIO pin number for the UART1 TX and RX.  In the Krake schematic of 20241205 they are on GPIO10 and GPIO09 respectively but may be in conflict with other functions.

ForrestErickson, 2025-01-01:
As of 20250101, Krake PCB has the following pin asignments:

   - GPIO1 : ControllerTX
   - GPIO3 : Controller RX
   - GPIO17: Controller TX2
   - GPIO16: Controller RX2

ForrestErickson, 2025-01-01:
Firmware updated in version 0.23.
Note that there is a #if !defined (HMWK) which is removing the setup in the code which must go away once we have real KRAKE PCBs.

Closing.

Closed 2025-01-01.

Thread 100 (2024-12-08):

Software, Homework Hardware(PMD), GPAD_API, Ver 0.20, Incorrect LEDS only when DFPlayer Connected

ForrestErickson, 2024-12-08:
**Describe the bug**
_A clear and concise description of what the bug is._
Short Summary of the expected behavior:  With the "PMD_Processing_MQTT" sketch, when I send the the Lights do not flash properly and in the case of a5 not at all.

## Detailed Behavior

### With the DFPlayer connected on the Homework2 assembly, Send alarms from "PMD_Processing_MQTT".
alarm, a5 alarm all FIVE lights (LEDs should participate in the blinking. However they do not light at all. There is a noticeable flash of redraw to the LCD screen.
When sending a4, the first four Lights light but do not blink an the normal rate. They are on for about four seconds, off for about two seconds. There is a noticeable flash of redraw to the LCD screen about two seconds after the Lights come on.
When sending a3, the first three Lights light but do not blink an the normal rate. They are on for about four seconds, off for about two seconds. There is a noticeable flash of redraw to the LCD screen about two seconds after the Lights come on.
When sending a2, the first two Lights light but do not blink an the normal rate. They are on for about four seconds, off for about two seconds. There is a noticeable flash of redraw to the LCD screen about two seconds after the Lights come on.
When sending a1, the first Light lights but do not blink an the normal rate. It is on for about four seconds, off for about two seconds. There is a noticeable flash of redraw to the LCD screen about two seconds after the Light come on.
When sending a1, the first Light lights but do not blink an the normal rate. It is on for about four seconds, off for about two seconds. There is a noticeable flash of redraw to the LCD screen about two seconds after the Light come on.
When sending a0, the Lights are off. I can not tell if theres is a noticeable flash of redraw to the LCD screen because no back light.

#### Screen shot of the Serial Monitor on the DUT after a single a4 command was sent
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

#### Screen shot of the Serial Monitor on the DUT after a single a5 command was sent
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

### Observation from Screen Shots
From the screen shots it appears that the KRAKE thinks it is getting repeated alarm commands from the Processing PMD.

### With the DFPlayer NOT connected on the Homework2 assembly,
All alarms work normally.

This screen shot shows how the report from the DUT on the Serial Monitor changed when the DFPlayer was disconnected
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

**Hardware description**
Model:  Homework2 with LCD and DFPLayer of type TD5580A
Serial Number: UAS1
Other: Connect serial monitor on USB

ForrestErickson, 2024-12-08:
## Review of the Homework2 Schematic
See that the TX2 and RX2 are connected to the DFPlayer
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

UART1 is set for
#define TXD1 17
#define RXD1 16

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

This means that when the DFPlayer is connected traffic to the DFPlayer may be corrupting the behavior.

### Jumper from GPIO17TXD2 to GPIO16RXD2 did NOT replicate the fault behavior.
Therefor it is not something like like the signal looping back or echoed from the DFPlayer.

### Oscilloscope on TXD1 and RXD1 signals
The TXD1
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
The RXD1 is simply always low.

## Is UART 1 versus UART2 Confusion A Problem?

ForrestErickson, 2024-12-08:
## Checking UART 1 traffice.
Here is the UART 1 setup in GPAD_API
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

### Try loop back
Connect with wire TXD1 17  to RXD1 16.
The device behaves normally.

### DFPLayer Oscilliscope on TXD1 17  to RXD1 16.
Connect DFPlayer

The RXD1 16 line is low never changing

The TTXD1 17 has data in bursts as the LEDs come on.
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

ForrestErickson, 2024-12-08:
## More DFPlayer Testing Showing UART Traffice Both TX and RX

I sent a0 to the DUT
I now see data on the RX pin as well as the TX pin.
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

ForrestErickson, 2025-01-01:
The solution will be to reassign the UART 1 pins.
See issue #112
This has been done in GPAD_API Version 0.23 on 20250101

ForrestErickson, 2025-01-01:
Nagham,
Robert,
Please update the firmware in all KRAKE units.

Closing.

nk25719, 2025-01-01:
Not able to reproduce the error,
A different behavior on LEB1, all LEDs are blinking when sending emergency level 5 to Homework 2,
homeswork 2 board is connected to LCD, DFPlayer and Speaker,
running firmware V.0.21

DF Player connected to LEB1:
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

nk25719, 2025-07-05:
Different DFplayer were used to assemble units, prevented duplication of issue.

However Bug fixed, as per LEE "The solution will be to reassign the UART 1 pins.
See issue https://github.com/PubInv/krake/issues/112"

Fixed, Closing.

nk25719, 2025-07-05:
https://github.com/nk25719/PMD___aka-KiCad-esp32-6leds-2switches-1pj-circuit-

Closed 2025-07-05.

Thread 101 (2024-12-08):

Hardware, LCD for LEB1 no text

nk25719, 2024-12-08:
**Describe the Failure / Bug**
_A clear and concise description of what the failure / bug is. Describe the problem NOT the fix._
Short Summary of the expected behavior: see a display of the boot message after we hit reset.
Short Summary of the buggy behavior: Saw character cells only, we did not see the boot message.

**Device Under Test, aka DUT**
Steps to reproduce the behavior:
1. Model Number: Homework2 with LCD
2. Serial Number(s): LEB1
3. Location where failure / bug occurred: Lebanon
4. Hardware configuration. (How connected, any accessories, what else it takes to replicate the system in which the failure occurred.) with LCD
5. Extent of Failure
** Is failure intermittent? no
** Is failure fixed by power cycling? no
** Is failure permanent/fatal? unknown

**To Reproduce**
Steps to reproduce the behavior:
1. Loading the GPAD_APIV 0.21

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

2. Press Reset and watch the display.

nk25719, 2024-12-08:
Loaded the I2C scanner :
https://github.com/nk25719/PMD___aka-KiCad-esp32-6leds-2switches-1pj-circuit-/tree/main/FactoryTest/FT_LCD/I2CScannerLCDtest

The adress of the LCD reported: 0x3F

Note: in the GPAD_API was expecting 0x27.

Temporarly changed the address to 0x3F, compiled, loaded, LCD working.

Conclusion: was at incorrect I2C address. ROOT CAUSE.

nk25719, 2024-12-08:
Corrective action: Change the LCD address to 0x27.

nk25719, 2024-12-08:
LCD i2c adapter was at address 0x27 :
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

LCD i2c adapter was at address 0x3F:
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

nk25719, 2024-12-08:
For address 0x27, PCF8574:
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

For address 0x3F, PCF8574A:
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

URL to PCF8574 and PCF8574A datashet:
https://eu.mouser.com/datasheet/2/302/PCF8574_PCF8574A-3139141.pdf

nk25719, 2024-12-08:
The status of the Prototypes:

In lebanon we have I2c adapters with PCF8574A expander, I2c address is 0x3F
In USA we have I2c adapters with PCF8574 expander, I2c address is 0x27

There is no common configuration for a common address.
So there is no Hardware solution.
We must ask for a firmware feature to accomodate these two parts.

For Krake the issue will be addressed by ordering the I2c expander PCF8574A from JLCPCB / PCBWAY
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

cc: @RobertLRead

nk25719, 2025-02-13:
Incorrect Hardware in USA has incorrect IP address which caused an incorrect change in i2c address firmware file which broke the display in LEB.
Resolved by setting the Firmware with i2c code that supports both the LCD hardware in USA and in LEB.

The Firmware GPAD_API support Krake i2c circuit built in for the LCD.

Closing.

Closed 2025-02-13.

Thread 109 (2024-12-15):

ESP32 UART1 Has Pin Conflict when set on GPIO9 and GPIO10., Move to Open GPIO Pins

ForrestErickson, 2024-12-15:
**Is your feature request related to a problem? Please describe.**
_A clear and concise description of what the problem is. Ex. I'm always frustrated when [...]_

Here is a summary from an AI of the problem
AI Overview
[Learn more](https://support.google.com/websearch?p=ai_overviews&hl=en)
ESP32 UART Communication Pins Explained with Example
To set ESP32's UART1 to pins other than GPIO9 and GPIO10, you need to explicitly configure the UART1 pins in your code using the ESP-IDF framework, as GPIO9 and GPIO10 are typically connected to the flash memory and should not be used for standard UART communication; choose any other available GPIO pins to assign as UART1 TX and RX pins instead.
Key points to remember:
Default pins:
GPIO9 (TX) and GPIO10 (RX) are the default pins for UART1, but they are not recommended for most applications due to their connection to the flash memory.
Configuring in code:
To use different pins for UART1, you need to specify the desired GPIO pins in your code when initializing the UART peripheral.

**Describe the solution you'd like**
_A clear and concise description of what you want to happen._
Here is a summary from AI of code to change the pin numbers

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

 **HOWEVER** for Krake we must not use pin 3 as it is used elsewhere.
We probably want to use GPIO7 and GPIO8 as they unused and are near to the other pins we will be routing.

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

RobertLRead, 2024-12-16:
I've addressed this by adding a test file:

[https://github.com/PubInv/krake/blob/main/Firmware/TestUARTLoopBack/TestUARTLoopBack.ino](https://github.com/PubInv/krake/blob/main/Firmware/TestUARTLoopBack/TestUARTLoopBack.ino)

As currently compiled, it uses GPIO12 and GPIO13. I just connect them with a wire.

The screen shot shows that below it works:

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

The suggested pins are not available on the Dev Kit (but of course may be when design the board.)

I can't promise this will work with GPIO7 and GPIO8, but this seems to be strong evidence that it will if those pins are not used for some additional purpose.

@ForrestErickson @nk25719

Lee, I will allow you to close this, although I consider it done until you ask for something else.

ForrestErickson, 2024-12-16:
## Test the test
Lee loaded the TestUARTLoopBack.ino into an ESP32 DevKit1.
Ran the code and watched the serial output. With out a loop back wire the serial monitor only showed that the data was sent.
With a loop back wire the received message was displayed.

## Test with GPIO7 and GPIO8
Also the DEV Kit1 does not have pins 7 and 8.
Regardless, Lee changed the pins to 7 and 8 and compiled and uploaded the code.
The serial monitor shows the system is resetting
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

## Changed for pins 2 and 15 and retest
This works
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

## Conclusion,
Use GPIO 2 and GPIO15 for UART1, the RS232 port on Krake.

ForrestErickson, 2024-12-16:
## Additional insight on GPIO 7, 8 failure as UART
This URL: https://www.electronicshub.org/esp32-pinout/#:~:text=ESP%2DWROOM%2D32%20Pinout,-Let%20us%20start&text=It%20consists%20of%2038%2Dpin,is%20left%20for%20PCB%20Antenna.
explains how not only GPIO 9 and GPIO 10 are used on the internal flash but so to are GPIO 6, 7, 8 and 11.

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

## Bottom line
GPIO 2 and 5 are working for UART1.

ForrestErickson, 2024-12-16:
Lee modified the sketch TestUARTLoopBack.ino to test and demonstrate not only UART1 but also UART2 at the same time.
All three UARTs are demonstrated with success in this sketch.

Once the schematic is changed for UART1 pins compatible like this:
> #define TXD1 2
> #define RXD1 15
this issue can be closed

RobertLRead, 2024-12-16:
Well done, Lee!  Good job! Closing.

nk25719, 2024-12-18:
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

Schematic is changed for UART1 pins compatible like this:
 TXD1 2
 RXD1 15

--------------------------------
**Two issues as a result:**
1. internal battery relocation
2. Renaming the ESP32 pins : GPIO 9, 10, 2, 15.

cc: @ForrestErickson

ForrestErickson, 2024-12-19:
@nk25719
The RTS1 and CTS1 pins should also be moved off of the flash memory pins.
While I have not demonstrated that use of GPIO11 and GPIO6 would make a memory conflict the documentation implies it will.

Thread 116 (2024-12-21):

Check List Before PCB Design Release

nk25719, 2024-12-21:
**Is your feature request related to a problem? Please describe.**
_A clear and concise description of what the problem is. Ex. I'm always frustrated when [...]_
 Frustration of releasing the board without doing a common related checks.

**Describe the solution you'd like**
_A clear and concise description of what you want to happen._
 Check for the following

- [x]  Printed circuit board name in Silkscreen
- [x] Move C109 closer to C108.
- [x] Make outline for mounting nuts and a nut driver on the LCD for keep out. #119
- [x] Place the Rotary Encoder. Modify the enclosure.
- [x] Place the RS232 connector. Modify the enclosure.

**Additional context**
_Add any other context or screenshots about the feature request here._
Go to BWE in @ForrestErickson github and look for review for project milestones: https://github.com/ForrestErickson/bwe

nk25719, 2025-01-15:
## Summary

Printed circuit board name in Silkscreen

> 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

 Move C109 closer to C108.
 Make outline for mounting nuts and a nut driver on the LCD for keep out. https://github.com/PubInv/krake/issues/119
 Place the RS232 connector.

> 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

 Place the Rotary Encoder.

> 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

Closed 2025-01-15.

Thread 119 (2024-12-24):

LCD Mounting Nut Inadequate Clearance For Nut Driver

ForrestErickson, 2024-12-24:
**Describe the Failure / Bug**
_A clear and concise description of what the failure / bug is. Describe the problem NOT the fix._

Short Summary of the expected behavior: I expect to be able to drive the LCD mounting screw nuts tight with a nut driver.
Short Summary of the buggy behavior:  There is interference on one or more nuts.

From the GPAD,
The mounting nut near the three terminal regulator.
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

The nut driver in interference with the three terminal regulator
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

**Additional context**
_Add any other context about the problem here._

 The outer diameter of a 1/4" Craftsman nut driver is 10mm. Need some clearance over that.

nk25719, 2024-12-28:
This is a new footprint of the LCD, a new keep out at the four corners is added.

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

Closed 2024-12-28.

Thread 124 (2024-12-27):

If We Want A Big Speaker, We Need A Bigger Enclosure

ForrestErickson, 2024-12-27:
**Is your feature request related to a problem? Please describe.**
_A clear and concise description of what the problem is. Ex. I'm always frustrated when [...]_
 There is no room for a forward facing speaker with the GPAD PCB outline and the GPAD Enclosure

**Describe the solution you'd like**
_A clear and concise description of what you want to happen._

**Describe alternatives you've considered**
_A clear and concise description of any alternative solutions or features you've considered._

Consider making a larger PCB and larger enclosure
The red outline here shows a speaker and under it the rotary encoder and some new mounting holes.
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

**Additional context**
_Add any other context or screenshots about the feature request here._

nk25719, 2025-01-12:
This issue should be reviewed by the entire team.

ForrestErickson, 2025-04-26:
## SPL Sound Pressure Level
Here is a sound pressure measurement of Krake playing all the audio files at volume = 20 into a 28mm speaker hot melt glued into a Krake Enclosure and into a 6" JBL Speaker in a heavy wooden cabinet.

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

## Interpreting SPL
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

## Measurement Details
Measurements made with Samsung Galaxy 25S
Using "Sound Meter KUCO Apps"
KRAKE SN US0001
Audio Files:

### Setup
Krake and Speaker on floor. Carpet over concrete
Smart Phone on floor 1Meter away

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

ForrestErickson, 2025-06-30:
About 20250618 in Austin TX Lee demonstrated to Nagham and Robert the advantage of a louder higher effincy speaker event with out an enclosure using this part

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

high efficiency speaker Parts-Express link:
https://www.parts-express.com/Z152948311-3-Sony-Shielded-AV-Speaker-8-Ohm-299-548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

ForrestErickson, 2025-07-09:
On 20250709
Lee requested additional information from Parts-Express.
https://www.parts-express.com/contact-us

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

ForrestErickson, 2025-07-10:
20250710 Found 1.5mm connector system on cables at Amazon

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

Here is the JST data page:
https://www.jst.com/products/crimp-style-connectors-wire-to-board-type/zh-connector/

Here is the JLCPCB part number for a two pin PCB vertical header (Male pins with locking shell).
https://jlcpcb.com/partdetail/JST-B2B_ZR_3_4_LF_SN/C163033

nk25719, 2025-08-13:
This enclosure with a new speaker tbd should undergo a dropping test to test test its mechanical design robust.

ForrestErickson, 2025-09-27:
Lee has made a FreeCAD model for a 3" speaker.

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

The speaker can be purchased at: https://www.parts-express.com/GRS-3FR-4-Full-Range-3-Speaker-4-Ohm-292-436
The model is in Lee's Github at: https://github.com/ForrestErickson/A3inchSpeaker_GRS_3FR

There is an STL model there which can be imported into OpenSCAD.

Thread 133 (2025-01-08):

Hardware, DRC Error Routing CH340T

nk25719, 2025-01-08:
**Describe the Failure / Bug**
_A clear and concise description of what the failure / bug is. Describe the problem NOT the fix._
Short Summary of the expected behavior: Routing the CH340T with the USB C with DRC of zero errors
Short Summary of the buggy behavior: After upsizing the vias, the signal routing between the USB C and the CH340 became clutterred with vias that are over hanging on the footprints of the USB C and the CH340T

**Screenshots**
_If applicable, add screenshots to help explain your problem._

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

**Hardware description**
Model: KRAKE
RevA

**Additional context**
_Add any other context about the problem here._

# **General PCB Design Guidelines**

### Trace Width and Spacing:

Use traces of at least 10 mils width for power and ground.
Signal traces can be 6-8 mils for shorter runs; adjust based on current capacity.
Maintain a minimum spacing of 6 mils between traces (standard for most PCB manufacturers).

### Layer Stackup:

Place the USB signals (D+ and D-) on the same layer, preferably a signal layer, with a ground plane directly beneath for shielding.
Use a separate power plane for VCC to reduce noise.

nk25719, 2025-01-08:
Attempt 1 to solve the issue:
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

nk25719, 2025-01-08:
Attempt 2:
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

issue solved.

Closed 2025-01-11.

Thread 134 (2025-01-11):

Hardware,  Footprint, ESP32 pin 39 Thermal relief connection to zone incomplete

nk25719, 2025-01-11:
**Describe the bug**
_A clear and concise description of what the bug is._
Short Summary of the expected behavior:  ESP32 footprint should not have thermal relief errors.
Short Summary of the buggy behavior:  ESP32 have thermal relief connection errors.

**To Reproduce**
Steps to reproduce the behavior: Run the DRC in the PCB editor of Kicad.
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

**Screenshots**
_If applicable, add screenshots to help explain your problem._

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

**Hardware description**
Model: Krake

**Additional context**
_Add any other context about the problem here._
```

** Found 4 DRC violations **
[starved_thermal]: Thermal relief connection to zone incomplete (board setup constraints zone fill strategy min spoke count 2; actual 1)
    Rule: board setup constraints zone fill strategy; Severity: error
    @(193.0400 mm, 101.6000 mm): Zone [GND] on F.Cu and 1 more
    @(107.6580 mm, 33.6390 mm): PTH pad 39 [GND] of U102
[starved_thermal]: Thermal relief connection to zone incomplete (board setup constraints zone fill strategy min spoke count 2; actual 1)
    Rule: board setup constraints zone fill strategy; Severity: error
    @(193.0400 mm, 101.6000 mm): Zone [GND] on F.Cu and 1 more
    @(108.3580 mm, 32.2390 mm): Pad 39 [GND] of U102 on F.Cu
[starved_thermal]: Thermal relief connection to zone incomplete (board setup constraints zone fill strategy min spoke count 2; actual 1)
    Rule: board setup constraints zone fill strategy; Severity: error
    @(193.0400 mm, 101.6000 mm): Zone [GND] on F.Cu and 1 more
    @(108.3580 mm, 33.6390 mm): Pad 39 [GND] of U102 on F.Cu
[starved_thermal]: Thermal relief connection to zone incomplete (board setup constraints zone fill strategy min spoke count 2; actual 1)
    Rule: board setup constraints zone fill strategy; Severity: error
    @(193.0400 mm, 101.6000 mm): Zone [GND] on F.Cu and 1 more
    @(108.3580 mm, 35.0390 mm): Pad 39 [GND] of U102 on F.Cu

```

nk25719, 2025-01-11:
Changed the Copper fill properties for the fill connections from Thermal relief to Reliefs for PTH, and this cleared the Errors.

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

nk25719, 2025-01-11:
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

Closing issue.

Closed 2025-01-11.

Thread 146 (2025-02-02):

Doc - JLCPCB Order History - KRAKE REV1 PW ASSY, Nagham

nk25719, 2025-02-02:
Placing order at JLCPCB:

Added the Gerber files:

- Gerbers_250128_1359.zip

Added BOM and CPL files:

- PCBa_KRAKEKiCad6_250128_1359_BOM_JLC.csv
- PCBa_KRAKEKiCad6_250128_1359_CPL_JLC.csv

Received this Error message after pushing the BOM and CPL files:

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

> The components mentioned are DNI components, DO NOT INSERT.

Selected continue to proceed to the next page,

nk25719, 2025-02-02:
## shortfall components are changed:

from:
C168673
to:
C492401
Description:
Direct Insert Policy 2.5mm 2P 6mm -40℃~+105℃ 3mm 2.54mm Single Row Black Brass 1x2P Plugin,P=2.54mm Pin Headers ROHS

---

from:
C7496728
to:
C703015
description:
3A Direct Insert Policy 1.7mm 2P 3mm -55℃~+105℃ 2.5mm 1.27mm Single Row Black Brass 1x2P Plugin,P=1.27mm Pin Headers ROHS

-------

from:
C269711
to:
RS-03K331JT
Description:100mW Thick Film Resistors 50V ±100ppm/℃ ±5% 330Ω 0603 Chip Resistor - Surface Mount ROHS

------

from:
C269713
to:
C23162
Description: 100mW Thick Film Resistors 75V ±100ppm/℃ ±1% 4.7kΩ 0603 Chip Resistor - Surface Mount ROHS

nk25719, 2025-02-02:
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

on: 20250202_0834 EST

nk25719, 2025-02-03:
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

> This pop-up appears when exiting the component placement page, we selsected the option where JLCPCB wait for our reply before proceeding with the order.

nk25719, 2025-02-03:
We have loaded Gerbers, BOM and CPL files but we are unable to save the shopping cart and we get an error message.
We have documented our efforts in the following issue:  https://github.com/PubInv/krake/issues/146

We have uploaded to this form the Gerber, the BOM and CPL files.

Please try to duplicate our problem with these files.

Please reply to the following email adresses:
forresterickson@comcast.net
naghamkheir25@gmail.com

02 February, 2025.

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

nk25719, 2025-04-04:
We discovered that JLCPCB does not ship to Lebanon, Lee @ForrestErickson proceeded with the order to the US, see issue #148

Closed 2025-04-04.

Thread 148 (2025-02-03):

Doc - JLCPCB Order History - KRAKE REV1 PW ASSY, Lee

ForrestErickson, 2025-02-03:
20250203 1410

Placing order at JLCPCB:

Added the Gerber files:

Gerbers_250128_1359.zip
Added BOM and CPL files:

PCBa_KRAKEKiCad6_250128_1359_BOM_JLC.csv
PCBa_KRAKEKiCad6_250128_1359_CPL_JLC.csv

Choose parameters including Confirm Production File
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

## Set assembly options.
Choose Confirm Parts Placement and get dialog and choose NOT to confirm automatically
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

Choose Depanel boards & edge rail before delivery

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

Pressed next.

## Board Render
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
Pressed next.

## Upload BOM/PL and CTL Files
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
Press: Process BOM and CPL

Get the Error dialog for parts not populated.
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
Pressed Continue.

For J???replace with C492401
For J601 replace with C703015
For all 330R replace with  RS-03K331JT
For all 4K7 replace with C23162

This cleared all shortfalls.
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
So press next

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
The render finalized.

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
Pressed next.

Choose to NOT conform automatically.
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

 Choose Save to card.
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

It saved.

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

ForrestErickson, 2025-02-05:
## Order Emails from JLCPCB
2/4/2025 5:37 PM
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

Second email
2/4/2025 7:46 PM
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

## Visit link and approve
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

Lee approved the production but sent two emails for non critical clarification.
### First Email  re JLCJLCJLCJCL
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
### Second Email re 2D code
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

ForrestErickson, 2025-02-07:
Another request to confirm proeuction

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

The dialog to enter parts placement review
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

The dialog for parts placement
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

I gave instructions for rotation of three diodes.
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

ForrestErickson, 2025-02-08:
Email on

```
On 02/08/2025 9:59 AM EST JLCPCB <noreply@jlcpcb.com> wrote:
Dear ForrestErickson,

The parts placement of your order  SMT025020361767 is completed. The order is ready for manufacturing now. Please check and confirm it through your [order history](https://mandrillapp.com/track/click/31015052/jlcpcb.com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).

```

## My review response
Hello and thank you for rotating the parts.
However now I am feeling confused and realized I should have asked how the plus and minus symbols on the 3D view are showing anode and cathode.  I may have been wrong.

To clearly state my requirement
D101 Cathode up.
D103 Cathode right.
D104 Cathode up.

Sorry to have to revisit this but I confused my self.

ForrestErickson, 2025-02-12:
On 20250212 Lee sent email to JLCPCB

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

ForrestErickson, 2025-02-12:
On 20250212 Lee Placed an Amazon order resulting in two Invoices

[Amazon.com - Order 112-3993719-9023403.pdf](https://github.com/user-attachments/files/18771701/Amazon.com.-.Order.112-3993719-9023403.pdf)

[Amazon.com - Order 112-9690873-4379401.pdf](https://github.com/user-attachments/files/18771703/Amazon.com.-.Order.112-9690873-4379401.pdf)

ForrestErickson, 2025-02-13:
Email from JLCPCB

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

Lee visited the link and found the confirm button and pressed it.
Sent email back

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

ForrestErickson, 2025-02-14:
An email from JLCPCB

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

CC: @nk25719

ForrestErickson, 2025-04-04:
<html>
<body>
<!--StartFragment--><div>On 02/17/2025 10:04 PM EST JLCPCB &lt;noreply@jlcpcb.com&gt; wrote:</div>

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
<p>Dear ForrestErickson,</p>

<p>Thank you for your order from JLCPCB. It’s our pleasure serving you. We are pleased to inform you that the items listed below have been packaged and are waiting for pick up by DHL EXPRESS. Tracking Number: 1923805682</p>

<p>Kindly note that it may take 1-2 days before carriers will display tracking information.</p>

<p>Please track the shipment in your <a href="https://mandrillapp.com/track/click/31015052/jlcpcb.com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" target="_blank" rel="noopener">order history</a>.</p>

<p><span style="color: #606266;">Items in this shipment：【W202502050208228】</span></p>

  | Gerbers_250128_1359_Y20 5 pcs
-- | --
  | 5 pcs
  | View order details>>

<!--EndFragment-->
</body>
</html>
Order received in March. On 02/17/2025 10:04 PM EST JLCPCB <noreply@jlcpcb.com> wrote:
Dear ForrestErickson,
Thank you for your order from JLCPCB. It’s our pleasure serving you. We are pleased to inform you that the items listed below have been packaged and are waiting for pick up by DHL EXPRESS. Tracking Number: 1923805682
Kindly note that it may take 1-2 days before carriers will display tracking information.
Please track the shipment in your [order history](https://mandrillapp.com/track/click/31015052/jlcpcb.com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).
Items in this shipment：【W202502050208228】
Gerbers_250128_1359_Y20
5 pcs
5 pcs

	[View order details>>](https://mandrillapp.com/track/click/31015052/jlcpcb.com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)

nk25719, 2025-04-27:
Check issue #168 to see the unpacking for the received order.

Closing. @ForrestErickson

Closed 2025-04-27.

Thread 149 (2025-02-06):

Hardware, Schematic and BOM (PCBa_KRAKEKiCad6_250128_1359_BOM) Errors

ForrestErickson, 2025-02-06:
Error in file: PCBa_KRAKEKiCad6_250128_1359_BOM

D106 is a 0603 LED but has incorrect manufacturer part number calling out an 0805.
The JLCPCB part number correct for an 0603.

Manufacturing Part number with error
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

The rest of the fields should be double checked too.

nk25719, 2025-02-06:
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

Incorrect MPN, the correct MPN is: RMC060310KFN

We approved with PCBWAY to use: FRC0603F1002TS for manufacturing PCBa Rev1

nk25719, 2025-02-07:
This Datasheet info for the Enclosure is obviously wrong,

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

nk25719, 2025-02-13:
After fixing the above mentioned errors we need to regenate the BOM and gerbers for the future orders.

nk25719, 2025-02-27:
[CustomerReply_20250227_T-1C10W732620A.xlsx](https://github.com/user-attachments/files/19015147/CustomerReply_20250227_T-1C10W732620A.xlsx)

Additional BOM errors corrected for PCBWAY,
TP101
and J601

(We need to update the BOM sheet before sending out another order.)

nk25719, 2025-04-27:
Additional corrections and data routing for the MPN and manufacturer for the DB9 used:

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

Closed 2025-04-27.

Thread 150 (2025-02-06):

Hardware, Power Barrel Jack Mounting Hole Wrong For Vendor Cliff

ForrestErickson, 2025-02-06:
**Describe the Failure / Bug**
_A clear and concise description of what the failure / bug is. Describe the problem NOT the fix._
Short Summary of the expected behavior:  The Krake (and GPAD) schematic references two part numbers and both should fit into the PCB.

Short Summary of the buggy behavior:  The Cliff part has a 2x1.5mm pin which will not fit into the 1.6mm hole.

Need to check all of these vendors and make the footprint compatible.

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

Need to update all assemblies using this footprint.

Also in the schematic symbol there are two Manufacturiers and MPN in the same lines which caused confusion with PCBWay.

nk25719, 2025-08-04:
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

2025 - 08 - 04
Examined the PCB footprint, we found the holes for the pins to be acceptable, we assume that this was previously fixed, closing .

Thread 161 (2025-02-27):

Hardware, Test Points, TP101, PCBWAY notes: "Component is bigger then drill, unable to plug in."

nk25719, 2025-02-27:
**Describe the Failure / Bug**
_A clear and concise description of what the failure / bug is. Describe the problem NOT the fix._

 PCBWAY sent us the following information: "Component is bigger then drill, unable to plug in."
This is the component called out in the bill of material for TP101 : RH-5121	TestPoint:TestPoint_Loop_D2.54mm_Drill1.5mm_Beaded

They included this following photograph:
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
TP101 is in the photograph
**Hardware description**:
Model: KRAKE Rev1
Serial Number: NA

nk25719, 2025-02-27:
Another instance, Boards at USA, Built by JLCPCB:

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

The two parts side by side
Control assembly 1.2 showing the RH-5121 (green) and the RH-5000 (red).
Therefore both sizes are used on the Control assembly 1.2 and was built by JLCPCB.

nk25719, 2025-02-27:
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

Datasheets of the two parts side by side,
on the left the datasheet for the part called out and PCBWAY identified as a problem.
and to the right the smaller part used successfully on HOMEWORK2 assembly by PCBWAY.

nk25719, 2025-02-27:
[CustomerReply_20250227_T-1C10W732620A.xlsx](https://github.com/user-attachments/files/19015105/CustomerReply_20250227_T-1C10W732620A.xlsx)

Resolved the issue by replying to the sheet sent from PCBWAY.

nk25719, 2025-04-27:
The issue was reported only by one of the companies we manufactured the boards with, JLCPCB. The new part numbers for the components in question have been captured in the Excel sheet mentioned in the previous comment.

Closing this issue as complete.

ForrestErickson, 2025-07-14:
## We Need To Check
Are we calling out the correct test point part number for ALL test points.  The smaller size type of test points.
Is the hole in the PCB appropriate for the smaller size test points.

nk25719, 2025-07-22:
This part should work: LCSC Part # C5243682,  XKB Connection X1311WV-02J-C40D24 , https://www.lcsc.com/product-detail/Pin-Headers_XKB-Connection-X1311WV-02J-C40D24_C5243682.html

nk25719, 2025-07-31:
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

ForrestErickson, 2025-08-02:
## JLCPCB Stock Status 202250802
We should be designing with parts commonly stocked.

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

ForrestErickson, 2025-08-02:
From the datasheet at: https://www.keyelco.com/userAssets/file/M65p56.pdf
For the Keystone test points with 1.25mm loop, the hole diameter should be 1mm.
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

Therefor the KiCad foot print should be the one named: **TestPoint_Loop_D1.80mm_Drill1.0mm_Beaded**

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

Closed 2025-08-02.

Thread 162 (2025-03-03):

Hardware, PMD, DF Player is not initializing

nk25719, 2025-03-03:
**Describe the Failure / Bug**
The DF Player should initialize and display the menu, however the serial communication is not initializing therefor the module is noy responding if the SD card is found.

**Device Under Test, aka DUT**
Steps to reproduce the behavior:
1. Model Number: 20240421
2. Serial Number(s): LEB1
3. Location where failure / bug occurred: lebanon
4. Hardware configuration: connect the dfplayer to the board and the speaker to the df player and insert the sd card in the df player.
5. Extent of Failure
** Is failure intermittent? no
** Is failure fixed by power cycling? no
** Is failure permanent? yes

**To Reproduce**
Steps to reproduce the behavior:
1. Go to PMD_BOOTUP
2. Click on UPLOAD, THEN Serial Monitor

**Screenshots**
_If applicable, add screenshots to help explain your problem._

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

## Hypothesis

This is due to the insufficient voltage provided with 3.3V instead of 5V.

nk25719, 2025-03-04:
Compiled and uploaded another code with a HardwareSerial library and the DF Player responded.

ForrestErickson, 2025-04-25:
Long since fixed.
Closing.

Closed 2025-04-25.

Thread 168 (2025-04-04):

Doc - KRAKE REV1 PW ASSY Finishing and Testing in USA, Lee

ForrestErickson, 2025-04-04:
# Summary
Finishing assembly of Krake in USA using the assemblies from JLCPCB. Ref #148

## Unpacking

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

With other parts

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

## Assembly Finish

# Manufacturing and Unit Test Documentation, PCB Version 2.0, 20250406
These notes were made during the assembly of the JLCPCB order of about March 2025.
These units will be assigned serial numbers US0001 through US0005 and LB0001 through LB0005.

#### Sections below
* Manufacturing test procedure for every unit
**Assembly Notes and Tips

## Manufacturing test procedure for every unit

### Tools Required

Solder station with appropriate ventilation
3/16 Nut Driver
Number 1 Philips screw driver
Diagonal or other flush cutting hand tool for lead trimming.
Assembly fixture, detailed below.

### Reference Material

PUT SCHEMATICS REF HERE

### Assembly Notes and Tips

As received from JLCPCB.
Note the assembly has the SMT components placed by the board manufacturer and some but not all through hole components.

Write serial number on the PCB assembly at the location provided.
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
Example of serial number written on number 26.
_Further Management of serial numbers is beyond the scope of this document. Each manufacturer must figure something out._

### An Assembly Fixture
We made an assembly assistant / fixture by using a raw PCB with some long #6 screws and nuts to hold at the PCB mounting points.
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

In addition four 4.40 screws with washers and 4-40 nuts to make a 1/8" spacer for holding the LCD and header for soldering.
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

### Assembly Steps

**Bypass U501 USB-UART Chip**
U501 was implemented incorrectly with out a 12MHz cyrstal and so does not function as is.
Wire in a "bypass" USB-UART break out board.
Unsolder R502 and rotate it 90 degrees on the "south" most pad.
Solder 330 Ohm or similar resistor into J601 pins 10 and 11 for ESP32 RXD0 and TXD0 respectively.
Solder the two resistors to each end of a three pin header.
Solder a ground wire to the center pin of the header.

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
Trim the leads  on the LCD side of the PCB so they do not interfere with / contact the LCD.

**DFPlayer in Sockets**
**Important:** we need to solder the DF player header  before soldering the LCD, Assemble with headers

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

Trim the DFPlayer header leads  on the LCD side of the PCB so they do not interfere with / contact the LCD.

**Prep LCD ESD Ground Connections**
Connect J1 and J2 on the back of the LCD by a ball of solder.
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

Put spacers and bolts and mount LCD then, Solder the pins of the LCD.
Next, put the nuts and torque the nuts to about 2inch Lbs.
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

**Solder the LEDS**
Note that the LEDs have a flat edge molded on the plastics part for the cathode. The silk screen shows the flat spot for easy alignment during assembly.

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

Trim the leads, CAUTION: be very careful not to damage the near by transistors.
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

So that you do not mix colors, close the packaging on the white LEDs.
Open the packaging for red LEDs and with a spacer solder it and trim leads.
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

Connect DB9
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

Finish soldering DB9
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

DONE ASSEMBLY

ForrestErickson, 2025-04-07:
## Electrical Test

### Unpowered Test
Tests to make sure no danger to test  equipment power supply
Test with multi meter. In USA make ASTRO /\I DM6000AR

| **Test/DUT**   | **Resistance  TP2-TP1 (Vin)** | **Resistance  TP3-TP1 (+5V)** | **Resistance  TP201-TP1 (VBus)** | **Resistance  J103 Pin 2-TP1 (ControllerVcc)** |
|----------------|-------------------------------|-------------------------------|----------------------------------|------------------------------------------------|
| **Pass Fail**  | Not short,  Capacitive        | Not short,  Capacitive        | Not short,  Capacitive           | Not short,  Capacitive                         |
| **SN: US0001** | >10Meg                        | 1.1K Typical                  | 304 Ohm                          | >10Meg                                         |
|                |                               |                               |                                  |                                                |
|                |                               |                               |                                  |                                                |
|                |                               |                               |                                  |                                                |
|                |                               |                               |                                  |                                                |
|                |                               |                               |                                  |                                                |
|                |                               |                               |                                  |                                                |
|                |                               |                               |                                  |                                                |

### Powered Tests
Apply power with current limited voltage supply.
Minimum input voltage 8V, Maximum 12V.
Current limit TBD Amps.
Apply power at J101.
Measure current and stop test if dangerously high (> 200 mA???)

| **Test/DUT** | Current J101 | TP102 Vin | TP103 +5V | +5esp32 into U103 | +3.3V Tab U103 | TP202 V3 on U501 | D103 Cathode 3v3Controller | C505+ 5VDFP |
|----------------|--------------|-----------|-----------|-------------------|----------------|------------------|----------------------------|-------------|
| **Pass Fail**  | < TMD mA     |           |           |                   |                |                  |                            |             |
| **SN: US0001** | 147mA        | 8.33      | 5.046     | 4.929             | 3.318          | 3.314            | 3.208                      | 5.031       |
|                |              |           |           |                   |                |                  |                            |             |
|                |              |           |           |                   |                |                  |                            |             |
|                |              |           |           |                   |                |                  |                            |             |
|                |              |           |           |                   |                |                  |                            |             |
|                |              |           |           |                   |                |                  |                            |             |
|                |              |           |           |                   |                |                  |                            |             |
|                |              |           |           |                   |                |                  |                            |             |

ForrestErickson, 2025-04-11:
# Functional Test

## With Factory Test Firmware
Load firmware file: TBD
Test TBD

## With Final Test Firmware
Load firmware: GPAD_API
Capture information by serial number
Firmware version, MAC,

| **Serial#** | **MAC** | **Firmware Version** |   | **Note** |
|:-----------:|:-------:|:--------------------:|:-:|:--------:|
|             |         |                      |   |          |
|             |         |                      |   |          |
|             |         |                      |   |          |
|             |         |                      |   |          |
|             |         |                      |   |          |
|             |         |                      |   |          |
|             |         |                      |   |          |
|             |         |                      |   |          |
|             |         |                      |   |          |
|             |         |                      |   |          |
|             |         |                      |   |          |
|             |         |                      |   |          |
|             |         |                      |   |          |
|             |         |                      |   |          |

ForrestErickson, 2025-04-27:
Load Micro SD card with files from:  https://drive.google.com/drive/u/1/folders/1uwaVFpFQ0uJbVLxVXngsslgTf2tzOCR6
See Issue: DOC, Procedure for Loading MP3 Files in SD Card #188

Connect the DUT to a test speaker.

Load firmware: DFPlayerTD5580ATest into DUT
This firmware can be loaded by USB-serial  interface or by OTA and is OTA ready.

Reset the DUT and confirm audio files play.
Measure peak audio level with ??? SPL meter.

Confirm peak audio level of ??? +/- ?? db .

|   **Serial#**  | **Peak SPL** |   |   | **Note** |
|:--------------:|:------------:|:-:|:-:|:--------:|
| **SN: US0001** |              |   |   |          |
| **SN: US0002** |              |   |   |          |
| **SN: US0003** |              |   |   |          |
| **SN: US0004** |              |   |   |          |
| **SN: US0005** |              |   |   |          |
| **SN: LB0001** |              |   |   |          |
| **SN: LB0002** |              |   |   |          |
| **SN: LB0003** |              |   |   |          |
| **SN: LB0004** |              |   |   |          |
| **SN: LB0005** |              |   |   |          |
|                |              |   |   |          |
|                |              |   |   |          |
|                |              |   |   |          |
|                |              |   |   |          |

nk25719, 2025-10-01:
Closing as complete.

Closed 2025-10-01.

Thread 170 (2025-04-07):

Hardware, Krake Rev2 PCB, Add Test Points

ForrestErickson, 2025-04-07:
**Is your feature request related to a problem? Please describe.**
_A clear and concise description of what the problem is. Ex.

I'm always frustrated when I cannot get a multi meter or alligator clip on a power supply.

- [x]   +3.3 at the output of U103 pin 2.
- [x]  Additional test points on ground around the board.
- [x] Add Test Points to UART0 TX/RX
- [x]  SPI Interface.
- [x]  Decoupling 5v
- [x]  Decoupling 3V3
- [x] VCC USB

**Describe the solution you'd like**
_A clear and concise description of what you want to happen._

Red test point  same part number as found at TP201 for 3.3V.

Green test points same part number as TP101. Put somewhere in each quadrant.

nk25719, 2025-08-03:
PWA_REV2.kicad, Added test points, GND, SPI, and UART0. Filed a keystone datasheet.
 PWA_REV2.kicad, Added test points for the decoupling 5v resistors.
 PWA_REV2.kicad, Added test points for the decoupling 3v3 resistors and for the VCC USB.

Closing.

Closed 2025-08-03.

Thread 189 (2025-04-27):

Doc - KRAKE REV1 PW ASSY Finishing and Testing in LB, Nagham

nk25719, 2025-04-27:
**Is your feature request related to a problem? Please describe.**
_A clear and concise description of what the problem is. Ex. I'm always frustrated when [...]_

- Add unpacking
- assembling
- electrical testing

ref issue #168 for a template

**Describe the solution you'd like**
_A clear and concise description of what you want to happen._

**Describe alternatives you've considered**
_A clear and concise description of any alternative solutions or features you've considered._

**Additional context**
_Add any other context or screenshots about the feature request here._

nk25719, 2025-04-28:
# Summary
Finishing assembly of Krake in USA using the assemblies from JLCPCB. Ref #148

## Unpacking

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

With other parts

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

## Assembly Finish

# Manufacturing and Unit Test Documentation, PCB Version 2.0, 20250406
These notes were made during the assembly of the JLCPCB order of about March 2025.
These units will be assigned serial numbers US0001 through US0005 and LB0001 through LB0005.

#### Sections below
* Manufacturing test procedure for every unit
**Assembly Notes and Tips

## Manufacturing test procedure for every unit

### Tools Required

Solder station with appropriate ventilation
3/16 Nut Driver
Number 1 Philips screw driver
Diagonal or other flush cutting hand tool for lead trimming.
Assembly fixture, detailed below.

### Reference Material

PUT SCHEMATICS REF HERE

### Assembly Notes and Tips

As received from JLCPCB.
Note the assembly has the SMT components placed by the board manufacturer and some but not all through hole components.

Write serial number on the PCB assembly at the location provided.
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
Example of serial number written on number 26.
_Further Management of serial numbers is beyond the scope of this document. Each manufacturer must figure something out._

### An Assembly Fixture
We made an assembly assistant / fixture by using a raw PCB with some long #6 screws and nuts to hold at the PCB mounting points.
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

In addition four 4.40 screws with washers and 4-40 nuts to make a 1/8" spacer for holding the LCD and header for soldering.
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

### Assembly Steps

**Bypass U501 USB-UART Chip**
U501 was implemented incorrectly with out a 12MHz cyrstal and so does not function as is.
Wire in a "bypass" USB-UART break out board.
Unsolder R502 and rotate it 90 degrees on the "south" most pad.
Solder 330 Ohm or similar resistor into J601 pins 10 and 11 for ESP32 RXD0 and TXD0 respectively.
Solder the two resistors to each end of a three pin header.
Solder a ground wire to the center pin of the header.

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
Trim the leads  on the LCD side of the PCB so they do not interfere with / contact the LCD.

**DFPlayer in Sockets**
**Important:** we need to solder the DF player header  before soldering the LCD, Assemble with headers

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

Trim the DFPlayer header leads  on the LCD side of the PCB so they do not interfere with / contact the LCD.

**Prep LCD ESD Ground Connections**
Connect J1 and J2 on the back of the LCD by a ball of solder.
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

Put spacers and bolts and mount LCD then, Solder the pins of the LCD.
Next, put the nuts and torque the nuts to about 2inch Lbs.
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

**Solder the LEDS**
Note that the LEDs have a flat edge molded on the plastics part for the cathode. The silk screen shows the flat spot for easy alignment during assembly.

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

Trim the leads, CAUTION: be very careful not to damage the near by transistors.
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

So that you do not mix colors, close the packaging on the white LEDs.
Open the packaging for red LEDs and with a spacer solder it and trim leads.
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

Connect DB9
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

Finish soldering DB9
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

DONE ASSEMBLY

nk25719, 2025-04-28:
# Assembly Test

## Electrical Test

Test location finder

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
The various test points used in the tests below are circled.

### Unpowered Test
These measurems are the first.
Tests to make sure no danger to test  equipment power supply.
If any resistance is TOO LOW or short circuit do not apply power with out finding and fixing the problem.

Test with multi meter.   Record test equipment make and model and SN
- In USA make and model:  **ASTRO /\I**,  DM6000AR, 2327610969
- in LB make and model:   TBD,  tbd

| **Test/DUT**   | **Resistance  TP102-TP101 (Vin)** | **Resistance  TP103-TP101 (+5V)** | **Resistance  TP201-TP101 (VBus)** | **Resistance  TP202-TP101 (V3)** | **Resistance  J103 Pin 2-TP101 (ControllerVcc)** |
|----------------|-------------------------------|-------------------------------|----------------------------------|----------------------------------|------------------------------------------------|
| **Pass Fail**  | Not short,  Capacitive        | Not short,  Capacitive        | Not short,  Capacitive           | Not short,  Capacitive           | Not short,  Capacitive                         |
| **SN: US0001** | >10Meg                        | 1.1K Typical                  | Open                             | 304 Ohm                          | >10Meg                                         |
| **SN: US0002** | >10Meg                        | 1.09K Typical                 | Open                             | 282 Ohm                          | >12Meg                                         |
| **SN: US0003** | >13Meg                        | 1.12K                         | Open                             | 293                              | >14.9Meg                                       |
| **SN: US0004** | >14Meg                        | 1.09K                         | Open                             | 302 Ohm                          | >15.4Meg                                       |
| **SN: US0005** | >14Met                        | 1.1K                          | Open                             | 350 Ohm                          | >13.2Meg                                       |
| **SN: LB0001** |                               |                               |                                  |                                  |                                                |
| **SN: LB0002** |                               |                               |                                  |                                  |                                                |
| **SN: LB0003** |                               |                               |                                  |                                  |                                                |
| **SN: LB0004** |                               |                               |                                  |                                  |                                                |
| **SN: LB0005** |                               |                               |                                  |                                  |                                                |
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
nk25719, 2025-04-28:
# Functional Test

## DFPlayer Functional Test
Load Micro SD card with files from:  https://drive.google.com/drive/u/1/folders/1uwaVFpFQ0uJbVLxVXngsslgTf2tzOCR6
See Issue: DOC, Procedure for Loading MP3 Files in SD Card #188

Connect the DUT to a test speaker.

Load firmware: DFPlayerTD5580ATest into DUT
This firmware can be loaded by USB-serial  interface or by OTA and is OTA ready.

Reset the DUT and confirm audio files play.
Measure peak audio level with ??? SPL meter.
## SPL Measurement Details
### Equipment and DUT
Measurements made with Samsung Galaxy 25S
Using "Sound Meter KUCO Apps"
KRAKE SN US0001

### Audio Files:
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

### Setup
Krake and Speaker on floor. Carpet over concrete
Smart Phone on floor 1Meter away

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

Confirm MAX (peak) audio level of 67 +/- 2 db .  (NOTE this level and tollerence is a GUESS)

|   **Serial#**  	| **Peak SPL dB** 	|   	|   	|    **Note**    	|
|:--------------:	|:---------------:	|:-:	|:-:	|:--------------:	|
| **SN: US0001** 	| 67              	|   	|   	| 28mm Hot Glued 	|
| **SN: US0002** 	|                 	|   	|   	|                	|
| **SN: US0003** 	|                 	|   	|   	|                	|
| **SN: US0004** 	|                 	|   	|   	|                	|
| **SN: US0005** 	|                 	|   	|   	|                	|
| **SN: LB0001** 	|                 	|   	|   	|                	|
| **SN: LB0002** 	|                 	|   	|   	|                	|
| **SN: LB0003** 	|                 	|   	|   	|                	|
| **SN: LB0004** 	|                 	|   	|   	|                	|
| **SN: LB0005** 	|                 	|   	|   	|                	|
|                	|                 	|   	|   	|                	|
|                	|                 	|   	|   	|                	|
|                	|                 	|   	|   	|                	|
|                	|                 	|   	|   	|                	|

## With Factory Test Firmware
Load firmware file: TBD
Test TBD
1. Rotary encoder switch
2. Rotary encoder
3. Mute button

## With Final Test Firmware
Load firmware: GPAD_API
Capture information by serial number
Firmware version, MAC,

|   **Serial#**  | **MAC** | **Firmware Version** |   | **Note** |
|:--------------:|:-------:|:--------------------:|:-:|:--------:|
| **SN: US0001** |         |                      |   |          |
| **SN: US0002** |         |                      |   |          |
| **SN: US0003** |         |                      |   |          |
| **SN: US0004** |         |                      |   |          |
| **SN: US0005** |         |                      |   |          |
| **SN: LB0001** |         |                      |   |          |
| **SN: LB0002** |         |                      |   |          |
| **SN: LB0003** |         |                      |   |          |
| **SN: LB0004** |         |                      |   |          |
| **SN: LB0005** |         |                      |   |          |
|                |         |                      |   |          |
|                |         |                      |   |          |
|                |         |                      |   |          |
|                |         |                      |   |          |

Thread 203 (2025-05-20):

Krake reboots soon after booting

RobertLRead, 2025-05-20:
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

**Describe the Failure / Bug**
_A clear and concise description of what the failure / bug is. Describe the problem NOT the fix._
Short Summary of the expected behavior:
Short Summary of the buggy behavior:

**Device Under Test, aka DUT**
Steps to reproduce the behavior:
1. Model Number:
2. Serial Number(s):
3. Location where failure / bug occurred
4. Hardware configuration. (How connected, any accessories, what else it takes to replicate the system in which the failure occurred.)
5. Extent of Failure
** Is failure intermittent?
** Is failure fixed by power cycling?
** Is failure permanent?

**To Reproduce**
Steps to reproduce the behavior:
1. Go to '...'
2. Click on '....'
3. Scroll down to '....'
4. See error

**Detailed Expected behavior**
_A clear and concise description of what you expected to happen._

**Detailed Actual, "Buggy" behavior**
_A clear and concise description of the buggy behavior._

**Screenshots**
_If applicable, add screenshots to help explain your problem._

**Hardware description**
Model:
Serial Number:
Other:

**Test Equipment**
Model:
Serial Number:

**Additional context**
_Add any other context about the problem here._

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

ForrestErickson, 2025-05-20:
## Normal Boot up Communication on Serial Monitor
DUT is KRAKE SN: US0005, powered from a wall transformer and with USB to UART Adapter.

```
ets Jul 29 2019 12:21:46

rst:0x1 (POWERON_RESET),boot:0x17 (SPI_FAST_FLASH_BOOT)
configsip: 0, SPIWP:0xee
clk_drv:0x00,q_drv:0x00,d_drv:0x00,cs0_drv:0x00,hd_drv:0x00,wp_drv:0x00
mode:DIO, clock div:1
load:0x3fff0030,len:4832
load:0x40078000,len:16460
load:0x40080400,len:4
load:0x40080404,len:3504
entry 0x400805cc
===================================
PubInv
KRAKE_
GPAD_API 0.39
Builtin ESP32 MAC Address:
Alarm Topic:
Broker: public.cloud.shiftr.io
Compiled at: May 12 2025 15:10:05
GNU Affero General Public License, version 3
===================================

PubInv GPAD: enter command in form CDa (C is a char, D is a digit)
MAC:

Starting WiFi as STA
My mac is ec:c9:ff:7d:8e:e8
MAC as char array: ECC9FF7D8EE8
No saved WiFi credentials found.
*wm:AutoConnect
*wm:Connecting to SAVED AP: VRX
*wm:connectTimeout not set, ESP waitForConnectResult...
*wm:AutoConnect: SUCCESS
*wm:STA IP Address: 192.168.1.184
Failed to save WiFi credentials.
Connected to WiFi!
Done With Setup!
InterruptRotator example for the RotaryEncoder library.
```

RobertLRead, 2025-05-20:
Note: After commenting out ALL use of the LCD init and backlight, the buggy behavior goes away---that is, the system does NOT erroneously reboot.

RobertLRead, 2025-05-20:
note: The buggy behavior is removed by NOT turnning on the splash (BUT the LCD does work when invoked later.)  This change:

```
diff --git a/Firmware/GPAD_API/GPAD_HAL.cpp b/Firmware/GPAD_API/GPAD_HAL.cpp
index 122d14f..d23b7aa 100644
--- a/Firmware/GPAD_API/GPAD_HAL.cpp
+++ b/Firmware/GPAD_API/GPAD_HAL.cpp
@@ -327,7 +327,7 @@ void GPAD_HAL_setup(Stream *serialport) {
 #if (DEBUG > 0)
   serialport->println(F("Start LCD splash"));
 #endif
-  splashLCD();
+//  splashLCD();
 #if (DEBUG > 0)
   serialport->println(F("EndLCD splash"));
 #endif
@@ -541,6 +541,7 @@ void clearLCD(void) {

 //Splash a message so we can tell the LCD is working
 void splashLCD(void) {
+  return;
   lcd.init();  // initialize the lcd
   // Print a message to the LCD.
   lcd.backlight();
@@ -662,10 +663,8 @@ void unchanged_anunicateAlarmLevel(Stream *serialport) {

     //   serialport->print("note lvl");
     //   serialport->println(note_lvl);
-
     tone(TONE_PIN, BUZZER_LVL_FREQ_HZ[note_lvl], INF_DURATION);

-
   } else {
     noTone(TONE_PIN);
   }
```
accomplishes this, which is simply commoing out the "splashLCD" call at line 330 in the GPAD_HAL.cpp file.

ForrestErickson, 2025-05-21:
## Here is how to measure the 3.3V supply

Instructions.

The pink trace is the +3.3. Sorry we forgot to put a test point on it.
You can probe it at the pad of D103 for example or on the second hole down to the left of the ESP32.
Ground test point is across the board on the right.
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

I held the probe on the PCB with my left hand and then applied power to the device with my right hand and then when the trace filled the screen I pressed the Run/Stop button on the oscilloscope.

RobertLRead, 2025-05-22:
I was not able to get my oscilloscope to trigger properly. I took the following image by pushing the "force" button on my oscilloscope very quickly after hitting the "reset" button near the ESP32.  It looks pretty similar to yours.

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

@ForrestErickson I am unsure of the next step.

ForrestErickson, 2025-07-07:
Lee googled, "what can cause "SW_RESET" on ESP32"
An AI came back with answers amount which is:

> Code Errors:
> Bugs or errors in the user's code, such as calling functions before they are initialized (e.g., ledcWrite before ledcSetup), can cause panics and resets. Specifically, functions like xQueueGenericReceive() often panic if they receive a corrupted or uninitialized queue.

This lead me to this thread involving the setup of an LCD.
https://esp32.com/viewtopic.php?t=20073#:~:text=Re:%20SW_RESET...,to%20figure%20out%20Please%20help&text=You%20read%20these%20things%20from,task%20*after*%20starting%20Task1code?)

with the following:

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

HOWEVER I infer that this thread us about a case where a Real Time Operating System was involved and the root cause was the code to execute in an unexpected sequence.

ForrestErickson, 2025-07-14:
## LCD Back Light Color

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

On 07/14/2025 11:49 AM EDT Robert Read <read.robert@gmail.com> wrote:

> It is blue.

ForrestErickson, 2025-07-14:
@RobertLRead

Please get the code to where you can reproduce the SW_RESET bug.

Then try adding code to initialize the LCD display
Then a delay of TBD
BEFORE any calls to clear the LCD or the splashLCD.

See the image below.
The LCD should be initialized with delay before line 386.

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

CC: @nk25719

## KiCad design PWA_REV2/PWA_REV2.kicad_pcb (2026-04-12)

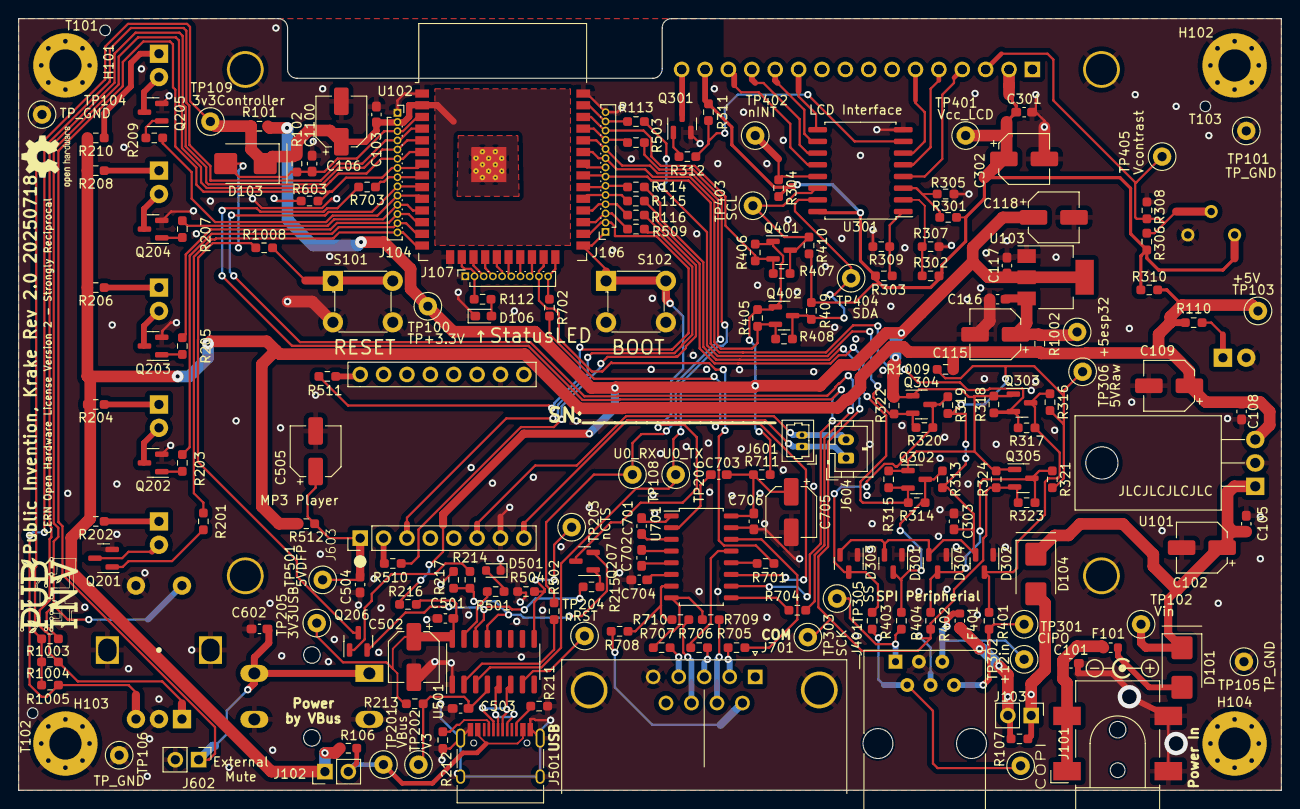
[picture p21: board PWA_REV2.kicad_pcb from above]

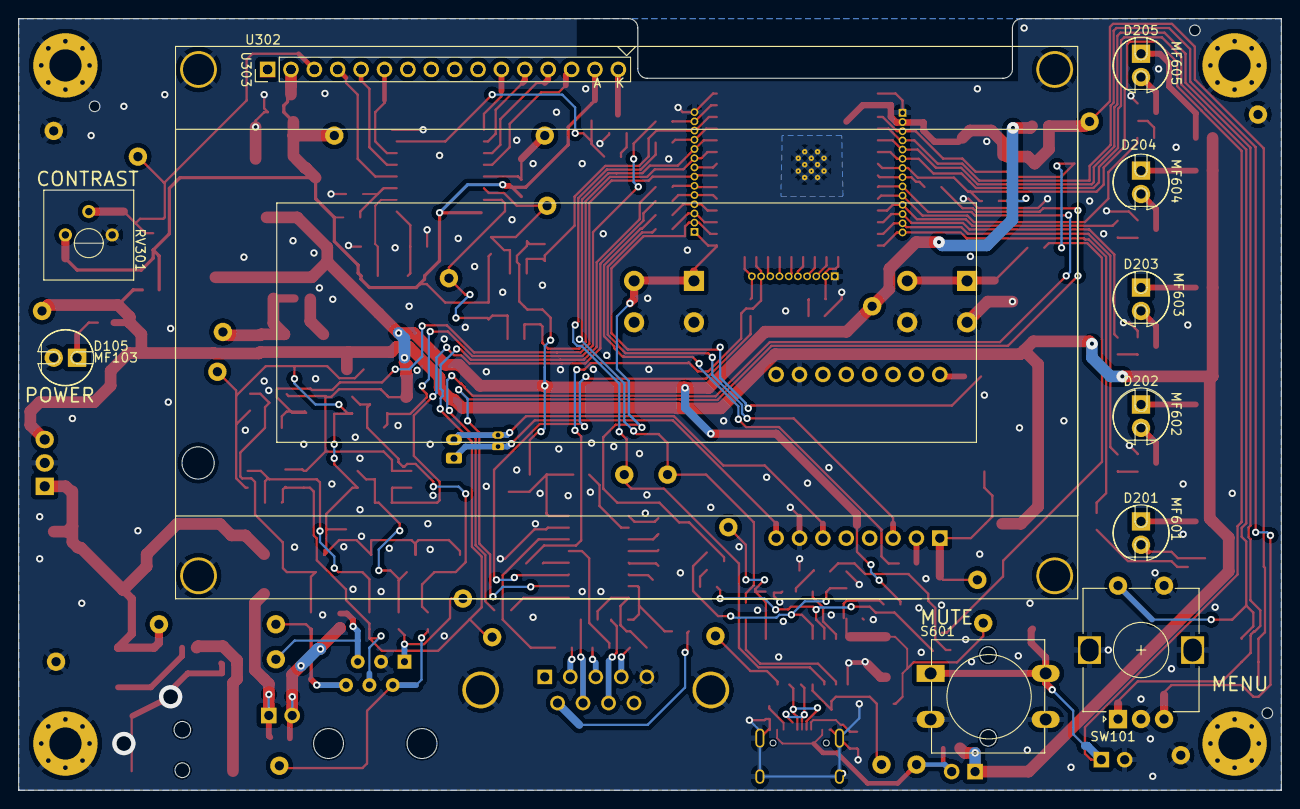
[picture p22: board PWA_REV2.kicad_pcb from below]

Board: 2 copper layers, 137.2 x 83.8 mm, 214 parts (17 on the bottom side), 137 nets.

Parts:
+5esp32: +5esp32; TestPoint_Loop_D1.80mm_Drill1.0mm_Beaded
C101: 39pF; C_0603_1608Metric_Pad1.08x0.95mm_HandSolder
C102, C106, C109, C115, C118, C302, C502, C505, C705: 47uF 16V; CP_Elec_5x5.4
C103, C105, C108, C116, C117, C301, C303, C501, C503, C504, C602, C701, C702, C703, C704, C706, C1100: 100nF; C_0603_1608Metric_Pad1.08x0.95mm_HandSolder
D101, D103, D104: Schottky 2A; D_SMB_POLARITY
D105: LED_T1.75_CLEAR_RED; LED_5mm_Radial
D106: RED 0603; LED_0603_1608Metric_Pad1.05x0.95mm_HandSolder
D201, D202, D203, D204, D205: LED_T1.75_CLEAR_WHITE; LED_5mm_Radial
D301, D302, D303, D304: BAT54S; SOT-23
D501: RED 0603; LED_0603_1608Metric
F101, F401: Polyfuse_Small_1A; Fuse_0603_1608Metric
H101, H102, H103, H104: MountingHole_Pad_3.5mm; MountingHole_3.5mm_Pad_Via
J101: Barrel_Jack_Switch_SMT; BarrelJack_CLIFF_FC681465S_SMT_Horizontal
J102, J103, J602: 0.100_2Pin; PinHeader_1x02_P2.54mm_Vertical
J104, J106: Conn_01x14 1mm; PinSocket_1x14_P1.00mm_Vertical
J107: Conn_01x10 1mm; PinSocket_1x10_P1.00mm_Vertical
J401: RJ12_6P6C_HORZ; RJ12_Amphenol_54601
J501: USB_C_Receptacle_USB2.0; USB_C_Receptacle_HRO_TYPE-C-31-M-12
J601: 1X2P 1.25 mm Header; Molex_PicoBlade_53047-0210_1x02_P1.25mm_Vertical
J603: DFPlayermini; DFPlayer_mini_20241116
J604: 2mm_2Pin; JST_PH_B2B-PH-K_1x02_P2.00mm_Vertical
J701: DE9_Receptacle_MountingHoles; DSUB-9_Female_Horizontal_P2.77x2.84mm_EdgePinOffset9.90mm_H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
MF103, MF601, MF602, MF603, MF604, MF605: U_Box_V104_General_Alarm_Device_LED_Standoff
Q201, Q202, Q203, Q204, Q205, Q206, Q207: MMBT2222A-7-F; SOT-23
Q301, Q302, Q303, Q304, Q305, Q401, Q402: BSS138; SOT-23
R101, R213, R216, R305, R307, R309, R310, R512, R711, R1002, R1009: 1R0; R_0603_1608Metric_Pad0.98x0.95mm_HandSolder
R102, R214, R215, R603, R1003, R1004, R1005: 10K; R_0603_1608Metric_Pad0.98x0.95mm_HandSolder
R106, R107, R306, R308, R314, R317, R320, R323, R407, R408, R707, R708: DNI; R_0603_1608Metric_Pad0.98x0.95mm_HandSolder
R110, R112, R202, R204, R206, R208, R210, R401, R402, R403, R404, R501, R502, R503, R509, R510, R511, R701, R702, R703, R704, R705, R706, R709, R710, R1008: 330R; R_0603_1608Metric_Pad0.98x0.95mm_HandSolder
R113, R114, R115, R116: 39R; R_0603_1608Metric_Pad0.98x0.95mm_HandSolder
R201, R203, R205, R207, R209, R217, R301, R302, R303, R311, R312, R313, R315, R316, R318, R319, R321, R322, R324, R405, R406, R409, R410, R504: 4K7; R_0603_1608Metric_Pad0.98x0.95mm_HandSolder
R211, R212: 5K1; R_0603_1608Metric_Pad0.98x0.95mm_HandSolder
R304: 1K; R_0603_1608Metric_Pad0.98x0.95mm_HandSolder
RV301: POT 0.375 10K; Potentiometer_Bourns_3386P_Vertical
S101, S102: SWITCH_TACTILE_SPST-NO_0.05A_24V; Switch_Tactile_THT_6x6mm
S601: SWITCH_TACTILE_12mmx12mm_SPST-NO_0.05A_24V; SW_PUSH-12mm_WithCap_Green
SW101: RotaryEncoder_Switch; RotaryEncoder_Alps_EC12E-Switch_Vertical_H20mm_MP1_MP2
SYM101: Logo_Open_Hardware_Small; OSHW-Logo2_7.3x6mm_SilkScreen
SYM102: IEC_power_polarity_symbols_barrel_jack_Center_pos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; Symbol_Barrel_Polarity_Center_Positive
T101, T102, T103: ToolingHole_Pad_1.152mm; JLC_ToolingHole_0576mm
TP100: TP+3.3V; TestPoint_Loop_D1.80mm_Drill1.0mm_Beaded
TP101, TP104, TP105, TP106: TP_GND; TestPoint_Loop_D1.80mm_Drill1.0mm_Beaded
TP102: Vin; TestPoint_Loop_D1.80mm_Drill1.0mm_Beaded
TP103: +5V; TestPoint_Loop_D1.80mm_Drill1.0mm_Beaded
TP108: U0_RX; TestPoint_Loop_D1.80mm_Drill1.0mm_Beaded
TP109: 3v3Controller; TestPoint_Loop_D1.80mm_Drill1.0mm_Beaded
TP201: VBus; TestPoint_Loop_D1.80mm_Drill1.0mm_Beaded
TP202: V3; TestPoint_Loop_D1.80mm_Drill1.0mm_Beaded
TP203: nCTS; TestPoint_Loop_D1.80mm_Drill1.0mm_Beaded
TP204: nRST; TestPoint_Loop_D1.80mm_Drill1.0mm_Beaded
TP205: 3V3USB; TestPoint_Loop_D1.80mm_Drill1.0mm_Beaded
TP206: U0_TX; TestPoint_Loop_D1.80mm_Drill1.0mm_Beaded
TP301: CIPO; TestPoint_Loop_D1.80mm_Drill1.0mm_Beaded
TP302: +12in; TestPoint_Loop_D1.80mm_Drill1.0mm_Beaded
TP303: SCK; TestPoint_Loop_D1.80mm_Drill1.0mm_Beaded
TP304: COPI; TestPoint_Loop_D1.80mm_Drill1.0mm_Beaded
TP305: SS; TestPoint_Loop_D1.80mm_Drill1.0mm_Beaded
TP306: 5VRaw; TestPoint_Loop_D1.80mm_Drill1.0mm_Beaded
TP401: Vcc_LCD; TestPoint_Loop_D1.80mm_Drill1.0mm_Beaded
TP402: nINT; TestPoint_Loop_D1.80mm_Drill1.0mm_Beaded
TP403: SCL; TestPoint_Loop_D1.80mm_Drill1.0mm_Beaded
TP404: SDA; TestPoint_Loop_D1.80mm_Drill1.0mm_Beaded
TP405: Vcontrast; TestPoint_Loop_D1.80mm_Drill1.0mm_Beaded
TP501: 5VDFP; TestPoint_Loop_D1.80mm_Drill1.0mm_Beaded
U101: LM7805_TO220; TO-220-3_Horizontal_TabDown
U102: ESP32-WROOM-32E-N4; ESP32-WROOM-32D
U103: AMS1117-3.3; SOT-223-3_TabPin2
U301: PCF8574AT_3_518; SOIC-16W_7.5x10.3mm_P1.27mm
U302: LCD_20x4_Character-GPAD_SCH_LIB; LCD_2004A
U303: Conn_01x16; PinHeader_1x16_P2.54mm_Vertical
U501: CH340B; SOIC-16_3.9x9.9mm_P1.27mm
U701: MAX3232; SOIC-16_4.55x10.3mm_P1.27mm

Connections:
+3.3V: C117.1, C118.1, Q302.1 (G), Q303.1 (G), Q304.1 (G), Q305.1 (G), Q401.1 (G), Q402.1 (G), R101.2, R216.2, R315.2, R318.2, R322.2, R324.2, R405.2, R406.2, R603.2, R711.2, TP100.1, U103.2 (VO)
+5V: C108.1, C109.1, J102.1, R106.2, R110.2, R202.2, R204.2, R206.2, R208.2, R210.2, R310.2, R512.2, R1002.2, R1009.2, TP103.1, U101.3 (VO)
/3v3Controller: C103.1, C106.1, D103.1 (K), J104.2, R101.1, R102.2, R1003.2, R1004.2, R1005.2, TP109.1, U102.2 (VDD)
/+5esp32: +5esp32.1, C115.1, C116.1, R1002.1, U103.3 (VI)
/AlarmAudio/5VDFP: C504.1, C505.1, J603.1 (VCC), R512.1, TP501.1
/LCD And I2C Interface/Vcc_LCD: C301.1, C302.1, R301.2, R302.2, R303.2, R304.2, R306.2, R310.1, R311.2, R409.2, R410.2, RV301.3, TP401.1, U301.16 (VDD), U302.2 (VDD), U302.15 (A)
/LED_BUILTIN: J107.2, R112.2, U102.16 (GPIO13)
/RS232/3v3RS232: C703.1, C705.1, C706.1, R711.1, U701.16 (VCC)
/RS232/DCE_CTS: J701.8, R710.2
/RS232/DCE_RTS: J701.7, R709.2
/RS232/DCE_RX: J701.2, R705.2
/RS232/DCE_TX: J701.3, R706.2
/RS232/RS232_CTS: R707.1, R709.1, U701.8 (R2IN)
/RS232/RS232_RTS: R708.1, R710.1, U701.7 (T2OUT)
/RS232/RS232_RX: R706.1, U701.13 (R1IN)
/RS232/RS232_TX: R705.1, U701.14 (T1OUT)
/RT_ENC_A: J104.5, R1004.1, SW101.A, U102.5 (GPIO39_VN)
/RT_ENC_B: J104.4, R1005.1, SW101.B, U102.4 (GPIO36_VP)
/SPI Peripherial/5VRaw: C303.2, D301.2 (K), D302.2 (K), D303.2 (K), D304.2 (K), R313.2, R316.2, R319.2, R321.2, R1009.1, TP306.1
/SPI Peripherial/+12in: F401.2, J401.5, TP302.1
/SPI Peripherial/MISO: J401.6, R401.2, TP301.1
/SPI Peripherial/MOSI: J401.2, R403.2, TP304.1
/SPI Peripherial/SS: J401.1, R404.2, TP305.1
/USB_UART/3V3USB: C501.1, C502.1, R213.2, R216.1, TP205.1, U501.16 (VCC)
/USB_UART/V3: C503.1, R213.1, TP202.1, U501.4 (V3)
/nS1: J104.6, R1003.1, SW101.S1, U102.6 (GPIO34)
Busy: J106.2, R511.2, U102.26 (GPIO4)
CIPO: J106.7, Q303.2 (S), R317.2, R318.1, U102.31 (GPIO19)
COPI: Q304.2 (S), R113.1, R320.2, R322.1
CTS1: J104.9, R704.1, U102.9 (GPIO33)
ControllerRX: J106.10, R502.1, TP108.1, U102.34 (RXD0/GPIO3)
ControllerRX2: J106.3, R509.2, U102.27 (RX2/GPIO16)
ControllerTX: J106.11, R503.1, U102.35 (TXD0/GPIO1)
ControllerTX2: R116.1, R510.2
ControllerVcc: F401.1, J103.2, R107.1
GND: C101.2, C102.2, C103.2, C105.2, C106.2, C108.2, C109.2, C115.2, C116.2, C117.2, C118.2, C301.2, C302.2, C303.1, C501.2, C502.2, C503.2, C504.2, C505.2, C602.2, C704.2, C705.2, C706.2, C1100.2, D105.2, D106.1 (K), D301.1 (A), D302.1 (A), D303.1 (A), D304.1 (A), D501.1 (K), H101.1, H102.1, H103.1, H104.1, J101.2, J101.3, J104.1, J106.14, J107.1, J401.3, J501.A1 (GND), J501.A12 (GND), J501.B1 (GND), J501.B12 (GND), J501.S1 (SHIELD), J602.2, J603.7 (GND), J603.10 (GND), J701.0 (PAD), J701.5, Q201.2 (E), Q202.2 (E), Q203.2 (E), Q204.2 (E), Q205.2 (E), Q301.2 (S), R211.1, R212.1, R217.1, R305.2, R307.2, R308.1, R309.2, R504.1, RV301.1, S101.3, S101.4, S102.3, S102.4, S601.3, S601.4, SW101.C, SW101.MP1 (A), SW101.MP2 (A), SW101.S2, TP101.1, TP104.1, TP105.1, TP106.1, U101.2 (GND), U102.1 (GND), U102.15 (GND), U102.38 (GND), U102.39 (GND), U103.1 (GND), U301.8 (VSS), U302.1 (VSS), U302.7 (DB0), U302.8 (DB1), U302.9 (DB2), U302.10 (DB3), U302.17 (MH1), U302.18 (MH2), U302.19 (MH3), U302.20 (MH4), U501.1 (GND), U701.15 (GND)
GPIO0: J106.1, Q207.3 (C), S102.1, S102.2, U102.25 (GPIO0)
Light0: J104.14, R201.2, U102.14 (GPIO12)
Light1: J104.13, R203.2, U102.13 (GPIO14)
Light2: J104.12, R205.2, U102.12 (GPIO27)
Light3: J104.11, R207.2, U102.11 (GPIO26)
Light4: J104.10, R209.2, U102.10 (GPIO25)
unnamed: C101.1, F101.2, J101.1, J101.4
unnamed: D101.2 (A), F101.1
unnamed: D104.2 (A), J103.1, R107.2
unnamed: D105.1, R110.1
unnamed: D106.2 (A), R112.1
unnamed: D201.1, R202.1
unnamed: D202.1, R204.1
unnamed: D203.1, R206.1
unnamed: D204.1, R208.1
unnamed: D205.1, R210.1
unnamed: D301.3 (COM), Q302.3 (D), R313.1, R314.1, R404.1
unnamed: D302.3 (COM), Q303.3 (D), R316.1, R317.1, R401.1
unnamed: D303.3 (COM), Q304.3 (D), R319.1, R320.1, R403.1
unnamed: D304.3 (COM), Q305.3 (D), R321.1, R323.1, R402.1
unnamed: D501.2 (A), R501.2
unnamed: J106.4, R116.2, U102.28 (TX2/GPIO17)
unnamed: J106.5, R115.2, U102.29 (GPIO5)
unnamed: J106.6, R114.2, U102.30 (GPIO18)
unnamed: J106.8, U102.32 (DO_NOT_CONNECT)
unnamed: J106.13, R113.2, U102.37 (GPIO23)
unnamed: J107.3, U102.17 (SHD/SD2/GPIO9)
unnamed: J107.4, U102.18 (SWP/SD3/GPIO10)
unnamed: J107.5, U102.19 (SCS/CMD/GPIO11/U1RTS)
unnamed: J107.6, U102.20 (SCK/CLK/GPIO6/U1CTS)
unnamed: J107.7, U102.21 (SDO/SD0/GPIO7)
unnamed: J107.8, U102.22 (SDI/SD1/GPIO8)
unnamed: J501.A5 (CC1), R212.2
unnamed: J501.B5 (CC2), R211.2
unnamed: J603.16 (BUSY), R511.1
unnamed: J603.2 (RX), R510.1
unnamed: J601.2, J603.6 (SPK_1), J604.2
unnamed: J601.1, J603.8 (SPK_2), J604.1
unnamed: J603.3 (TX), R509.1
unnamed: J701.4, R707.2
unnamed: J701.6, R708.2
unnamed: Q201.1 (B), R201.1
unnamed: D201.2, Q201.3 (C)
unnamed: Q202.1 (B), R203.1
unnamed: D202.2, Q202.3 (C)
unnamed: Q203.1 (B), R205.1
unnamed: D203.2, Q203.3 (C)
unnamed: Q204.1 (B), R207.1
unnamed: D204.2, Q204.3 (C)
unnamed: Q205.1 (B), R209.1
unnamed: D205.2, Q205.3 (C)
unnamed: Q206.1 (B), R214.2
unnamed: Q206.2 (E), R215.1, U501.14 (~RTS)
unnamed: Q207.1 (B), R215.2
unnamed: Q207.2 (E), R214.1, R217.2, U501.13 (~DTR)
unnamed: Q301.3 (D), U302.16 (K)
unnamed: Q301.1 (G), R312.1
unnamed: Q401.3 (D), R407.1, R410.1, TP403.1, U301.14 (SCL)
unnamed: Q402.3 (D), R408.1, R409.1, TP404.1, U301.15 (SDA)
unnamed: R1008.2, S101.1, S101.2
unnamed: R303.1, R309.1, U301.1 (A0)
unnamed: R302.1, R307.1, U301.2 (A1)
unnamed: R301.1, R305.1, U301.3 (A2)
unnamed: U301.4 (P0), U302.4 (RS)
unnamed: U301.5 (P1), U302.5 (R/W)
unnamed: U301.6 (P2), U302.6 (E)
unnamed: R311.1, R312.2, U301.7 (P3)
unnamed: U301.9 (P4), U302.11 (DB4)
unnamed: U301.10 (P5), U302.12 (DB5)
unnamed: U301.11 (P6), U302.13 (DB6)
unnamed: U301.12 (P7), U302.14 (DB7)
unnamed: R304.1, TP402.1, U301.13 (~INT)
unnamed: R306.1, R308.2, RV301.2, TP405.1, U302.3 (VO)
unnamed: TP204.1, U501.7 (RST#)
unnamed: R503.2, TP206.1, U501.3 (RXD)
unnamed: R501.1, U501.15 (TNOW)
unnamed: R502.2, U501.2 (TXD)
unnamed: J501.A6 (D+), J501.B6 (D+), U501.5 (UD+)
unnamed: J501.A7 (D-), J501.B7 (D-), U501.6 (UD-)
unnamed: R504.2, TP203.1, U501.9 (~CTS)
unnamed: C701.1, U701.1 (C1+)
unnamed: C701.2, U701.3 (C1-)
unnamed: C702.1, U701.4 (C2+)
unnamed: C702.2, U701.5 (C2-)
unnamed: R701.2, U701.12 (R1OUT)
unnamed: R704.2, U701.9 (R2OUT)
unnamed: R702.2, U701.11 (T1IN)
unnamed: R703.2, U701.10 (T2IN)
unnamed: C703.2, U701.2 (VS+)
unnamed: C704.1, U701.6 (VS-)
RTS1: J104.8, R703.1, U102.8 (GPIO32)
RX1: J107.9, R701.1, U102.23 (GPIO15/U1RXD)
SCL: J106.12, Q401.2 (S), R406.1, R407.2, U102.36 (GPIO22)
SDA: J106.9, Q402.2 (S), R405.1, R408.2, U102.33 (GPIO21)
SPI_SCK: J401.4, Q305.2 (S), R114.1, R323.2, R324.1, R402.2, TP303.1
Switch_Mute: C602.1, J104.7, J602.1, R603.1, S601.1, S601.2, U102.7 (GPIO35)
TX1: J107.10, R702.1, U102.24 (GPIO2/U1TXD)
VBus: J102.2, J501.A4 (VBUS), J501.A9 (VBUS), J501.B4 (VBUS), J501.B9 (VBUS), R106.1, TP201.1
Vin: C102.1, C105.1, D101.1 (K), D104.1 (K), TP102.1, U101.1 (VI)
nCS: Q302.2 (S), R115.1, R314.2, R315.1
nRESET: C1100.1, D103.2 (A), J104.3, Q206.3 (C), R102.1, R1008.1, U102.3 (EN)

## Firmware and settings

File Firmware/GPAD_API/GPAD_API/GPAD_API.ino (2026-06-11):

/* GPAD_API.ino
  The program implements the main API of the General Purpose Alarm Device.

  Copyright (C) 2025 Robert Read

  This program includes free software: you can redistribute it and/or modify
  it under the terms of the GNU Affero General Public License as
  published by the Free Software Foundation, either version 3 of the
  License, or (at your option) any later version.

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
  Change notes:
  20221024 Creation by Rob.
  20221028 Report Program Name in splash screen. Lee Erickson
*/

/* This is a work-in-progress but it has two purposes.
 * It essentially implements two APIs: An "abstract" API that is
 * intended to be unchanging and possibly implemented on a large
 * variety of hardware devices. That is, as the GPAD hardware
 * changes and evolves, it does not invalidate the use of this API.
 *
 * Secondly, it offers a fully robotic API; that is, it gives
 * complete access to all of the hardware currently on the board.
 * For example, the current hardware, labeled Prototype #1, offers
 * a simple "tone" buzzer. The abstract interface uses this as part
 * of an abstract command like "set alarm level to PANIC".
 * The robotic control allows you to specify the actual tone to be played.
 * The robotic inteface obviously changes as the hardware changes.
 *
 * Both APIs are useful in different situations. The abstract interface
 * is good for a medical device manufacturer that expects the alarming
 * device to change and evolve. The Robotic API is good for testing the
 * actual hardware, and for a hobbyist that wants to use the device for
 * more than simple alarms, such as for implementing a game.
 *
 * It is our intention that the API will be available both through the
 * serial port and through an SPI interface. Again, these two modes
 * serve different purposes. The SPI interface is good for tight
 * intergration with a safey critical devices. The serial port approach
 * is easier for testing and for a hobbyist to develop an approach,
 * whether they eventually intend to use the SPI interface or not.
 * -- rlr, Oct. 24, 2022
 */

#include "alarm_api.h"
#include "GPAD_HAL.h"
#include "gpad_utility.h"
#include "setup_status.h"
#include "gpad_serial.h"
#include "Wink.h"
#include <math.h>

#include <WiFi.h>
#include <esp_wifi.h>
#include <esp_heap_caps.h>

#include <PubSubClient.h> // From library https://github.com/knolleary/

#include <WiFiManager.h> // WiFi Manager for ESP32
#include <LittleFS.h>
#include <Preferences.h>
#include <ElegantOTA.h>
#include <FS.h>   // File System Support
#include <Wire.h> // req for i2c comm

#include "WiFiManagerOTA.h"
#include <ESPAsyncWebServer.h>
#include <string.h>
#include <strings.h>
#include <ctype.h>

#include "InterruptRotator.h"

#include "DFPlayer.h"
#include "GPAD_menu.h"
#include "mqtt_handler.h"
#include "operator_settings.h"
#include "spi_broker_mirror.h"
#include "debug_macros.h"

AsyncWebServer server(80);
AsyncWebSocket ws("/ws");

const size_t SERIAL_LOG_MAX_CHARS = 12000;
char serialLogBuffer[SERIAL_LOG_MAX_CHARS + 1];
size_t serialLogLength = 0;

void appendSerialLog(const char *text, size_t len)
{
  if (text == nullptr || len == 0)
  {
    return;
  }

  if (len >= SERIAL_LOG_MAX_CHARS)
  {
    text += (len - SERIAL_LOG_MAX_CHARS);
    len = SERIAL_LOG_MAX_CHARS;
    serialLogLength = 0;
  }
  else if ((serialLogLength + len) > SERIAL_LOG_MAX_CHARS)
  {
    const size_t overflow = (serialLogLength + len) - SERIAL_LOG_MAX_CHARS;
    memmove(serialLogBuffer, serialLogBuffer + overflow, serialLogLength - overflow);
    serialLogLength -= overflow;
  }

  memcpy(serialLogBuffer + serialLogLength, text, len);
  serialLogLength += len;
  serialLogBuffer[serialLogLength] = '\0';
}

class SerialMirrorStream : public Stream
{
public:
  explicit SerialMirrorStream(HardwareSerial &serialPort)
      : port(serialPort) {}

  void begin(unsigned long baud) { port.begin(baud); }
  void setTimeout(unsigned long timeoutMs) { port.setTimeout(timeoutMs); }
  operator bool() const { return static_cast<bool>(port); }

  int available() override { return port.available(); }
  int read() override { return port.read(); }
  int peek() override { return port.peek(); }
  void flush() override { port.flush(); }

  size_t write(uint8_t ch) override
  {
    const char c = static_cast<char>(ch);
    appendSerialLog(&c, 1);
    return port.write(ch);
  }

  size_t write(const uint8_t *buffer, size_t size) override
  {
    appendSerialLog(reinterpret_cast<const char *>(buffer), size);
    return port.write(buffer, size);
  }

private:
  HardwareSerial &port;
};

SerialMirrorStream debugSerial(Serial);

// Initialize WiFi and MQTT clients
WiFiClient espClient;
PubSubClient client(espClient);

WifiOTA::Manager wifiManager(WiFi, debugSerial);

/* SPI_PERIPHERAL
   From: https://circuitdigest.com/microcontroller-projects/arduino-spi-communication-tutorial
   Modified by Forrest Lee Erickson 20220523
   Change to Controller/Peripheral termonology
   Change variable names for start with lowercase. Constants to upper case.
   Peripherial Arduino Code:
   License: Dedicated to the Public Domain
   Warrenty: This program is designed to kill and render the earth uninhabitable,
   however it is not guaranteed to do so.
   20220524 Get working with the SPI_CONTROLER sketch. Made function updateFromSPI().
   20220925 Changes for GPAD Version 1 PCB.  SS on pin 7 and LED_PIN on D3.
   20220927 Change back for GPAD nCS on Pin 10
*/

// SPI PERIPHERAL (ARDUINO UNO)
// SPI COMMUNICATION BETWEEN TWO ARDUINO UNOs
// CIRCUIT DIGEST

/* Hardware Notes Peripheral
   SPI Line Pin in Arduino, IO setup
  MOSI 11 or ICSP-4  Input
  MISO 12 or ICSP-1 Output
  SCK 13 or ICSP-3  Input
  SS 10 Input
*/

#define GPAD_VERSION1

#define DEBUG_SPI 0

#ifndef ENABLE_HEAP_DIAGNOSTICS
#define ENABLE_HEAP_DIAGNOSTICS 0
#endif

// MQTT Broker
const char *const KRAKE_MQTT_BROKER_NAME = "krakepubinv.cloud.shiftr.io";
const char *const KRAKE_MQTT_USER = "krakepubinv";
const char *const KRAKE_MQTT_PASSWORD = "DlDmkWjp4I4kgDcA";
const uint16_t MQTT_BROKER_PORT = 1883;
const size_t MQTT_BROKER_MAX_LEN = 64;
const size_t MQTT_USER_MAX_LEN = 64;
const size_t MQTT_PASSWORD_MAX_LEN = 96;
enum MqttBrokerProfile : uint8_t
{
  MQTT_BROKER_KRAKE_PUBINV = 0,
  MQTT_BROKER_CUSTOM = 1,
};
MqttBrokerProfile mqttBrokerProfile = MQTT_BROKER_KRAKE_PUBINV;
char customMqttBrokerName[MQTT_BROKER_MAX_LEN] = {0};
char customMqttUser[MQTT_USER_MAX_LEN] = {0};
char customMqttPassword[MQTT_PASSWORD_MAX_LEN] = {0};
char connectedMqttBrokerName[MQTT_BROKER_MAX_LEN] = {0};
const char *MQTT_CONFIG_PATH = "/mqtt.json";
const char *MQTT_PREF_NS = "mqttcfg";
const char *MQTT_PREF_PROFILE = "profile";
const char *MQTT_PREF_BROKER = "broker";
const char *MQTT_PREF_USER = "user";
const char *MQTT_PREF_PASSWORD = "password";
uint8_t mqttFailCount = 0;
const uint8_t MAX_EXTRA_TOPICS = 4;
const size_t MAX_TOPIC_LEN = 64;
char subscribe_Extra_Topics[MAX_EXTRA_TOPICS][MAX_TOPIC_LEN];
uint8_t subscribe_Extra_Topic_Count = 0;
const uint8_t MAX_PUBLISH_TOPICS = 8;
char publish_Saved_Topics[MAX_PUBLISH_TOPICS][MAX_TOPIC_LEN];
uint8_t publish_Saved_Topic_Count = 0;
char publish_Default_Topic[MAX_TOPIC_LEN] = {0};
const size_t DEVICE_ROLE_MAX_LEN = 12;
char device_role[DEVICE_ROLE_MAX_LEN] = "Krake";
const char *STATUS_DISCOVERY_TOPIC = "#";
const bool MQTT_DISCOVERY_SUBSCRIBE_ALL = false;
const uint8_t MAX_WATCH_TOPICS = 12;
char watchedTopics[MAX_WATCH_TOPICS][MAX_TOPIC_LEN];
uint8_t watchedTopicCount = 0;
unsigned long wifiResetRequestedAtMs = 0;
unsigned long lastWiFiReconnectAttemptMs = 0;
const unsigned long WIFI_RECONNECT_INTERVAL_MS = 5000;
const unsigned long MQTT_RECONNECT_INTERVAL_MS = 3000;
const uint16_t MQTT_SOCKET_TIMEOUT_SECONDS = 1;
unsigned long lastMqttReconnectAttemptMs = 0;
bool mqttReconnectRequested = false;
bool wifiConnectWinkIssued = false;
enum BrokerState : uint8_t
{
  BROKER_WAITING_WIFI,
  BROKER_CONNECTING,
  BROKER_CONNECTED,
  BROKER_FAILED,
  BROKER_RETRYING,
};
BrokerState brokerState = BROKER_WAITING_WIFI;

const uint8_t MAX_TRACKED_KRAKES = 16;
const unsigned long KRAKE_ONLINE_TIMEOUT_MS = 30000;
const unsigned long TOPIC_PARTICIPATION_TIMEOUT_MS = 120000;
struct TrackedKrake
{
  bool inUse;
  char id[17];
  int rssi;
  unsigned long lastSeenMs;
  unsigned long lastStatusMs;
  unsigned long watchedTopicSeenMs;
  char status[80];
  char lastTopic[MAX_TOPIC_LEN];
};
TrackedKrake trackedKrakes[MAX_TRACKED_KRAKES];

String jsonEscape(const String &raw);
const char *mqttStateDescription(int state);
const char *brokerConnectionStateText();
bool endsWithAckTopic(const char *topic);
bool isAllowedPublishTopic(const String &topic);
bool extractJsonString(const String &json, const char *key, String &value, int startPos = 0, int *valueEndPos = nullptr);
bool writeMqttConfig();
bool loadMqttConfig();
void applyMqttBrokerConfig();
const char *activeMqttBrokerName();
const char *activeMqttUser();
const char *activeMqttPassword();
const char *activeMqttBrokerLabel();
const char *connectedMqttBroker();
bool customMqttBrokerConfigured();
void requestMqttReconnect();
void requestWifiCredentialsReset();
bool selectMqttBrokerProfile(uint8_t profile, bool persist = true);
bool configureCustomMqttBroker(const String &broker, const String &user, const String &password);
bool saveMqttBrokerPreferences();
void loadMqttBrokerPreferences();
bool parseCsvIntoTopics(const String &rawTopics, char dest[][MAX_TOPIC_LEN], uint8_t &count, uint8_t maxTopics);
String joinTopicsCsv(const char topics[][MAX_TOPIC_LEN], uint8_t count);

const size_t MAC_ADDRESS_STRING_LENGTH = 13;
// MQTT Topics, MAC plus an extension
// A MAC addresss treated as a string has 12 chars.
// The strings "_ALM" and "_ACK" have 4 chars.
// A null character is one other. 12 + 4 + 1 = 17
char subscribe_Alarm_Topic[MAX_TOPIC_LEN];
char publish_Ack_Topic[MAX_TOPIC_LEN];
char macAddressString[MAC_ADDRESS_STRING_LENGTH];

#define MAC2STR(a) (a)[0], (a)[1], (a)[2], (a)[3], (a)[4], (a)[5]
#define MACSTR "%02x:%02x:%02x:%02x:%02x:%02x"
#define MACSTR_PLN "%02X%02X%02X%02X%02X%02X"

// // Initialize WiFi and MQTT clients
// WiFiClient espClient;
// PubSubClient client(espClient);

// String myMAC = "";

// #define VERSION 0.02             //Version of this software
#define BAUDRATE 115200
// #define BAUDRATE 57600
// Let's have a 10 minute time out to allow people to compose strings by hand, but not
// to leave data our there forever
// #define SERIAL_TIMEOUT_MS 600000
#define SERIAL_TIMEOUT_MS 1000

// Set LED wink parameters
const int HIGH_TIME_LED_MS = 800; // time in milliseconds
const int LOW_TIME_LED_MS = 200;
unsigned long lastLEDtime_ms = 0;
// unsigned long nextLEDchangee_ms = 100; //time in ms.
unsigned long nextLEDchangee_ms = 5000; // time in ms.

//wifi disconnect event
void onWiFiDisconnect(WiFiEvent_t event, WiFiEventInfo_t info) {
#if (DEBUG > 0)
  debugSerial.print(F("\nWifi Disconnected. Reason: "));
  debugSerial.println(info.wifi_sta_disconnected.reason);
#else
  (void)event;
  (void)info;
#endif

  // Force immediate reconnect attempt in loop (including AP mode).
  lastWiFiReconnectAttemptMs = 0;
  wifiConnectWinkIssued = false;
}


// extern int LIGHT[];
// extern int NUM_LIGHTS;

void serialSplash()
{
  // Serial splash
#if (DEBUG > 0)
  debugSerial.println(F("==================================="));
  debugSerial.println(F(COMPANY_NAME));
  debugSerial.println(F(MODEL_NAME));
  //  debugSerial.println(DEVICE_UNDER_TEST);
  debugSerial.print(F(PROG_NAME));
  debugSerial.println(F(FIRMWARE_VERSION));
  //  debugSerial.println(HARDWARE_VERSION);
  debugSerial.print(F("Builtin ESP32 MAC Address: "));
  debugSerial.println(macAddressString);
  debugSerial.print(F("Alarm Topic: "));
  debugSerial.println(subscribe_Alarm_Topic);
  debugSerial.print(F("Broker: "));
  debugSerial.println(activeMqttBrokerName());
  debugSerial.print(F("Compiled at: "));
  debugSerial.println(F(__DATE__ " " __TIME__)); // compile date that is used for a unique identifier
  debugSerial.println(F(LICENSE));
  debugSerial.println(F("==================================="));
  debugSerial.println();
#endif
}

// A periodic message identifying the subscriber (Krake) is on line.
void publishOnLineMsg(void)
{
  if (!client.connected())
  {
    return;
  }

  const uint32_t MESSAGE_PERIOD_MS = 10000;
  static uint32_t lastPublishMs = 0;
  const uint32_t now = millis();
  if (millisIntervalElapsed(now, lastPublishMs, MESSAGE_PERIOD_MS))
  {
    lastPublishMs = now;

    float rssi = WiFi.RSSI();
    char rssiString[8];

#if (DEBUG > 1)
    debugSerial.print("Publish RSSI: ");
    debugSerial.println(rssi);
#endif

    dtostrf(rssi, 1, 2, rssiString);
    char onLineMsg[32];
    snprintf(onLineMsg, sizeof(onLineMsg), " online, RSSI:%s", rssiString);
    queueMqtt(publish_Ack_Topic, onLineMsg, true);

    // This should be moved to a place after the WiFi connect success
    //  debugSerial.print("Device connected at IPaddress: "); //FLE
    // debugSerial.println(WiFi.localIP());  //FLE

  }
}

const char *activeMqttBrokerName()
{
  return mqttBrokerProfile == MQTT_BROKER_CUSTOM ? customMqttBrokerName : KRAKE_MQTT_BROKER_NAME;
}

const char *activeMqttUser()
{
  return mqttBrokerProfile == MQTT_BROKER_CUSTOM ? customMqttUser : KRAKE_MQTT_USER;
}

const char *activeMqttPassword()
{
  return mqttBrokerProfile == MQTT_BROKER_CUSTOM ? customMqttPassword : KRAKE_MQTT_PASSWORD;
}

const char *activeMqttBrokerLabel()
{
  return mqttBrokerProfile == MQTT_BROKER_CUSTOM ? "Custom" : "Krake PubInv";
}

const char *connectedMqttBroker()
{
  return (client.connected() && connectedMqttBrokerName[0] != '\0') ? connectedMqttBrokerName : "none";
}

bool customMqttBrokerConfigured()
{
  return customMqttBrokerName[0] != '\0';
}

bool saveMqttBrokerPreferences()
{
  Preferences prefs;
  if (!prefs.begin(MQTT_PREF_NS, false)) { setSetupError(SETUP_ERROR_MQTT_PREFERENCES); return false; }
  prefs.putUChar(MQTT_PREF_PROFILE, static_cast<uint8_t>(mqttBrokerProfile));
  prefs.putString(MQTT_PREF_BROKER, customMqttBrokerName);
  prefs.putString(MQTT_PREF_USER, customMqttUser);
  prefs.putString(MQTT_PREF_PASSWORD, customMqttPassword);
  prefs.end();
  return true;
}

void loadMqttBrokerPreferences()
{
  Preferences prefs;
  if (!prefs.begin(MQTT_PREF_NS, true)) { setSetupError(SETUP_ERROR_MQTT_PREFERENCES); return; }
  String broker = prefs.getString(MQTT_PREF_BROKER, "");
  String user = prefs.getString(MQTT_PREF_USER, "");
  String password = prefs.getString(MQTT_PREF_PASSWORD, "");
  const uint8_t profile = prefs.getUChar(MQTT_PREF_PROFILE, MQTT_BROKER_KRAKE_PUBINV);
  prefs.end();
  configureCustomMqttBroker(broker, user, password);
  mqttBrokerProfile = (profile == MQTT_BROKER_CUSTOM && customMqttBrokerConfigured()) ? MQTT_BROKER_CUSTOM : MQTT_BROKER_KRAKE_PUBINV;
}

bool normalizeMqttBrokerName(const String &broker, String &normalized)
{
  normalized = broker;
  normalized.trim();
  if (normalized.startsWith("wss://")) normalized.remove(0, 6);
  else if (normalized.startsWith("ws://")) normalized.remove(0, 5);
  else if (normalized.startsWith("mqtts://")) normalized.remove(0, 8);
  else if (normalized.startsWith("mqtt://")) normalized.remove(0, 7);
  const int pathPos = normalized.indexOf('/');
  if (pathPos >= 0) normalized.remove(pathPos);
  return normalized.length() > 0 && normalized.length() < MQTT_BROKER_MAX_LEN;
}

bool configureCustomMqttBroker(const String &broker, const String &user, const String &password)
{
  String normalizedBroker;
  String normalizedUser = user;
  normalizedUser.trim();
  if (!normalizeMqttBrokerName(broker, normalizedBroker) || normalizedUser.length() >= MQTT_USER_MAX_LEN || password.length() >= MQTT_PASSWORD_MAX_LEN)
  {
    return false;
  }
  normalizedBroker.toCharArray(customMqttBrokerName, sizeof(customMqttBrokerName));
  normalizedUser.toCharArray(customMqttUser, sizeof(customMqttUser));
  password.toCharArray(customMqttPassword, sizeof(customMqttPassword));
  return true;
}

bool selectMqttBrokerProfile(uint8_t profile, bool persist)
{
  if (profile > MQTT_BROKER_CUSTOM || (profile == MQTT_BROKER_CUSTOM && !customMqttBrokerConfigured()))
  {
    return false;
  }
  mqttBrokerProfile = static_cast<MqttBrokerProfile>(profile);
  requestMqttReconnect();
  return !persist || saveMqttBrokerPreferences();
}

void requestMqttReconnect()
{
  mqttReconnectRequested = true;
  connectedMqttBrokerName[0] = '\0';
  lastMqttReconnectAttemptMs = 0;
  mqttFailCount = 0;
  brokerState = (WiFi.status() == WL_CONNECTED) ? BROKER_RETRYING : BROKER_WAITING_WIFI;
  if (client.connected())
  {
    client.disconnect();
  }
}

void applyMqttBrokerConfig()
{
  client.setServer(activeMqttBrokerName(), MQTT_BROKER_PORT);
  client.setSocketTimeout(MQTT_SOCKET_TIMEOUT_SECONDS);
}

bool reconnect(bool force = false)
{
  if (client.connected())
  {
    mqttReconnectRequested = false;
    brokerState = BROKER_CONNECTED;
    return true;
  }

  if (WiFi.status() != WL_CONNECTED)
  {
    brokerState = BROKER_WAITING_WIFI;
    return false;
  }

  const unsigned long now = millis();
  if (!force && lastMqttReconnectAttemptMs != 0 && !millisIntervalElapsed(now, lastMqttReconnectAttemptMs, MQTT_RECONNECT_INTERVAL_MS))
  {
    return false;
  }
  lastMqttReconnectAttemptMs = now;
  mqttReconnectRequested = false;
  applyMqttBrokerConfig();
  brokerState = BROKER_CONNECTING;

  char clientId[sizeof(COMPANY_NAME) + MAC_ADDRESS_STRING_LENGTH + 1];
  snprintf(clientId, sizeof(clientId), "%s-%s", COMPANY_NAME, macAddressString);
  char willPayload[DEVICE_ROLE_MAX_LEN + 9];
  snprintf(willPayload, sizeof(willPayload), "%s offline", device_role);
  debugSerial.print("Attempting MQTT connection at: ");
  debugSerial.print(millis());
  debugSerial.print(" broker=");
  debugSerial.print(activeMqttBrokerName());
  debugSerial.print(" user=");
  debugSerial.print(activeMqttUser());
  debugSerial.print(" ip=");
  debugSerial.print(WiFi.localIP());
  debugSerial.print(" rssi=");
  debugSerial.print(WiFi.RSSI());
  debugSerial.print(" clientId=");
  debugSerial.print(clientId);
  debugSerial.print(" sub=");
  debugSerial.print(subscribe_Alarm_Topic);
  debugSerial.print(" pub=");
  debugSerial.print(publish_Ack_Topic);
  debugSerial.print(" ... ");
  if (client.connect(clientId, activeMqttUser(), activeMqttPassword(), publish_Ack_Topic, 1, true, willPayload))
  {
    debugSerial.print("success at: ");
    debugSerial.println(millis());
    mqttFailCount = 0;
    brokerState = BROKER_CONNECTED;
    strncpy(connectedMqttBrokerName, activeMqttBrokerName(), sizeof(connectedMqttBrokerName) - 1);
    connectedMqttBrokerName[sizeof(connectedMqttBrokerName) - 1] = '\0';
    char onlinePayload[DEVICE_ROLE_MAX_LEN + 8];
    snprintf(onlinePayload, sizeof(onlinePayload), "%s online", device_role);
    queueMqtt(publish_Ack_Topic, onlinePayload, true);
    client.subscribe(subscribe_Alarm_Topic); // Subscribe to GPAD API alarms
    if (MQTT_DISCOVERY_SUBSCRIBE_ALL)
    {
      client.subscribe(STATUS_DISCOVERY_TOPIC);
    }
    for (uint8_t i = 0; i < subscribe_Extra_Topic_Count; i++)
    {
      client.subscribe(subscribe_Extra_Topics[i]);
    }
    for (uint8_t i = 0; i < watchedTopicCount; i++)
    {
      client.subscribe(watchedTopics[i]);
    }
    queueWinkPattern(3); // Triple wink: MQTT connected.
    return true;
  }

  debugSerial.print("failed, rc=");
  debugSerial.print(client.state());
  debugSerial.print(" ");
  debugSerial.println(mqttStateDescription(client.state()));
  mqttFailCount++;
  brokerState = BROKER_FAILED;
  yield();
  return false;
}

const char *mqttStateDescription(int state)
{
  switch (state)
  {
  case MQTT_CONNECTION_TIMEOUT:
    return "connection timeout";
  case MQTT_CONNECTION_LOST:
    return "connection lost";
  case MQTT_CONNECT_FAILED:
    return "connect failed";
  case MQTT_DISCONNECTED:
    return "disconnected";
  case MQTT_CONNECTED:
    return "connected";
  case MQTT_CONNECT_BAD_PROTOCOL:
    return "bad protocol";
  case MQTT_CONNECT_BAD_CLIENT_ID:
    return "bad client id";
  case MQTT_CONNECT_UNAVAILABLE:
    return "server unavailable";
  case MQTT_CONNECT_BAD_CREDENTIALS:
    return "bad credentials";
  case MQTT_CONNECT_UNAUTHORIZED:
    return "unauthorized";
  default:
    return "unknown";
  }
}

const char *brokerConnectionStateText()
{
  switch (brokerState)
  {
  case BROKER_WAITING_WIFI:
    return "Waiting WiFi";
  case BROKER_CONNECTING:
    return "Connecting";
  case BROKER_CONNECTED:
    return "Connected";
  case BROKER_FAILED:
    return "Failed";
  case BROKER_RETRYING:
    return "Retrying";
  default:
    return "Unknown";
  }
}
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
void loop()
{
  // MQTT gets the first and most frequent slices so inbound bursts are drained
  // before comparatively slow LCD/menu/audio work is serviced.
#if defined(KRAKE)
  serviceSpiBrokerMirror();
#endif
  serviceWiFiReconnect();
  serviceMqttClient();
  serviceDeferredReset();

  // Hardware/UI runs after MQTT.  LCD redraws and DFPlayer commands are
  // scheduled/throttled inside GPAD_HAL_loop() so this remains a short slice.
  unchanged_anunicateAlarmLevel(&debugSerial);
  GPAD_HAL_loop();
  serviceMqttClient();

  processSerial(&debugSerial, &debugSerial);
  serviceMqttClient();

  // Here we also process the UART1 using the same routine.
  processSerial(&debugSerial, &uartSerial1);
  serviceMqttClient();

  // Here we will listen for an SPI command...

  // // Now try to read from the SPI Port!
#if defined(GPAD)
  updateFromSPI();
  serviceMqttClient();
#endif

  updateRotator();

  if (menu_just_exited)
  {
    restoreAlarmLevel(&debugSerial);
    menu_just_exited = false;
  }
  if (running_menu)
  {
    lcd.backlight();
    poll_GPAD_menu();
    serviceMqttClient();
  }

#if defined(KRAKE)
  publishOnLineMsg();
  serviceSpiBrokerMirror();
  serviceHeapDiagnostics();
  serviceRuntimeDiagnostics();
  wink(); // The builtin LED
#endif

  serviceMqttClient();
  yield();
}

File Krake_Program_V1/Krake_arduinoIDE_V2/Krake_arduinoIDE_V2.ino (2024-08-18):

#include <WiFi.h>
#include <WebServer.h>
#include <DNSServer.h>
#include <HTTPClient.h>
#include <SoftwareSerial.h>
#include <DFRobotDFPlayerMini.h>
#include <LiquidCrystal_I2C.h>
#include <Wire.h>
#include <WiFiManager.h>

const char* server_address = "192.168.1.3";
const int serverPort = 5500;
const int analogPin = 34;
const int MUTE_BUTTON_PIN = 36; // GPIO 36 for the mute button
const int ON_OFF_BUTTON_PIN = 39; // GPIO 39 for the ON/OFF button

#define LED_PIN 2 // GPIO 2 for the blue LED // ON OFF LED
const int lamp1Pin = 15; // lamp emergency L1
const int lamp2Pin = 4; //lamp emergency L2
const int lamp3Pin = 5; //lamp emergency L3
const int lamp4Pin = 18;//lamp emergency L4
const int lamp5Pin = 19;//lamp emergency L5
const int lamp6Pin = 23; // MUTE LED 

const char* ssidAP = "ESP32-Access-Point";
const char* passwordAP = "123456789";
const byte DNS_PORT = 53;

bool ledState = false; // Initial state of the LED
unsigned long lastDebounceTime = 0; 
unsigned long debounceDelay = 50; // Debounce time in milliseconds
bool lastButtonState = HIGH;
bool currentButtonState;
bool buttonPressed = false;

SoftwareSerial mySoftwareSerial(16, 17);  // RX, TX for DFPlayer
DFRobotDFPlayerMini myDFPlayer;
LiquidCrystal_I2C lcd(0x3F, 20, 4);  // Address 0x3F, 20 columns, 4 rows
WebServer server(80);
DNSServer dnsServer;

String ssid = "";
String password = "";
bool trackPlaying = false;
int lastState = LOW;
unsigned long previousMillis = 0;
const long interval = 100;

const char* htmlPage = R"rawliteral(
<html>
<body>
<h1>Enter Wi-Fi Credentials</h1>
<form action="/connect" method="POST">
SSID:<br>
<input type="text" name="ssid"><br>
Password:<br>
<input type="password" name="password"><br><br>
<input type="submit" value="Submit">
</form>
</body>
</html>)rawliteral";

void setup() {
    Serial.begin(115200);
    pinMode(MUTE_BUTTON_PIN, INPUT_PULLUP); // Set mute button pin as input with pull-up
    pinMode(ON_OFF_BUTTON_PIN, INPUT_PULLUP); // Set ON/OFF button pin as input with pull-up
    pinMode(LED_PIN, OUTPUT);          // Set LED pin as output
    digitalWrite(LED_PIN, LOW);        // Initialize LED to off

    // Initialize lamp pins
    pinMode(lamp1Pin, OUTPUT);
    pinMode(lamp2Pin, OUTPUT);
    pinMode(lamp3Pin, OUTPUT);
    pinMode(lamp4Pin, OUTPUT);
    pinMode(lamp5Pin, OUTPUT);

    // Set up as Access Point
    WiFi.softAP(ssidAP, passwordAP);
    Serial.println("Access Point Created");

    // Set up DNS server to redirect all URLs to the web server
    dnsServer.start(DNS_PORT, "*", WiFi.softAPIP());

    // Set up web server
    server.on("/", handleRoot);
    server.on("/connect", HTTP_POST, handleConnect);
    server.begin();
    Serial.println("Web Server started");

    // Initialize peripherals
    mySoftwareSerial.begin(9600);
    Wire.begin();
    lcd.init();
    lcd.backlight();

    // Initialize WiFiManager
    WiFiManager wm;
    if (!wm.autoConnect("ESP32_AP")) {
        Serial.println("Failed to connect");
        ESP.restart();
    }

    // Connected to WiFi
    Serial.println("Connected to WiFi");
    lcd.clear();
    lcd.setCursor(0, 0);
    lcd.print("WiFi Connected");

    // Start DF player
    startDFPlayer();
    menuOptions();
}

void loop() {
    dnsServer.processNextRequest();
    server.handleClient();
    checkWiFiConnection();
    fetchEmergencyLevelOverWiFi();
    // handleWiFiClientRequests();
    handlePinData();
    muteButton();
    handleONOFFButton();

    }

void handleONOFFButton() {

    bool reading = digitalRead(ON_OFF_BUTTON_PIN);
    
    if (reading != lastButtonState) {
        lastDebounceTime = millis();
    }

    if ((millis() - lastDebounceTime) > debounceDelay) {
        if (reading != buttonPressed) {
            buttonPressed = reading;
            if (buttonPressed == LOW) { // Button pressed (active low)
                ledState = !ledState; // Toggle LED state
                digitalWrite(LED_PIN, ledState ? HIGH : LOW);
                Serial.println(ledState ? "KRAKE ON" : "KRAKE OFF");
                
                // Turn off all GPIO pins when the ON/OFF button is pressed
                if (ledState == LOW) {
                    for (int pin = 0; pin <= 39; ++pin) {
                        if (pin != MUTE_BUTTON_PIN && pin != ON_OFF_BUTTON_PIN && pin != LED_PIN) {
                            digitalWrite(pin, LOW);
                        }
                    }
                }
            }
        }
    }
    lastButtonState = reading;
}


void handleRoot() {
    server.send(200, "text/html", htmlPage);
}

void handleConnect() {
    ssid = server.arg("ssid");
    password = server.arg("password");

    server.send(200, "text/html", "<html><body><h1>Connecting...</h1></body></html>");

    WiFi.softAPdisconnect(true);
    WiFi.begin(ssid.c_str(), password.c_str());

    int timeout = 30;  // 30 seconds timeout
    while (WiFi.status() != WL_CONNECTED && timeout > 0) {
        delay(1000);
        Serial.println("Connecting to WiFi...");
        timeout--;
    }

    if (WiFi.status() == WL_CONNECTED) {
        String connectedPage = "<html><body><h1>ESP32 Connected to Wi-Fi</h1><p>IP Address: " + WiFi.localIP().toString() + "</p></body></html>";
        server.send(200, "text/html", connectedPage);
        Serial.println("Connected to WiFi");
    } else {
        server.send(200, "text/html", "<html><body><h1>Failed to connect. Please try again.</h1></body></html>");
        Serial.println("Failed to connect to WiFi");
        WiFi.softAP(ssidAP, passwordAP);
    }
}

void muteButton() {
    int currentState = digitalRead(MUTE_BUTTON_PIN);
    if (lastState == LOW && currentState == HIGH) {
        Serial.println("Mute Button released");
        if (trackPlaying) {
            myDFPlayer.pause();
            trackPlaying = false;
            delay(600000);  // Alarm paused for 10 minutes
            lcd.clear();
            lcd.setCursor(0, 0);
            lcd.print("Alarm Paused");
        } else {
            myDFPlayer.start();
            trackPlaying = true;
            lcd.clear();
            lcd.setCursor(0, 0);
            lcd.print("Alarm Resumed");
        }
        delay(700);
    }
    lastState = currentState;
}


void handlePinData() {
    int sensorValue = analogRead(analogPin);
    lcd.clear();
    lcd.setCursor(0, 0);
    lcd.print("Analog Pin Value:");
    lcd.setCursor(0, 1);
    lcd.print(sensorValue);
    Serial.println("Sensor Value: " + String(sensorValue));
    sendSensorValueToHTTPServer(sensorValue);
    sendSensorValueOverWiFi(sensorValue);
    int emergencyLevel = fetchEmergencyLevelOverWiFi();
    Serial.println("Received Emergency Level: " + String(emergencyLevel));
    delay(700);
    handleEmergencyLamps(emergencyLevel);
    lcd.clear();
    lcd.setCursor(0, 0);
    lcd.print("Emergency level:");
    lcd.setCursor(0, 1);
    lcd.print(emergencyLevel);
}
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

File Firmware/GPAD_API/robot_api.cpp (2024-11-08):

/* robot_api.cpp
   the "robot" (low-level hardware) api

  Copyright (C) 2022 Robert Read

  This program includes free software: you can redistribute it and/or modify
  it under the terms of the GNU Affero General Public License as
  published by the Free Software Foundation, either version 3 of the
  License, or (at your option) any later version.

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
*/

#include <arduino.h>
#include "robot_api.h"
#include "alarm_api.h"
#include "gpad_utility.h"
#include<SPI.h>

#include <DailyStruggleButton.h>
DailyStruggleButton muteButton;
// Time in ms you need to hold down the button to be considered a long press
unsigned int longPressTime = 1000;
// How many times you need to hit the button to be considered a multi-hit
byte multiHitTarget = 2; 
// How fast you need to hit all buttons to be considered a multi-hit
unsigned int multiHitTime = 400; 


extern const char *AlarmNames[];
extern AlarmLevel currentLevel;
extern bool currentlyMuted;
extern char AlarmMessageBuffer[81];

extern String myMAC;

//For LCD
#include <LiquidCrystal_I2C.h>
#ifdef HMWK
LiquidCrystal_I2C lcd(0x27, 20, 4); // set for default LCD address of 0x27 for a 20 chars and 4 line as in HW
#elif
LiquidCrystal_I2C lcd(0x38, 20, 4); // set the LCD address to 0x27 for a 20 chars and 4 line display in Wokwi, and 0x38 for the physical GPAD board
#endif

//Setup for buzzer.
//const int BUZZER_TEST_FREQ = 130; // One below middle C3. About 67 db, 3" x 4.875" 8 Ohm speakers no cabinet at 1 Meter.
//const int BUZZER_TEST_FREQ = 260; // Middle C4. About ?? db, 3" x 4.875" 8 Ohm speakers no cabinet at 1 Meter.
//const int BUZZER_TEST_FREQ = 1000; //About 76 db, 3" x 4.875" 8 Ohm speakers no cabinet at 1 Meter.
const int BUZZER_TEST_FREQ = 4000; // Buzzers, 3 V 4kHz 60dB @ 3V, 10 cm.  The specified frequencey for the Version 1 buzzer.

const int BUZZER_LVL_FREQ_HZ[] = {0, 128, 256, 512, 1024, 2048};

// This as an attempt to program recognizable "songs" for each alarm level that accomplish
// both informativeness and urgency mapping. The is is to use an index into the buzzer
// level frequencies above, so we can use an unsigned char. We can break the whole
// sequence into 100ms chunks. A 0 will make a "rest" or a silence.a length of 60 will
// give us a 6-second repeat.

const unsigned int NUM_NOTES = 20;
const int SONGS[][NUM_NOTES] = { { 0, 0, 0, 0, 0, 0, 0, 0, 0, 0, 0, 0, 0, 0, 0, 0, 0, 0, 0, 0},
  { 1, 1, 1, 1, 1, 0, 0, 0, 0, 0, 1, 1, 1, 1, 1, 0, 0, 0, 0, 0},
  { 2, 2, 0, 2, 2, 0, 0, 0, 0, 0, 2, 2, 2, 0, 2, 2, 0, 0, 0, 0},
  { 3, 3, 3, 0, 3, 3, 3, 3, 0, 3, 3, 3, 0, 3, 3, 3, 0, 0, 0, 0},
  { 4, 0, 4, 0, 4, 0, 4, 0, 0, 0, 4, 0, 4, 0, 4, 0, 4, 0, 0, 0},
  { 4, 4, 2, 0, 4, 4, 2, 0, 4, 4, 2, 0, 4, 4, 2, 0, 4, 4, 2, 0}
};
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

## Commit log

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2024-11-18 fix issue #82 and fix issue #84
    [GPAD_API.ino, GPAD_HAL.cpp]
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2024-11-22 Fixed pin errors in schematic symbol of Esp32.
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2024-11-23 Fixed the DFPlayer schematic symbol, for pin electrical type and symbol name.
    [AlarmAudio.kicad_sch]
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2024-11-27 Fix spelling error in PMD_Processing_MQTT.pde
    [GPAD_API.ino]
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2024-12-06 Fix #94, with a test file
    [GPAD_API.ino, GPAD_HAL.cpp, GPAD_HAL.h]
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2024-12-09 Adding a button to the PMD. Fix, stop, button blinking from LED.
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2024-12-12 Editted USB C schematic symbol. Replaced the USB B with the USB C.
    [USB_UART.kicad_sch]
2024-12-14 Replaced USB B with USB C connector.
    [PCBa_KRAKE.kicad_sch, USB_UART.kicad_sch]
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2024-12-15 removed ATMEGA328P and replaced it with ESP32. Added a hierarchial sheet for the RS232.
    [PCBa_KRAKE.kicad_sch]
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2024-12-15 Corrected UART1 labels. Renamed Esp32 as U102.
    [Enclosure.kicad_sch, PCBa_KRAKE.kicad_sch, RS232.kicad_sch]
2024-12-15 Fixing Global label of RS232.
    [Enclosure.kicad_sch, PCBa_KRAKE.kicad_sch, RS232.kicad_sch]
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2024-12-19 Fixing #103, making LCD_ADDRESS setabble
    [GPAD_API.ino, GPAD_HAL.cpp, GPAD_HAL.h]
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2024-12-21 ERC Okay, waved warnings on symbol issues.
    [AlarmAudio.kicad_sch, PCBa_KRAKE.kicad_sch, SPI Peripherial.kicad_sch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]
2024-12-22 Fixing annotations.
    [AlarmAudio.kicad_sch, USB_UART.kicad_sch]
2024-12-22 Fixing annotations and removing duplicates, PCBA ready to be routed for KRAKE.
    [PCBa_KRAKE.kicad_pcb, PCBa_KRAKE.kicad_sch]
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2024-12-26 Added net names per issue 120.
    [PCBa_KRAKE.kicad_pcb, PCBa_KRAKE.kicad_sch]
2024-12-26 Adding clearance space around the mounting screws of the LCD.
    [PCBa_KRAKE.kicad_pcb]
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2024-12-29 PMD_Processing_MQTT. Change button color same as broker visualizer.
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2025-01-01 GPAD_API changed to Version 0.23. Setup UART1 and UAR2 for pins of KRAKE PCB. Fixes incompatibility with DFPlayer found in version 0.22.
    [GPAD_HAL.cpp, GPAD_HAL.h]
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2025-01-02 Add to PMD_Processing_MQTT.pde Fix the new i command.
    [GPAD_API.ino]
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2025-01-07 Reverted the PCBa back from 06 jan commit. 127 lines of unexpectd merge.
    [PCBa_KRAKE.kicad_pcb]
2025-01-07 UPsized vias, and replaced all mcro vias with vias.
    [PCBa_KRAKE.kicad_pcb]
2025-01-08 Clearance DRC Errors, by changing the clearance of the default Net Class from 0.2 to 0.15mm.
2025-01-09 Rerouting and connecting the USB C and the CH34T again. DRC errors related to this connection are cleared.
    [PCBa_KRAKE.kicad_pcb]
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2025-01-10 Corrected the voltage connection for the mute switch, from 5V to 3V3. Rerouted and reconnected the tracks for R603.
    [PCBa_KRAKE.kicad_pcb, RS232.kicad_sch, SPI Peripherial.kicad_sch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]
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2025-01-10 Got rid of ERC spoke errors by providing more ground vias and ground fills.
    [PCBa_KRAKE.kicad_pcb]
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2025-01-11 Cleared all DRC issues and Warnings.
    [LCD And I2C Interface.kicad_sch, PCBa_KRAKE.kicad_pcb]
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2025-01-11 Tighten up ground holes.
    [PCBa_KRAKE.kicad_pcb]
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2025-01-15 Fixed Hardware, PCB of 20250114, J601 Interferes with DFPlayer SD Card Egress/Ingress #137
    [AlarmAudio.kicad_sch, PCBa_KRAKE.kicad_pcb]
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2025-01-18 Adding new CH340T footprint. Fixing through hole pads and routings.
    [PCBa_KRAKE.kicad_pcb, USB_UART.kicad_sch]
2025-01-23 Found missing part numbers. ESP32.
    [LCD And I2C Interface.kicad_sch, PCBa_KRAKE.kicad_pcb, PCBa_KRAKE.kicad_sch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]
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2025-01-25 Editting missing feilds in the builk editor, And added a pin header for the LCD.
    [AlarmAudio.kicad_sch, LCD And I2C Interface.kicad_sch]
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2025-02-15 Made allowance to the Boss inner and outer diameter due to 3D printer undersize error.
    [BOSS_ONLY_FILE.scad]
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2025-02-16 Firmware, ESP32: Multitasking sketch.Similar to Do Nothing but, It blinks 4 LEDs and Serial Splash. issue 158.
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2025-04-03 Update GPAD_API.ino for company name at MQTT broker. Version 0.26
    [GPAD_API.ino]
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2025-04-09 Update GPAD_API for real KRAKE hardware. Comment out Serial1 init. Now finishes setup() but WiFi connect fails.
    [GPAD_API.ino, GPAD_HAL.cpp]
2025-04-13 PMD_Processing_MQTT.pde. Change the MAC for KRAKE_US0005 to upper case. Lower case did not work.
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2025-04-18 GPAD_HAL.cpp, Fixed incorrect transmit and receive of UART1 and UART2.
    [GPAD_HAL.cpp, GPAD_HAL.h]
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2025-04-23 fixing #184, exposing ability to read state
    [GPAD_API.ino]
2025-04-24 updating the size of a buffer to try to fix issue #185
    [GPAD_HAL.cpp]
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2025-04-25 enclosure/U_Box_V105_Krake_RevB.scad, Correcting the Rotary Encoder hole.
    [U_Box_V105_Krake_RevB.scad]
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2025-04-26 DFPlayerTD5580ATest.ino. Add some other attemps to manage playing all files using BUSY. Not working.
    [DFPlayerTD5580ATest.ino]
2025-04-26 enclosure/U_Box_V105_Krake_RevB.scad, Correcting the Text orientation on the front panel Krake.
    [U_Box_V105_Krake_RevB.scad]
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2025-04-29 U_Box_V105_Krake_RevB.scad, Fixing the Zpos of the clamp so it embed in the bottom shell.
    [U_Box_V105_Krake_RevB.scad]
2025-04-30 DFPlayerTD5580ATest.ino Fix the BUSY led monitor by making the Busy pin an INPUT_PULLUP
    [DFPlayerTD5580ATest.ino]
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2025-05-01 DFPlayerTD5580ATest.ino, make function to play file only if not Busy. Not correctly working. Remove experimental code and white space.
    [DFPlayerTD5580ATest.ino, OTA.ino]
2025-05-04 DFPlayerTD5580ATest.ino. Fix the parser for index.html.
    [OTA.ino]
2025-05-06 Update README.md
    README.md for PCB, Fix description of the link to the PCB preview.
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2025-05-08 addin revision and fixing speaker holder position
    [U_Box_V105_Krake_RevB.scad]
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2025-05-31 GPAD_API, Fixed encoder firmware so that it changes positions once every one detent.
    [InterruptRotator.cpp, InterruptRotator.h]
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2025-06-06 StudModules.scad, modify for shorter and smaller diamater 4mm insert for Krake. U_Box_V105_Krake_RevB.scad move StudModule flush with shell.
    [StudModules.scad, U_Box_V105_Krake_RevB.scad]
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2025-06-29 factoryTest/SPI/KRAKE_wOTA_SPI_Controller, fixed LCD bug and added i2c scanner instead of hard coding the i2c address, ready to proceed with SPI factorytest 01.
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2025-07-08 improving definition of LIMIT_POWER_DRAW, though bug is no longer relevant.
    [GPAD_API.ino, GPAD_HAL.cpp]
2025-07-09 Menu now only begins when you rotate, and alarm level is restored correctly
    [GPAD_API.ino, GPAD_HAL.cpp, GPAD_HAL.h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]
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2025-07-18 LCD And I2C Interface.kicad_sch, Change U303 for BOM only. Not in PCB. This clears nearly 100 DRC errors. Remaining errors are known and chosen to ignore.
    [LCD And I2C Interface.kicad_sch, PCBa_KRAKE.kicad_pcb]
2025-07-18 PWA_REV2.kicad_pcb, DRC errors at LCD keep out are ignored. Unconnected ends warnings were fixed.
    [PWA_REV2.kicad_pcb]
2025-07-21 USB_UART.kicad_sch, replaced CH340T with CH340B. New schematic symbol CH340B.
    [USB_UART.kicad_sch]
2025-07-21 USB_UART.kicad_sch, flipped the emmiter and the collctor for Q207. Added NC symbols for U303.
    [LCD And I2C Interface.kicad_sch, USB_UART.kicad_sch]
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2025-07-27 Fixed the previous PWA_REV_2 file by added the changes of the USB UART. PCBa_krake is reverted to when no changes done to the schem.
    [AlarmAudio.kicad_sch, AlarmLights5.kicad_sch, Enclosure.kicad_sch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]
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2025-08-02 PWA_REV2.kicad_sch, updated the footptint of the testpoint to 1mm hole and corrected description.
    [LCD And I2C Interface.kicad_sch, PWA_REV2.kicad_sch, USB_UART.kicad_sch]
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2025-08-07 AlarmAudio.kicad_sch, replaced the J601 part by a Molex part and updated the footprint.
    [AlarmAudio.kicad_sch]
2025-08-08 AlarmAudio.kicad_sch, issue 176, Adding a 2mm JST 2pin header speaker connector.
    [AlarmAudio.kicad_sch]
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2025-08-10 AlarmAudio.kicad_sch, Renamed j603 to clear duplicate ERC error.
    [AlarmAudio.kicad_sch]
2025-08-10 PWA_REV2.kicad_pcb, fixed the silkscreen placement, issue 175.
    [PWA_REV2.kicad_pcb]
2025-08-10 PWA_REV2, Made a new Footprint, saved it in the GeneralPurposeAlarmDevicePCB, with the name D_SMB_POLARITY. Updated the schematic with the Diode Footprint. Issue 237.
    [PWA_REV2.kicad_sch]
2025-08-10 PWA_REV2, Customised the rotary encoder schematic and footprint for mounting pad pins, issue 252.
    [PWA_REV2.kicad_pcb, PWA_REV2.kicad_sch]
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2025-08-15 PWA_REV2, Corrected test points footprints.
    [PWA_REV2.kicad_sch]
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2025-08-18 PWA_REV2, Cleared clearance violatoin and thermal relief DRC errors.
    [PWA_REV2.kicad_pcb]
2025-08-19 PWA_REV2, Cleared DRC errors.
    [PWA_REV2.kicad_pcb]
2025-08-19 PWA_REV2, Cleared DRC errors, fixed R211.
    [PWA_REV2.kicad_pcb]
2025-08-19 PWA_REV2, Cleared DRC errors, thermal relief on C103.
    [PWA_REV2.kicad_pcb]
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2025-08-21 PWA_REV2, cleared a DRC error on mf103. Footprint does not match a copy in library.
    [PWA_REV2.kicad_pcb, PWA_REV2.kicad_sch]
2025-08-21 PWA_REV2, cleared a DRC error on U302. Footprint does not match a copy in library.
    [PWA_REV2.kicad_pcb]
2025-08-23 PWA_REV2, solved issue 239, added functionality discription to D106, and similarly we corrected Schematic and PCB text for MENU BOOT RESET MUTE CONTRAST POWER.
    [AlarmAudio.kicad_sch, LCD And I2C Interface.kicad_sch, PWA_REV2.kicad_pcb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]
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2025-08-25 PWA_REV2, resolved issue 255, added several 3d models.
    [AlarmAudio.kicad_sch, LCD And I2C Interface.kicad_sch, Molex_01x02_1.25mm_0530470210_.stp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]
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2025-08-29 PWA_REV2.kicad, moved the ref designator for C118 to beside the positive terminal. Replaced several ground symbols on the LCD page.
    [LCD And I2C Interface.kicad_sch, PWA_REV2.kicad_pcb, PWA_REV2.kicad_sch]
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2025-09-06 PWA_REV2, We corrected Assembly Type for some components, and we added the JLCPCB PN for the DB9 and the CH340B.
    [AlarmAudio.kicad_sch, PWA_REV2.kicad_pcb, PWA_REV2.kicad_sch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]
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2025-09-14 gerbers, generated and submitted files to PCPWAY to place an order, PWA_Rev, corrected and fixed the MPN and description of components.
    [AlarmAudio.kicad_sch, BOM_PCBWAY_REV2KiCad6_250910_1400.csv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]
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2025-09-19 PWA_REV2, Hardware, fixed inadequate trace width 3V3Controller net name issue 261
    [PWA_REV2.kicad_pcb]
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2025-10-16 replaced 'mqtt_serve' with 'mqtt_broker_name' in project
    [GPAD_API.ino]
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2025-11-13 PWA_REV2/PWA_REV2.kicad_pcb, Update for the actualy Mute key cap. Fixed MAX3232 part number.
    [AlarmAudio.kicad_sch, PWA_REV2.kicad_pcb, RS232.kicad_sch]
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2025-11-13 PWA_REV2.kicad_pcb, again fix the KeyCap footpring and export a STEP file.
    [PWA_REV2.kicad_pcb]
2025-11-21 Update schematic, PCB and PCB Footprint for S101/S102 3D model. Correct schematic so BOM will generate correctly in future with TE part.
    [PWA_REV2.kicad_pcb, PWA_REV2.kicad_sch, c-1825910-7-c-3d.stp]
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2025-11-27 RAW_PWA_REV2KiCad6_250910_1400.xls, fix descroption for 28mm speaker enclosure parts.
    [RAW_PWA_REV2KiCad6_250910_1400.xls]
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2025-11-30 add access for reset and debug buttons modules to the encloser top shell
    [U_Box_V105_Krake_RevB.scad, U_Box_V105_Krake_RevB2.3mf, U_Box_V105_Krake_RevB2.stl]
2025-12-01 Adding files to preserve while fixing merge conflicts.
    [200--T-B16W732620A_WithAnswers.xlsx, AlarmAudio.kicad_sch, BOM_PCBWAY_REV2KiCad6_250910_1400.csv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]
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2025-12-11 #273: Setting correct baud rate
    - The baud rate with PlatformIO defaults to 9800
    - The correct baud rate for the serial connection with the ESP32-WROOM is 115200
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2025-12-19 add snap lock to the cover
    [COVER.scad, COVER.stl, COVER_v2.stl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]
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2025-12-27 Fix Serial prompt input (line-based),abort prompts via menu keys,and DO NOT play DF audio if SD missing.
    [FactoryTest_wMenu.ino]
2025-12-27 At v0.4.0 bugs fixed.
    [FactoryTest_wMenu.ino]
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2026-01-02 fixed SPi, version v 0.4.2.2
    [FactoryTest_wMenu.ino]
2026-01-03 fixed kicad project issue.
    [10K, BOURNS 3362P-103LF.STEP, 12mmx12mm With Green cap.stp, 200--T-B16W732620A_WithAnswers.xlsx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]
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2026-01-11 Update Krake_Test_and_Assembly_Procedure.md
    Fix images for unpowered, powered tests.
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2026-01-12 (#206): API Version is stored in class, no longer a compile time argument
    - The GPAD API version is now hardcoded as an actual value
    - It is not something that should be able to be changed by a compilation flag
    [GPAD_HAL.cpp, GPAD_HAL.h]
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2026-01-14 Update Krake_Test_and_Assembly_Procedure.md
    Add image of LCD with only J2.
    Add zip file with FreeCAD file and STL file for assembly fixture, Platfom PWA.
2026-01-18 split the recessed area into two part with snap mechanisme and add two new buttons access for the reset and boot buttons
    [COVER.scad, U_Box_V105_Krake_RevB.scad, button_cap.scad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]
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2026-01-22 Corrected the print statements indexings
    [FactoryTest_wMenu.ino]
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2026-01-30 enclosure/COVER.scad, cleaning the code; and fixing some issues of the dimentions of the drafted pins
    [COVER.scad]
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2026-01-31 fixed the position of the heat insert and the recessed area to be automatically changed and responsive to the height changes of the enclosure for all soeaker heights.
    [U_Box_V105_Krake_RevB.scad]
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2026-02-01 enclosure/U_Box_V105_Krake_RevB.scad, fixing the recess and door positions; making the recess and door moduler by turn on/off the module or sub-modules;
    [U_Box_V105_Krake_RevB.scad, flex_cover.scad, recessed.scad]
2026-02-01 enclosure/U_Box_V105_Krake_RevB.scad, fixing the X and Y position of the door and recess when Krake_rev2_76mmSPK is off
    [U_Box_V105_Krake_RevB.scad]
2026-02-03 (#342): Cast command back to char to safely made it printable (#345)
    * (#342): Cast command back to char to safely made it printable
    * (#342): Reverting change from another commit
    - hash: a62964889d98812e44f55db9fa59c8d4e938ad94
    - link:
    https://github.com/PubInv/krake/commit/a62964889d98812e44f55db9fa59c8d4e938ad94
    [GPAD_API.ino, GPAD_HAL.cpp]
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2026-02-05 Fix DFPlayer test to fail cleanly when hardware is missing
    [FactoryTest_wMenu.ino]
2026-02-07 PWA_REV2.kicad_pcb, fixed merge conflict with stale part numbers on MAX232 and tac switch
    [PWA_REV2.kicad_pcb]
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2026-02-07 enclosure/U_Box_V105_krake_RevB.scad, removed the shelf and the hole opening from, fixed the rotary encoder hole location, modulate the enclosure, fix the size of the speaker grill and te speaker box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
    [U_Box_V105_Krake_RevB.scad]
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2026-02-08 enclosure/U_Box_V105_Krake_RevB.scad, editting the thickness of the speaker box and translated it on the z axis to remove prevent floating objects.
    [U_Box_V105_Krake_RevB.scad]
2026-02-08 enclosure/U_Box_V105_Krake_RevB.scad, fixing merging conflixts, translating the recessed area and the door and bumped the version to 2.6
    [U_Box_V105_Krake_RevB.scad]
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2026-02-09 adding the modified exported file for the TSHELL, after the rotation of the door is fixed.
    [U_Box_V105_Krake_RevB_recessedArea_wodoorV2.6.3mf]
2026-02-09 enclosure/U_Box_V105_Krake_RevB.scad, widen the sd card acess area; rotate the door locing in the open position; remove the clearance for the recess snaps
    [COVER.scad, U_Box_V105_Krake_RevB.scad, recessed.scad]
2026-02-12 Fix link to Krake Test and Assembly Procedure
    Updated the link to the Krake Test and Assembly Procedure document to point to the main branch.
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2026-02-18 FIxing the GPAD_BShell, in U_Box_V105_Krake_RevB.
    [U_Box_V105_Krake_RevB.scad]
2026-02-23 enclosure/U_Box_V105_Krake_RevB.scad, fixed the render of the B-shell.
    [U_Box_V105_Krake_RevB.scad]
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2026-02-26 COVER.scad, fix the door not opening problem
    [COVER.scad]
2026-02-28 filing and fixing the path url for the imported models.
    [BOSS_ONLY_FILE.3mf, BOSS_ONLY_FILE.scad, BOSS_ONLY_FILE.stl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]
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2026-03-08 Replaced the single file for rear and front panel with two files for each back and front panel. Exported as stl.
    [U_Box_V104_General_Alarm_Device_button.step, U_Box_V105_Krake_RevB2.3mf, U_Box_V105_Krake_RevB_BPanL_V3.3mf.stl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]
2026-03-08 removed dynamic parsing in loop and tried fixing the 'break' causing reboot
    [FactoryTest_wMenu.ino]
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2026-03-10 add ElegantOTA and fix LittleFS boot mount
    [FactoryTest_wMenu.ino]
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2026-03-12 Update assembly procedure with issue reference
    Added reference to issue #274 for library specifications.
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2026-03-14 enclosure, added missing line for recess module;added stl files to print
    [Recess_bottom.stl, SD_door.stl, U_Box_V105_Krake_RevB.scad]
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2026-03-17 added missing test case of mute button
    [FactoryTest_wMenu.ino]
2026-03-18 cleaning compiling error after merging PR 407.
    [FactoryTest_wMenu.ino]
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2026-03-20 Fix connector reference and enhance ElegantOTA instructions
    Updated instructions for connecting the SPI connector and clarified the ElegantOTA setup process.
2026-03-20 fixing the stl files filing.
    [Recess_bottom.stl, SD_door.stl]
2026-03-21 Fixed DFPlayer init issue
    [FactoryTest_wMenu.ino]
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2026-03-22 GPAD_API.ino, Make a #define to swith broker to HIVEMQ. COmment the MQTT port type.
    [GPAD_API.ino]
2026-03-23 GPAD_API.ino, Insterument the MQTT client (broker) loss of broker and add reconnect.
    [GPAD_API.ino]
2026-03-23 GPAD_API.ino, Print URL of broker on loss of client.
    [GPAD_API.ino]
2026-03-23 re-enable DFPlayer ACK mode after begin() to prevent intermittent false FAILs on slow SD cards
    [FactoryTest_wMenu.ino]
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2026-03-26 Correct screw types and add images in assembly procedure
    Updated assembly procedure with correct screw types and added images for clarity.
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2026-03-31 fixing the dfplayer enableAck() compilation error
    [FactoryTest_wMenu.ino]
2026-03-31 fixing the dfplayer not detcted error
    [FactoryTest_wMenu.ino]
2026-03-31 Fix DFPlayer: comment out private enableACK(), move detected print after begin()
    [FactoryTest_wMenu.ino]
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2026-04-01 fixed wifi test after migration
    [FactoryTest_wMenu.ino]
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2026-04-04 issue 261 making the 3v3controller trace thicker.
    [PWA_REV2.kicad_pcb]
2026-04-04 Hardware, PWA, Add a Jumper to BOM for J102 so that USB Connector Can Power Krake, issue 312.
    :q
    q
    [AlarmAudio.kicad_sch, AlarmLights5.kicad_sch, Enclosure.kicad_sch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]
2026-04-04 fixed R212 Silk Screen Edge Cut, issue 277
    [PWA_REV2.kicad_pcb]
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2026-04-07 replaced delay with millis()
    [FactoryTest_wMenu.ino]
2026-04-09 DFPlayer: detect TD5580 clone via readState(), fail init and warn operator if incompatible module found
    [FactoryTest_wMenu.ino]
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2026-04-10 (#387): Added missing std::move when returning AlarmCommand
    - Since the Copy constructor is deleted from the AlarmCommand the Move
    construcctor must be used
    - in the ::buildAlarmMessage() method it was not using std::move so the
    returned AlarmMessage was in a invalid state
    [GPAD_API.ino]
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2026-04-11 Revert "Feature/387 gpap protocol"
    [GPAD_API.ino, GPAD_HAL.cpp, GPAD_HAL.h]
2026-04-11 Revert "Revert "Feature/387 gpap protocol""
    [GPAD_API.ino, GPAD_HAL.cpp, GPAD_HAL.h]
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2026-04-12 Revert "Hardware, PWA, Add a Jumper to BOM for J102 so that USB Connector Can Power Krake, issue 312."
    This reverts commit c2819b8ee4999f733f52d823f88f6aefd6456fcc.
    [AlarmAudio.kicad_sch, AlarmLights5.kicad_sch, Enclosure.kicad_sch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]
2026-04-12 revert: PWA_REV2.kicad_pcb to pre-kicad 9 version
    [PWA_REV2.kicad_pcb]
2026-04-12 revert: restore deleted parts contents
    As per conversation with Lee and Nagham, restored contents of parts
    folder from commit 4ae03d0685b6c7c54304d8b0efb8c13b56f51033
    Partial revert of 0f1ff9be131bdd10c9d95aa23c7a215d2429a8bf
    [10K, BOURNS 3362P-103LF.STEP, 12mmx12mm With Green cap.stp, 2004A_ap214.STEP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]
2026-04-12 revert: return to fabricated PCB (PWA2)
    [PWA_REV2.kicad_pcb]
2026-04-12 fixing the B_shell missing when krake is on; hiding the ring when rendering the small spk version
    [B_shell.scad, General_paramters.scad, U_Box_V105_Krake_RevB.scad]
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2026-04-12 fixing the silkscreen for R212 and adding Pinsockets 1x8 to mount the dfplayer on.
    [PWA_REV2.kicad_pcb]
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2026-04-13 fix lcd extern conflict
    [GPAD_HAL.h]
2026-04-13 add more warp function to the lcdWarper and chnage the LiquidCrystal_I2C at RickmanLiquidCrystal_I2C.h to LCDWrapper.
    [GPAD_HAL.cpp, GPAD_HAL.h]
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2026-04-16 bugfix: return early from setupDFPlayer when no module detected to prevent main loop blocking
    [DFPlayer.cpp]
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2026-04-18 Add settings actions for wifi reset, mute, and MQTT config
    [GPAD_API.ino]
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2026-04-19 Fix monitor page to stream mirrored serial output
    [GPAD_API.ino]
2026-04-20 Add broker console page for MQTT publish and drake status tracking
    [GPAD_API.ino]
2026-04-20 Add multi-topic watch support to broker console
    [GPAD_API.ino]
2026-04-20 Improve broker console topic tracking reliability
    [GPAD_API.ino]
2026-04-21 Fix web UI status fields and broken navigation links
    [GPAD_API.ino]
2026-04-22 guard all DFPlayer runtime functions with isDFPlayerDetected to prevent main loop blocking
    [DFPlayer.cpp]
2026-04-23 Fixing the DFPlayer Mini detected! message reported.
    [DFPlayer.cpp]
2026-04-25 Add runtime MQTT config persistence and broker console topic management
    [GPAD_API.ino]
2026-04-26 Add PMD menu entry and constrain PMD publishing to configured broker topics
    [GPAD_API.ino]
2026-04-26 Unify broker console into PMD UI and add multi-topic publishing
    [GPAD_API.ino]
2026-04-26 rmeoving the broker console.
    [GPAD_API.ino]
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2026-04-27 Fix INFO command to report active IP address
    [GPAD_HAL.cpp]
2026-04-28 Added Reset Option to GPAD API
    [GPAD_HAL.cpp]
2026-04-29 fix: add early-return on begin() failure, UART noise guard, and silent recovery restart
    [DFPlayer.cpp]
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2026-05-02 Fix mute timeout auto-unmute behavior
    [GPAD_HAL.cpp]
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2026-05-02 Fix timed unmute expiry check using elapsed millis
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2026-05-03 Fix MQTT command handling by removing fragile GPAP deserialize gate
    [GPAD_HAL.cpp]
2026-05-03 Throttle serial burst handling to prevent WDT resets
2026-05-03 Rate-limit annunciation path to reduce WDT/software resets
    [GPAD_HAL.cpp]
2026-05-03 Add forward declaration for reset reason helper
    [GPAD_HAL.cpp]
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2026-05-04 Remove broker console UI and fix ACK/ALM mapping in Settings
    [GPAD_API.ino]
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2026-05-04 Revert "Add Broker Console UI and refactor settings to use KrakeUI helpers"
    [GPAD_API.ino]
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2026-05-30 Add safe LittleFS diagnostics and mount failure handling
    [GPAD_API.ino, WiFiManagerOTA.cpp]
2026-05-30 Simplify fixed Krake PubInv broker handling
    [GPAD_API.ino, GPAD_HAL.cpp]
2026-05-30 Bound WiFi recovery so LittleFS uploads cannot stall startup
    [WiFiManagerOTA.cpp]
2026-05-31 Fix GPAD stylesheet source serving
    [GPAD_API.ino]
2026-05-31 Fix Chrome access and add retained MQTT clearing
    [DFPlayer.cpp, GPAD_API.ino, GPAD_HAL.cpp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]
2026-05-31 Reset LCD frames after inactivity
    [DFPlayer.cpp, GPAD_API.ino, GPAD_HAL.cpp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]
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2026-06-11 WiFiManager captive-portal saves only logged the SSID. I fixed that so portal-saved SSID/password now go through the same saveCredentials() path. Firmware versioning fix: now creates Bump GPAD firmwa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
    ''
    [GPAD_API.ino, WiFiManagerOTA.cpp]
2026-07-11 Add second-pass diagnostic analysis for Krake docs
    Added second-pass diagnostic analysis for Krake documentation, including fact conflicts, structural gaps, and recommendations for fixes.
    Supersedes pass 1 for the Assembly/Test doc source; see pass 1 for full history.
    This analysis was made by Claud in Lee's account.
    URL: https://claude.ai/chat/9869bbf9-06e9-45d9-a90c-6de68d985a55
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2026-07-11 Update documentation for Krake hardware specifications
    Resolved discrepancies in documentation regarding physical dimensions, power draw, firmware version, and PCB revision. Added recommendations for naming strategy for future applications using Krake hardware.
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2026-07-27 Replace speaker entry with Cricklewood Electronics details
    Updated BOM with specific details and confirmed working unit.
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2026-08-01 Correct links for Krake assembly instructions
    Fixed links to the Krake Test and Assembly Procedure Document in the README.
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2026-10-13 Revise README for clarity and feature updates
    Updated the README to clarify device capabilities, improve descriptions of features, and correct formatting issues.
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

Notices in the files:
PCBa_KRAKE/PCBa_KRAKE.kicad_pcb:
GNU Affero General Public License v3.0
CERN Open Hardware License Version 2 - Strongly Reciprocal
